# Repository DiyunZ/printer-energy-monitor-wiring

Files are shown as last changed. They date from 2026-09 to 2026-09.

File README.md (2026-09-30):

# Printer energy monitor

Interactive wiring, 3D enclosure layout and materials for one 120 V printer using a DENT ELITEpro XC.

[Website](https://diyunz.github.io/printer-energy-monitor-wiring/) · [Purchase list](https://diyunz.github.io/printer-energy-monitor-wiring/#hardware) · [School purchase request](https://diyunz.github.io/printer-energy-monitor-wiring/purchase-request.html) · [Build documents](https://diyunz.github.io/printer-energy-monitor-wiring/documents.html)

## Local preview

```sh
python3 -m http.server 8770
```

Open [localhost:8770](http://localhost:8770/).

Source files, rebuild commands and checks: [Development guide](docs/DEVELOPMENT.md).

GitHub Pages publishes the repository root on `main`. Hardware checks remain open in the [installation audit](https://diyunz.github.io/printer-energy-monitor-wiring/installation.html).

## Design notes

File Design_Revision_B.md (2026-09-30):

# Selected design, material costs and sellers

**BUD NBF-32226 clear-cover enclosure + Phoenix 2907571 + flat bridge on 65 mm posts. Estimated materials: $273.00 from DigiKey and Home Depot.** Cut and drill only; no bending. Whole purchase packs, minimum order lengths and spare pieces are counted. Shipping, tariffs, sales tax, fabrication and labor are excluded.

## Material total

| Seller | Materials |
|---|---:|
| DigiKey | $175.37 |
| Home Depot | $97.63 |
| **Total** | **$273.00** |

| Change from the previous $233.54 Phoenix plan | Materials change |
|---|---:|
| Clear-cover NBF-32226 $111.88 replaces out-of-stock NBF-32126 $90.81 | +$21.07 |
| Two 65 mm posts $2.78 + four M5 screws $1.95 + eight M5 washers $5.94 | +$10.67 |
| Two Heyco M3231 glands and two 8463 nuts $3.52 replace factory-stock Hammond glands $5.94 | −$2.42 |
| **Net change** | **+$29.32** |

That design revision produced the previous **$262.86** snapshot. The purchase-form verification on September 29 adds **$10.14**, with the same parts and sellers:

| Current price / order correction | Materials change |
|---|---:|
| Black wire: 6 ft × $0.95; green wire: 6 ft × $0.91. Both online minimums are 6 ft; previous estimate used 4 ft × $0.42 per color. | +$7.80 |
| M5 × 10 screws: two 2-piece packs at $2.97, previously $1.25 per pack | +$3.44 |
| M3 × 12 and M4 × 10 screws: two packs each at $1.95, previously $1.75 | +$0.80 |
| SJOOW cord, supply plug and VELCRO roll at current prices | −$1.72 |
| DigiKey 4692 ten-piece tier and current 4705 unit price | −$0.18 |
| **Net change from $262.86** | **+$10.14** |

Q0 remains **$21.57**. The full 250 mm rail is **$4.79** and two stops **$1.24**; breaker plus rail/stops is **$27.60**, included above. The increase purchases a direct-stock transparent-cover box and eliminates sheet bending; it is not an increase in the breaker price. The earlier $246.94 Carling plan used different stock assumptions and three retailers and is not a current like-for-like order.

<h2 id="breaker-options">Selected two-retailer arrangement</h2>

Keep **Phoenix 2907571 / TMC 81C 15A**, 15 A, 1 pole, C curve, UL489 / cUL Listed E320373, 277 V AC, 10 kA. On September 29 DigiKey showed **3,689 direct-stock units at $21.57**; the clear case showed **103 at $111.88**. Factory and Marketplace inventory are excluded. [Q0](https://www.digikey.com/en/products/detail/phoenix-contact/2907571/6109707) · [clear case](https://www.digikey.com/en/products/detail/bud-industries/NBF-32226/2328561).

The flat 88 × 40 mm aluminum bridge uses two purchased M5 posts. The post hardware is additional to the four M5 × 10 panel screws. The actual manufacturer Q0 model sets the front window and terminal approaches; the bridge, posts and rail are placed in the case's 1° wall frame. [Assembly, screw stacks and receiving checks](build.html#q0-mount).

<h2 id="checkout">Price and stock basis</h2>

All 33 unit prices and retailer descriptions were checked September 29 for the selected quantities. Home Depot prices use Champaign / ZIP 61820. **Three cut-to-length wire lines require store pickup; delivery is unavailable.** Arrange collection before submitting the request. Black and green wire orders are 6 ft each to meet the current online minimum; the installation cutting allowance remains 1 m each. $273.00 is a product-page estimate, not a cart quote or reserved stock. Older stock snapshots retain their dates in the [order plan](materials.html#order-plan). No order has been placed. Offered aluminum is counted as no purchased stock; confirm its actual availability and thickness.

The [purchase request page](purchase-request.html) reproduces retailer descriptions and maps selling units to the school menu. Its [Excel download](downloads/purchase-request.xlsx) separates DigiKey and Home Depot. Consumable / under-one-year classification is **Professor to confirm**; the new assembly uses physical goods, so repair/service is No and No Delivery Expected remains unchecked.

## Model and photo evidence

The purchase list uses real product photos; manufacturer family images are labeled. Flat aluminum fabrication parts use labeled CAD drawings. BUD's linked series STEP and Phoenix's exact 2907571 STEP remain at original millimetre scale. Catalog-dimensioned parts and flexible cables are distinguished from manufacturer solids in the dimension schedule. Closed mode renders a genuinely clear cover and opaque walls; X-ray additionally fades the walls. The digital fit checks do not replace full handle travel, receiving measurements or qualified electrical acceptance.

## Certification evidence

| Part | Evidence available | What remains |
|---|---|---|
| BUD NBF-32226 | [Manufacturer listing](https://www.budind.com/product/nema-ip-rated-boxes/nbf-series-fiberglass-enclosure/nbf-32226/): UL508; NEMA 1, 2, 4, 4X for the unmodified enclosure; ABS/PC body UL94-5VA; clear PC lid UL94-V0, indoor use | Confirm received label and exact variant. Machining and custom assembly do not inherit a finished-product listing. |
| Phoenix Contact TMC 81C 15A / 2907571 | [Exact manufacturer product](https://www.phoenixcontact.com/en-us/products/thermomagnetic-device-circuit-breakers-tmc-81c-15a-2907571): UL489 / cUL Listed E320373; 15 A, 1 pole, C curve, 277 V AC, 10 kA | Verify receiving marks, startup suitability, available fault current and original voltage-lead protection. |
| Leviton 515PV / 515CV | [515PV manufacturer page](https://leviton.com/products/515pv) and [515CV](https://leviton.com/products/515cv): UL498 File E13393; CSA C22.2 No.42 File LR-406 | Confirm received markings, approved cord preparation and clamp. |
| Southwire internal wire | [UL/cUL product description](https://www.southwire.com/wire-cable/building-wire/thhn-thwn-copper-silicone-free/p/22955984) | Check markings on actual stock and accepted wiring method. |
| WAGO 221-415 | [Manufacturer datasheet, p.5, distributor-hosted](https://www.netxl.com/wago/docs/221-415-data-sheet.pdf): UL486C cULus Listed E69654; UL467 E201573 | Apply the exact conductor and installation conditions; confirm received marks. Carrier 221-505 is a mechanical accessory. |
| Heyco M3231 + 8463 cordgrips / nuts | [Manufacturer series](https://www.heyco.com/products/liquid-tight-cordgrips/nylon-cordgrips/heyco-tite-liquid-tight-cordgrips-straight-thru-npt-hubs/): UL514B E51579 / CSA 93876; 1/2 NPT, 15.5 mm thread | Accept exact UL cord range, clamp, sealing and locknut engagement. |
| Southwire 558086 cord | [Manufacturer cable specification](https://cabletechsupport.southwire.com/en/tile/1/cable/7386/): UL62 / CSA C22.2 No.49; E46194 / LL90458 | Verify actual jacket marks and installation method. |
| Gardner Bender 15-104 rings | [Exact manufacturer product](https://www.gardnerbender.com/en/p/15-104/-16-14-AWG-2-mm-sq-Bnes-%C3%A0-anneau): UL Listed, CSA Listed, 600 V building wire, 75°C; #8–10 studs and 16–14 AWG | Certification wording is resolved for the replacement. Actual crimp tooling/fit and the aluminum bond still require acceptance; the manufacturer page does not publish a barrel-insulation diameter. |
| Custom aluminum and mechanical restraints | Material/interface review, not standalone equipment certification | Record stock and bonding method; verify retention, stiffness and temperature. Straps are not electrical insulation. |

UL Listed, UL Recognized, a material flammability rating and an IEC standard are different evidence. The website records the specific evidence instead of showing a blanket “certified” badge. No assembled-product certification is claimed.

## Before fabrication and use

The digital checks cover nominal solids, panel insertion, component placement and sampled cable routes. They do not verify actual scrap thickness, connector fit, plug retention, lid access protection or closed-box temperature. Record those checks and electrical acceptance in the [receiving record](build.html#receiving-record). The original voltage leads' protection and aluminum-compatible PE bond remain review items.

[Materials](materials.html) · [Machining and assembly](build.html) · [Protection review](protection.html) · [3D and wiring](index.html)

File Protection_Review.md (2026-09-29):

# Protection and data review

September 28, 2026 · 120 V grounded supply · one printer at a time.

**Q0 and voltage-lead protection still need acceptance.** The checks below resolve published component ratings and fit. Actual outlet fault current, combined startup duty and protection of the existing voltage leads remain unverified. No hardware test or qualified acceptance has been recorded.

| Item | Verified | Decision |
|---|---|---|
| Q0, Phoenix 2907571 | 15 A, 1 pole, C curve; UL489 / cUL Listed E320373; 277 V AC; 10 kA | Selected from DigiKey at a material price of $21.57. Startup and original voltage-lead protection require application acceptance. |
| Voltage tap | A1 connects to JL after Q0; no dedicated fuse | Confirm that upstream Q0 protection is suitable for the original DENT leads before energizing. |
| USB cable | Existing A-to-B cable confirmed owned | Reuse intact through one protected wall opening. Keep its internal portion sleeved and restrained; connect the free USB-A end to the PC only after unplugging mains. |
| Internal adapter power | XA 515CV + original CUI cable, entirely inside | No DC extension or wall feedthrough. Verify plug retention and closed-enclosure temperature. |

The [material-cost comparison](revision.html#breaker-options) includes the breaker, rail, end stops and purchased fastener packs. Shipping, tariffs, sales tax, fabrication and labor are excluded from the selection total. Two sellers remain: DigiKey and Home Depot.

## Q0: what the rating proves

The selected **Phoenix Contact TMC 81C 15A / 2907571** is a 15 A, one-pole, C-curve thermal-magnetic breaker, with UL489 / cUL Listed file E320373, 277 V AC and 10 kA interrupting rating. Its catalog envelope is 17.6 × 116 × 75.9 mm including the DIN rail. The specified screw connection accepts the selected 14 AWG copper conductor; strip 11–12 mm and tighten to 2 N·m. [Phoenix exact product and characteristic curve](https://www.phoenixcontact.com/en-us/products/thermomagnetic-device-circuit-breakers-tmc-81c-15a-2907571).

The former Carling delay-24 pulse specification does **not** apply. Review actual startup amplitude, duration, repetition, ambient temperature and sustained current against Phoenix's published C characteristic. A C-curve label alone is not proof that the printer will start without tripping. Do not raise the 15 A limit to hide nuisance trips.

The application check still needs the **available RMS symmetrical fault current at the actual receptacle** and the combined startup waveform of the selected printer, adapter and logger. An upstream breaker's marked interrupting rating is not a measurement of available fault current. The breaker rating is also not the short-circuit rating of this complete custom enclosure.

### Jackson Innovation Studio

UIUC identifies JIS as **Room 0100, lower level of Sidney Lu Mechanical Engineering Building**. The F&S building list identifies the building as **0112, 1206 W Green St, Urbana**. [MakerWorks location](https://mechse.illinois.edu/undergraduate/makerworks), [F&S building register](https://fs.illinois.edu/building-list-a-z).

The public pages and renovation summaries inspected do not supply the chosen outlet's circuit number, panel schedule or fault-current calculation. That absence is a limit of this public search, not evidence of a safe numerical value. The studio's published contact is **mechse-makerworks@illinois.edu**; it can route a request to the responsible building/facilities staff. [JIS contact page](https://mechse.illinois.edu/undergraduate/makerworks/jackson-innovation-studio).

**Request to pass to JIS / Facilities — draft, not sent:**

> For a proposed 120 V printer-energy measurement box in JIS, Room 0100, could the responsible electrical staff identify the intended receptacle and its panel/circuit, and confirm the maximum available RMS symmetrical fault current there? The proposed breaker is Phoenix TMC 81C 15A / 2907571, 15 A UL489, rated 10 kA at 120 V AC. Please review the complete assembly's protection and supply suitability; the breaker rating alone is not an assembly SCCR. If a current study is unavailable, please advise the appropriate engineering assessment. We do not need to access or open energized panels ourselves.

### Printer startup evidence

| Printer | Published operating information | Limit of the check |
|---|---|---|
| UltiMaker S5 | 100–240 V AC, 50/60 Hz, 500 W maximum | About 4.17 A at 120 V **only at unity power factor**; this is not a nameplate current or startup waveform. [S5 manual](https://um-support-files.ultimaker.com/manuals/user-manual/S3-%26-S5/Ultimaker%20S3-S5%20-%20User%20manual%20ENv2.4.pdf). |
| Bambu Lab P2S | LV version: 100–120 V AC; 1000 W at 110 V during preheating | About 9.09 A at 110 V **only at unity power factor**. Minutes of heating load do not specify millisecond inrush. [P2S quick-start guide](https://csm.bblcdn.com/hub/0a3c3e8ab9554a5c9c91815e41540f42.pdf). |
| Prusa CORE One+ | The listed compatible Gen1 PSU is 24 V DC / 240 W | Its 10 A output is **DC output**, not AC input. Match the actual PSU version; no complete printer inrush waveform was found. [Prusa PSU listing](https://www.prusa3d.com/product/psu-24v-240w/). |

Manufacturer data for startup amplitude, duration, repetitions, input voltage and temperature—or a suitably captured waveform reviewed against the breaker curve—is needed to close the startup comparison. Ordinary logged averages and a single successful power-on do not establish that comparison. Request the actual printer/PSU startup specification; do not increase the breaker rating merely to avoid trips.

## Voltage tap: upstream protection review

The design omits Fv, its holder and JV. The short DIN rail and stops now support Q0 only; they do not add voltage-lead protection. The hot sensing path is **Q0 → JL → original DENT A1 pigtail → full voltage lead → ELITEpro L1**. L2 and N remain connected to neutral. The adapter and voltage tap branch off before CT; only printer hot passes through CT. The sensing leads do not carry printer load current.

The user confirms the three differently colored pigtails as original DENT kit components, matched to the LD-SKTSP family. DENT lists these leads for hard-wiring and also offers standard non-fused and optional fused clips. That does not establish that this custom enclosure and its 15 A breaker adequately protect the original lead set. [DENT pigtails](https://www.dentinstruments.com/shop/elitepro-accessories-replacement-parts/replacement-unterminated-voltage-leads-10-for-elitepro-series/), [DENT clip options](https://www.dentinstruments.com/shop/elitepro-accessories-replacement-parts/replacement-fused-crocodile-clip/).

**Before energizing:** the responsible electrical reviewer must accept the upstream-only protection scheme, original lead terminations and installation conditions. No such acceptance or physical test is recorded. The ELITEpro's internal fuse cannot clear a short in an external lead that bypasses the instrument. Removing Fv does not validate Q0 or establish the assembly's short-circuit rating.

**Manufacturer question — draft, not sent:**

> For our proposed 120 V measurement enclosure, may original DENT LD-SKTSP pigtails and voltage leads connect to a circuit protected by a Phoenix TMC 81C 15A / 2907571 15 A breaker without a dedicated voltage-tap fuse? A1 feeds L1 from switched hot; L2 and N connect to neutral. Please confirm the permitted upstream protection and terminal preparation, or identify any additional protection required. The original 9 V adapter is also powered from the switched circuit.

The [Q0 purchase link](https://www.digikey.com/en/products/detail/phoenix-contact/2907571/6109707) identifies the selected product. Exact-SKU stock, site fault-current suitability and startup behavior remain to be confirmed.

## Experiment data workflow

Use **standalone logging during prints, then offline batch downloads**. Synchronize the logger clock and job/phase timestamps before the series. Keep the same validated interval for comparisons and check memory capacity. Preserve raw exports before clearing memory.

The DENT manual identifies non-volatile memory, included USB and USB-powered readout. It also requires rated insulation for the supplied USB cable inside a powered electrical panel. The user selected closed-lid offline export. One existing cable remains connected to DENT and passes directly through a Heyco 3104 bushing. Disconnect its free exterior USB-A end from the PC before mains operation. The internal portion retains the black FIT-221 600 V sleeve and accepted end protection, restraint and application process. The bushing and sleeve are not a mains isolation barrier. See [USB construction and acceptance](build.html). [DENT manual, printed pp. 7, 18, 29, 119](https://www.dentinstruments.com/wp-content/uploads/EXC_ELOG19_11-15-24.pdf).

Prove the setup with one supervised print cycle and offline export, including startup, phase timestamps, final records and restart behavior, before collecting the experimental series. The website does not claim that physical validation has happened. [Operating sequence](documents.html#operation).

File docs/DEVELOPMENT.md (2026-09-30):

# Development

Run commands from the repository root. The checked-in site can be served with Python alone; Node dependencies are only needed to regenerate documents or run browser checks.

## File map

| Location | Purpose |
|---|---|
| `procurement.json` | Materials, ownership, prices, photos and purchase links |
| `purchasing.rows[].request` in `procurement.json` | Exact retailer Description/title, ordering identifier, matched listing photo and verification date |
| `tools/purchase_request.cjs`, `purchase-request.js`, `purchase-request.css` | Shared purchase-form mapping, generated page and clipboard interaction |
| `tools/export_purchase_request.mjs`, `downloads/purchase-request.xlsx` | Excel generator and its two-vendor download |
| `layout_dimensions.json` | Shared dimensions, placement and provenance |
| `installation_review.json` | Review evidence and outstanding hardware checks |
| `build_routes.py`, `draw_external.py`, `page_template.html` | Generate the main page, circuit drawings, `routes.json` and `validation.json` |
| Root `.js` / `.css` files | Website interactions, 3D geometry and styling |
| Root `.md` files | Engineering documents; BOM, audit and document index are generated |
| `tools/` | Document generators and verification scripts |
| `tools/cad/` | Parametric machining and drawing generators |
| `assets/`, `vendor/` | Model meshes, current material images and licensed Three.js modules |
| `fabrication/` | Published STEP, STL, DXF, SVG and PDF downloads |

Root HTML files and generated artifacts are committed because GitHub Pages serves them directly. Edit their source files and regenerate them. Keep existing page and download URLs working.

## Setup and rebuild

Verified Node dependencies: Node 24, `marked` 17.0.5 and Playwright 1.62.1.

```sh
npm install --no-save --package-lock=false marked@17.0.5 playwright@1.62.1
npx playwright install chromium
python3 build_routes.py
node tools/render_documents.cjs
```

`render_documents.cjs` regenerates `Procurement_BOM.md`, `Installation_Audit.md`, `Build_Documents.md`, `purchase-request.html` and all supporting HTML pages. Other engineering Markdown files are maintained directly.

For the Excel download, use the bundled `@oai/artifact-tool` runtime located by `load_workspace_dependencies`. Create a temporary `node_modules` symlink to that runtime, set `ARTIFACT_WORKDIR` to the temporary directory and run `node tools/export_purchase_request.mjs` using the bundled Node executable. `REQUEST_OUTPUT` optionally sets the artifact output directory. The generator checks calculations and source strings, renders both worksheets for inspection, exports one workbook and copies it to `downloads/purchase-request.xlsx`. Rebuild the workbook and HTML together after changing order fields or prices. `python3 tools/check_purchase_workbook.py` checks the saved export against current procurement data.

Copy DigiKey's **Description**, not Detailed Description, and Home Depot's visible product title without rewording. Record the seller order number separately from the manufacturer/model. Preserve fractional-cent price tiers. Packs and rolls map to the school unit `each`; by-the-foot purchases map to `feet`. Keep the consumable classification unresolved until the professor confirms it. Retailer minimums affect ordered quantities, not installation cutting allowances. Do not use a new description-check date to relabel an old stock snapshot as current.

## Checks

```sh
python3 -m unittest -v test_routes.py test_material_locations.py
node --test tools/test_installation.mjs tools/test_cable_supports.mjs tools/test_purchase_request.mjs
python3 -m http.server 8770
```

With the server running, use a second terminal:

```sh
export CHECK_URL=http://127.0.0.1:8770/
export QA_OUTPUT=../outputs/website-checks
node tools/verify_site.cjs
```

Run focused browser checks when their features change:

| Script | Coverage |
|---|---|
| `tools/verify_material_locator.cjs` | Material links, mesh ownership, locations and navigation |
| `tools/verify_wiring.cjs` | Circuit labels, endpoints, pan, zoom and fullscreen |
| `tools/verify_usb_service.cjs` | Closed-lid USB export workflow and connector links |
| `tools/verify_cable_geometry.cjs` | Supports, cable separation, CT passage and cord breakouts |

After geometry changes, `node tools/audit_installation.mjs` refreshes `installation_checks.json`. On the local server, `EXPORT_AUDIT=1` with `verify_site.cjs` or `verify_cable_geometry.cjs` refreshes the corresponding cable report; `EXPORT_DRAWINGS=1` with `verify_site.cjs` refreshes the two PNG drawings. Rerun `render_documents.cjs` after updating audit data. Review generated diffs before committing.

## CAD regeneration

Use Python 3.12 with `build123d==0.11.1`, `ezdxf` and `matplotlib` in a separate environment. Obtain the factory STEP linked on the [BUD NBF-32226 page](https://www.budind.com/product/nema-ip-rated-boxes/nbf-series-fiberglass-enclosure/nbf-32226/). The original vendor file is also saved at `fabrication/bud-nbf32226-reference.step`; its internal filename is hbnbf32026.step. Preserve its hash and original scale.

```sh
python tools/cad/enclosure_model.py --source-step /path/to/NBF-32226.step
python tools/cad/draw_fabrication.py
```

The generator writes the machined solids, assembly meshes (including the flat Q0 bridge, two catalog-dimensioned posts and Phoenix factory model), exact clearance checks and `fabrication/cad-manifest.json` with source/generator/output hashes.

The two end stops use `fabrication/altech-ca802-reference.step` at original scale. OpenCascade reads its CompSolid through `STEPControl_Reader`; the original topology is not valid, so the mesh is visual only and excluded from exact-solid fit checks. The rail seat remains provisional. Do not silently heal or scale vendor geometry to force a pass.

The separate support source is `tools/cad/q0_mount_model.py`, reading `layout_dimensions.json:q0Mount`. With the installed lab-hardware-cad skill, export and independently check its STEP as follows (the skill path can be changed for another workstation):

```sh
python ~/.codex/skills/lab-hardware-cad/scripts/gen.py tools/cad/q0_mount_model.py --outdir fabrication
python ~/.codex/skills/lab-hardware-cad/scripts/check.py geometry fabrication/q0_mount.step --model tools/cad/q0_mount_model.py
```

The sixth drawing and flat DXF are regenerated by `draw_fabrication.py`. The flat bridge needs only cutting and drilling; no bend radius or K-factor is used. Measure actual sheet and washer thicknesses and dry-fit the post/screw stack before machining.

Inspect regenerated CAD and drawings before publication. Software checks do not replace the receiving, fit and electrical checks in the [installation audit](../Installation_Audit.md).

Phoenix factory STEP is preserved at `fabrication/phoenix-2907571-reference.step`; the original vendor SHA256 is recorded in the manifests. Q0 is transformed without scaling into the wall frame. Terminal channels in `layout_dimensions.json` bound the cable-screen exception; independent 3.4 mm wire gauges check the actual manufacturer cavities. Clearance booleans use non-destructive OpenCascade common operations to avoid cleanup artifacts in vendor topology.

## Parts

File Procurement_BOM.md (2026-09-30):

# Materials checklist

**□ 19 purchase groups · ◇ 2 reuse / fabrication group · ✓ 6 confirmed owned groups**

One grounded 120 V supply, one printer at a time. The design uses a clear-cover BUD NBF-32226 enclosure, proposed reuse of the professor’s aluminum sheet and an internal adapter connection. Six owned equipment groups, including the existing USB cable, are retained. The selected 15 A Q0 and upstream-only voltage-lead protection still require application acceptance. No purchase, physical fit, thermal test or electrical release is claimed. Closed-lid USB export is used only after unplugging mains; the internal portion of the existing USB cable requires rated insulation and accepted assembly.

**Inventory basis:** Six equipment groups are confirmed owned by the user: ELITEpro XC, CTs, three original kit pigtails, matching long voltage leads, original adapter and USB data cable. Reuse the existing USB cable intact. The design uses published USB-B overmold limits and a standard cable-diameter range; final passage, insulation and restraint are checked during assembly.

A check means on hand, not electrically approved. Counts refer to material groups, not individual pieces. Needed quantities and vendor pack sizes differ. The user confirms the existing USB cable is owned. Reuse it intact; no additional data cable or USB coupler is ordered.

Buy links go to specific products; Select / Configure links need a size or rating first; Quote links require a supplier quote. Reused stock and fabrication are listed separately from purchases. Check current stock, minimum orders and lead times with each supplier. No orders have been placed.

**[Prepare the school purchase request](purchase-request.html)** — exact retailer descriptions, per-field copy buttons and a [two-vendor Excel download](downloads/purchase-request.xlsx).

Purchased groups show real manufacturer or distributor product photos. Family photos are identified; the two custom aluminum parts use labeled CAD drawings. Photos are not to scale; the 3D layout uses millimetres. Click an image to view the original. Use **View in 3D** to highlight each material’s installation locations. Image sources are credited below each picture.

<h2 id="order-plan">Priced order plan · $273.00 materials</h2>

Checked 2026-09-29. Materials only, including whole packs, minimum order lengths and spare pieces. All unit prices rechecked September 29 at the selected quantities; Home Depot uses Champaign / ZIP 61820. Shipping, tariffs, sales tax, fabrication and labor are excluded. Stock snapshots retain their separate per-line dates.

Two sellers only: DigiKey and Home Depot. Selected DigiKey parts must be DigiKey direct stock; Marketplace, manufacturer direct shipping and factory-only stock are excluded. No fee per retailer is added.

| Seller / exact item | Quantity to enter | Unit price (USD) | Line total (USD) | Availability / packaging |
|---|---|---|---|---|
| DigiKey · [NBF-32226](https://www.digikey.com/en/products/detail/bud-industries/NBF-32226/2328561) | 1 each | $111.88<br>Price checked 2026-09-29 | $111.88 | 103 in DigiKey direct stock; 377-1789-ND; clear PC cover. Stock / packaging note dated 2026-09-29. |
| DigiKey · [2907571 · TMC 81C 15A](https://www.digikey.com/en/products/detail/phoenix-contact/2907571/6109707) | 1 each | $21.57<br>Price checked 2026-09-29 | $21.57 | 3,689 in DigiKey direct stock, quantity-one price; factory stock excluded. Stock / packaging note dated 2026-09-29. |
| Home Depot · [515CV](https://www.homedepot.com/p/301304939) | 2 each | $6.99<br>Price checked 2026-09-29 | $13.98 | One internal XA and one printer output; buy two total Stock / packaging note dated 2026-09-23. |
| DigiKey · [221-415](https://www.digikey.com/en/products/detail/wago-corporation/221-415/13549457) | 3 each | $1.17<br>Price checked 2026-09-29 | $3.51 | 171,735 listed in stock; 2946-221-415-ND Stock / packaging note dated 2026-09-23. |
| DigiKey · [221-505](https://www.digikey.com/en/products/detail/wago-corporation/221-505/15568477) | 3 each | $2.23<br>Price checked 2026-09-29 | $6.69 | 2,982 listed in stock; 2946-221-505-ND Stock / packaging note dated 2026-09-23. |
| Home Depot · [55808699 · 14/3 SJOOW](https://www.homedepot.com/p/Southwire-By-the-Foot-14-3-300-Volt-CU-Black-Flexible-Portable-Power-SJOOW-Cord-55808699/204633006) | 13 ft | $1.46<br>Price checked 2026-09-29 | $18.98 | Minimum 6 ft; order one continuous 13 ft length. Champaign pickup only; delivery unavailable for ZIP 61820. Stock / packaging note dated 2026-09-29. |
| Home Depot · [515PV-YL](https://www.homedepot.com/p/Leviton-15-Amp-125-Volt-3-Wire-Plug-Yellow-515PV-YL-R10-515PV-0YL/309610976) | 1 each | $3.65<br>Price checked 2026-09-29 | $3.65 | Store / delivery availability varies Stock / packaging note dated 2026-09-23. |
| DigiKey · [M3231 · long-thread 1/2 NPT cordgrip](https://www.digikey.com/en/products/detail/heyco-products-corporation/M3231/15906457) | 2 each | $1.44<br>Price checked 2026-09-29 | $2.88 | 13,830 DigiKey direct stock; separate 8463 locknut required. Stock / packaging note dated 2026-09-29. |
| Home Depot · [22955999 · black 14 AWG stranded](https://www.homedepot.com/p/204632031) | 6 ft | $0.95<br>Price checked 2026-09-29 | $5.70 | Minimum online order 6 ft; one continuous length, with spare wire beyond the 1 m cutting allowance. Champaign pickup only; delivery unavailable for ZIP 61820. Stock / packaging note dated 2026-09-29. |
| Home Depot · [22959199 · green 14 AWG stranded](https://www.homedepot.com/p/204632154) | 6 ft | $0.91<br>Price checked 2026-09-29 | $5.46 | Minimum online order 6 ft; one continuous length, with spare wire beyond the 1 m cutting allowance. Champaign pickup only; delivery unavailable for ZIP 61820. Stock / packaging note dated 2026-09-29. |
| Home Depot · [15-104 · 15 terminals](https://www.homedepot.com/p/202522492) | 1 pack (15 pieces per pack) | $3.63<br>Price checked 2026-09-29 | $3.63 | 15 pieces supplied for a single pack price Stock / packaging note dated 2026-09-23. |
| DigiKey · [TM2S8-C](https://www.digikey.com/en/products/detail/panduit-corp/TM2S8-C/1306625) | 6 each | $0.68<br>Price checked 2026-09-29 | $4.08 | 14,724 listed in stock; 298-10245-ND; individual pieces Stock / packaging note dated 2026-09-23. |
| DigiKey · [PLT2S-C](https://www.digikey.com/en/products/detail/panduit-corp/PLT2S-C/280043) | 10 each | $0.316<br>Price checked 2026-09-29 | $3.16 | 113,092 listed in stock; 298-1030-ND; ten-piece price tier Stock / packaging note dated 2026-09-23. |
| Home Depot · [90340 · 12 ft × 3/4 in](https://www.homedepot.com/p/202261925) | 1 roll | $10.27<br>Price checked 2026-09-29 | $10.27 | One roll supplies four blanks totaling 1.30 m Stock / packaging note dated 2026-09-23. |
| Home Depot · [837761 · M3-0.5 × 12 zinc pan screws](https://www.homedepot.com/p/321071719) | 2 pack (4 pieces per pack) | $1.95<br>Price checked 2026-09-29 | $3.90 | 6 carrier fixings installed; buy 8, retain 2 spare. Q0 now uses M5 posts. Stock / packaging note dated 2026-09-24. |
| DigiKey · [4692 · M3 / #4 zinc-plated steel flat washers](https://www.digikey.com/en/products/detail/keystone-electronics/4692/316261) | 10 each | $0.084<br>Price checked 2026-09-29 | $0.84 | 6 carrier washers installed; retain 4 spare from the ten-piece price tier. Stock / packaging note dated 2026-09-23. |
| Home Depot · [837221 · M3-0.5 stainless locknuts](https://www.homedepot.com/p/321071866) | 2 pack (4 pieces per pack) | $1.95<br>Price checked 2026-09-29 | $3.90 | 6 carrier fixings installed; buy 8, retain 2 spare. Q0 now uses M5 posts. Stock / packaging note dated 2026-09-23. |
| Home Depot · [836351 · M4-0.7 × 10 zinc pan screws](https://www.homedepot.com/p/321071623) | 2 pack (4 pieces per pack) | $1.95<br>Price checked 2026-09-29 | $3.90 | 6 cable anchors + 1 DIN rail fixing; 8 purchased, 7 installed. Stock / packaging note dated 2026-09-24. |
| Home Depot · [4118 · M4 stainless flat washers](https://www.homedepot.com/p/204801237) | 1 pack (50 pieces per pack) | $4.96<br>Price checked 2026-09-29 | $4.96 | 6 anchor washers + 3 rail spacer/head/nut washers; 50-piece pack covers all. Stock / packaging note dated 2026-09-23. |
| Home Depot · [837171 · M4-0.7 stainless locknuts](https://www.homedepot.com/p/321071795) | 2 pack (4 pieces per pack) | $1.95<br>Price checked 2026-09-29 | $3.90 | 6 cable anchors + 1 DIN rail fixing; 8 purchased, 7 installed. Stock / packaging note dated 2026-09-23. |
| DigiKey · [9911 · #10-32 × 3/4 stainless pan screws](https://www.digikey.com/en/products/detail/keystone-electronics/9911/317331) | 2 each | $0.39<br>Price checked 2026-09-29 | $0.78 | Two dedicated #10 bond studs: panel and Q0 rail/bracket. Stock / packaging note dated 2026-09-23. |
| DigiKey · [4705 · #10-32 zinc-plated steel plain nuts](https://www.digikey.com/en/products/detail/keystone-electronics/4705/316276) | 4 each | $0.12<br>Price checked 2026-09-29 | $0.48 | Two PE bond stacks; all 4 purchased pieces installed. Stock / packaging note dated 2026-09-23. |
| Home Depot · [827311 · #10 zinc-plated external-tooth washers](https://www.homedepot.com/p/317479556) | 1 pack (18 pieces per pack) | $1.57<br>Price checked 2026-09-29 | $1.57 | 5 PE-stud contacts + 6 proposed M5 post contact/retention washers; 18-piece pack. Verify M5 fit and approved bonding stack. Stock / packaging note dated 2026-09-23. |
| DigiKey · [4703 · #10 zinc-plated steel flat washers](https://www.digikey.com/en/products/detail/keystone-electronics/4703/316274) | 4 each | $0.13<br>Price checked 2026-09-29 | $0.52 | Two PE bond stacks; all 4 purchased pieces installed. Stock / packaging note dated 2026-09-23. |
| Home Depot · [863468 · M5-0.8 × 10 stainless pan screws](https://www.homedepot.com/p/323370995) | 2 pack (2 pieces per pack) | $2.97<br>Price checked 2026-09-29 | $5.94 | Panel mounting; 4 screws supplied and installed. Not included with the enclosure. Store price / delivery varies by location. Stock / packaging note dated 2026-09-24. |
| DigiKey · [F2213/4 BK105](https://www.digikey.com/en/products/detail/alpha-wire/F2213-4-BK105/3718418) | 1 each | $9.39<br>Price checked 2026-09-29 | $9.39 | F2213/4BK105-ND; 1,182 listed in stock; one 4 ft stick Stock / packaging note dated 2026-09-23. |
| DigiKey · [Heyco 3104](https://www.digikey.com/en/products/detail/heyco-products-corporation/3104/15907204) | 1 each | $0.14<br>Price checked 2026-09-29 | $0.14 | 3720-3104-ND; 6,537 listed in stock; quantity-one price. Verify actual passage and stock at checkout. Stock / packaging note dated 2026-09-23. |
| DigiKey · [1207639 · NS 35/7.5 PERF 250MM](https://www.digikey.com/en/products/detail/phoenix-contact/1207639/10645207) | 1 each | $4.79<br>Price checked 2026-09-29 | $4.79 | 2,061 in DigiKey direct stock; buy full 250 mm rail, cut 60 mm. Stock / packaging note dated 2026-09-29. |
| DigiKey · [CA802](https://www.digikey.com/en/products/detail/altech-corporation/CA802/8547037) | 2 each | $0.62<br>Price checked 2026-09-29 | $1.24 | 6,001 in DigiKey direct stock; two 8 mm end stops. Stock / packaging note dated 2026-09-29. |
| DigiKey · [8463 · 1/2 NPT nylon locknut](https://www.digikey.com/en/products/detail/heyco-products-corporation/8463/15906932) | 2 each | $0.32<br>Price checked 2026-09-29 | $0.64 | 66,153 in DigiKey direct stock; one per M3231. Stock / packaging note dated 2026-09-29. |
| DigiKey · [970650581 · 65 mm M5 steel post](https://www.digikey.com/en/products/detail/w%C3%BCrth-elektronik/970650581/6174896) | 2 each | $1.39<br>Price checked 2026-09-29 | $2.78 | 67 in DigiKey direct stock; 11 mm internal thread per end. Stock / packaging note dated 2026-09-29. |
| Home Depot · [836521 · M5-0.8 × 12 zinc pan screws](https://www.homedepot.com/p/321071519) | 1 pack (4 pieces per pack) | $1.95<br>Price checked 2026-09-29 | $1.95 | Champaign: 8 packs in stock; four screws installed. Stock / packaging note dated 2026-09-29. |
| Home Depot · [864408 · M5 stainless flat washers](https://www.homedepot.com/p/323371831) | 2 pack (4 pieces per pack) | $2.97<br>Price checked 2026-09-29 | $5.94 | Champaign: 4 packs in stock; buy 8 washers, install 6. Stock / packaging note dated 2026-09-29. |

| Seller | Materials subtotal (USD) |
|---|---|
| DigiKey | $175.37 |
| Home Depot | $97.63 |
| **All selected materials** | **$273.00** |

The two 515CV installation rows below share the **single two-piece order line above**. Do not order two for each location. Aluminum stock and electrical acceptance remain open; see the [receiving record](build.html#receiving-record).

**Selection total: $273.00 in materials from 2 sellers.** Compare material costs while minimizing the number of actual sellers. Shipping, tariffs, sales tax, fabrication and labor are excluded. [Material costs and seller comparison](revision.html#breaker-options).

<h2 id="purchase-list">□ Purchase list · 19 groups</h2>

Prices checked 2026-09-29; subtotals include purchase packs and spares. Shared 515CV stock is allocated as one connector per location. [Full order quantities and seller totals](#order-plan).

| Inventory | Item | Quantity needed | Part and purpose | Price & purchase (USD) | Remaining checks |
|---|---|---|---|---|---|
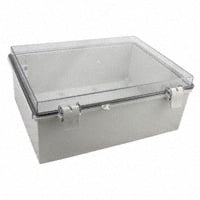
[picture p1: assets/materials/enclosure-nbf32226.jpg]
BUD NBF-32226 clear-cover enclosure — distributor product photo
| □ To buy | <span class="material-name">Enclosure</span><div class="material-gallery"><figure class="material-photo" data-image-kind="product"><figcaption>BUD NBF-32226 clear-cover enclosure — distributor product photo<a href="https://www.digikey.com/en/products/detail/bud-industries/NBF-32226/2328561">Image: DigiKey / manufacturer ↗</a></figcaption></figure></div><a class="locate-material" data-material="enclosure" href="index.html?material=enclosure#layout" aria-label="View Enclosure in 3D">View in 3D ↑</a> | 1 | **BUD NBF-32226 · clear hinged cover** — 400 × 300 × 160 mm ABS/PC box with a clear polycarbonate cover. Same manufacturer base and panel pattern; the exact factory STEP is displayed without scaling. | <div class="material-price" data-material-id="enclosure" data-subtotal-usd="111.88"><strong class="price-total">$111.88</strong> <span class="price-label">subtotal</span><div class="price-breakdown"><p>1 × $111.88 each</p></div></div>[Buy · DigiKey](https://www.digikey.com/en/products/detail/bud-industries/NBF-32226/2328561)<br>[BUD product / standards](https://www.budind.com/product/nema-ip-rated-boxes/nbf-series-fiberglass-enclosure/nbf-32226/)<br>[BUD dimensional drawing](https://www.budind.com/wp-content/uploads/2019/01/hbnbf32226.pdf) | 103 in DigiKey direct stock at $111.88, checked September 29, 2026. Reconfirm at checkout. Received-part fit, latches, access protection and machining acceptance remain required.<br>**Manufacturer listing:** Manufacturer UL508 listing; NEMA 1, 2, 4, 4X for the unmodified enclosure. ABS/PC body UL94-5VA; clear PC door UL94-V0. Machining does not confer a finished-assembly or ingress rating. [Evidence](https://www.budind.com/product/nema-ip-rated-boxes/nbf-series-fiberglass-enclosure/nbf-32226/) |
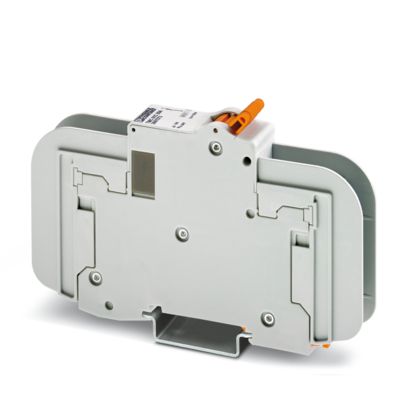
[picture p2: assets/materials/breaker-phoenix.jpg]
Phoenix Contact TMC 81 single-pole breaker family product photo
| □ To buy | <span class="material-name">Q0 operating breaker</span><div class="material-gallery"><figure class="material-photo" data-image-kind="product"><figcaption>Manufacturer family photo; confirm 2907571 / 15 A marking on receipt.<a href="https://www.phoenixcontact.com/en-us/products/thermomagnetic-device-circuit-breakers-tmc-81c-15a-2907571">Image: Phoenix Contact product photo ↗</a></figcaption></figure></div><a class="locate-material" data-material="breaker" href="index.html?material=breaker#layout" aria-label="View Q0 operating breaker in 3D">View in 3D ↑</a> | 1 | **Phoenix Contact TMC 81C 15A · 2907571** — 15 A, one pole, C curve, UL489 / cUL Listed E320373; 10 kA, 277 V AC. Consolidates the breaker into the existing DigiKey order. Manufacturer STEP defines the wall opening, short DIN rail and bonded aluminum bracket. Review the thermal-magnetic curve against startup and original voltage-lead protection. | <div class="material-price" data-material-id="breaker" data-subtotal-usd="21.57"><strong class="price-total">$21.57</strong> <span class="price-label">subtotal</span><div class="price-breakdown"><p>1 × $21.57 each</p></div></div>[Buy 1 · DigiKey · $21.57](https://www.digikey.com/en/products/detail/phoenix-contact/2907571/6109707)<br>[Phoenix specifications, approvals and C curve](https://www.phoenixcontact.com/en-us/products/thermomagnetic-device-circuit-breakers-tmc-81c-15a-2907571)<br>[Manufacturer STEP reference](fabrication/phoenix-2907571-reference.step)<br>[Material costs and seller comparison](revision.html#breaker-options) | DigiKey direct-stock price $21.57, rechecked September 29, 2026. Reconfirm stock at checkout. Full mounting hardware is included in the materials-only total.<br>**UL489 / cUL Listed:** Exact 2907571 product: UL / cUL Listed file E320373, 15 A C curve, 277 V AC, 10 kA. Confirm received markings and application. Component listing is not assembly approval. [Evidence](https://www.phoenixcontact.com/en-us/products/thermomagnetic-device-circuit-breakers-tmc-81c-15a-2907571) |
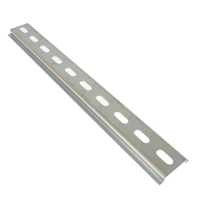
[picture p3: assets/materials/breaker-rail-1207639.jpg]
Phoenix 1207639 — purchased 250 mm rail; cut 60 mm
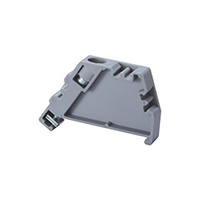
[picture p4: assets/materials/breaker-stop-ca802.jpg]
Altech CA802 — two end stops
| □ To buy | <span class="material-name">Q0 DIN rail and end stops</span><div class="material-gallery"><figure class="material-photo" data-image-kind="product"><figcaption>Phoenix 1207639 — purchased 250 mm rail; cut 60 mm<a href="https://www.digikey.com/en/products/detail/phoenix-contact/1207639/10645207">Image: DigiKey / manufacturer ↗</a></figcaption></figure><figure class="material-photo" data-image-kind="product"><figcaption>Altech CA802 — two end stops<a href="https://www.digikey.com/en/products/detail/altech-corporation/CA802/8547037">Image: DigiKey / manufacturer ↗</a></figcaption></figure></div><a class="locate-material" data-material="breaker-rail" href="index.html?material=breaker-rail#layout" aria-label="View Q0 DIN rail and end stops in 3D">View in 3D ↑</a> | 1 × 250 mm rail; cut 60 mm, plus 2 end stops | **Phoenix Contact 1207639 + Altech CA802 × 2** — 35 × 7.5 × 1 mm galvanized steel rail. Buy the complete 250 mm piece for $4.79; two $0.62 CA802 stops restrain the breaker laterally. The short stock avoids adding a one-metre package to the enclosure shipment. | <div class="material-price" data-material-id="breaker-rail" data-subtotal-usd="6.03"><strong class="price-total">$6.03</strong> <span class="price-label">subtotal</span><div class="price-breakdown"><p><span class="price-sku">1207639 · NS 35/7.5 PERF 250MM</span>1 × $4.79 each = $4.79</p><p><span class="price-sku">CA802</span>2 × $0.62 each = $1.24</p></div></div>[250 mm rail · DigiKey · $4.79](https://www.digikey.com/en/products/detail/phoenix-contact/1207639/10645207)<br>[2 end stops · DigiKey · $0.62 each](https://www.digikey.com/en/products/detail/altech-corporation/CA802/8547037)<br>[Altech stop dimensions](https://legacy.altechcorp.com/Blocks/Block-Accessories.pdf)<br>[CA802 manufacturer STEP (1:1 visual reference)](fabrication/altech-ca802-reference.step) | September 29 direct stock: 2,061 rails and 6,001 stops; $4.79 + 2 × $0.62 = $6.03. Cut and deburr the rail before fitting.<br>**Mechanical accessories:** Manufacturer rail geometry and CA802 compatibility; no separate branch protection function or assembly certification. [Evidence](build.html#q0-mount) |
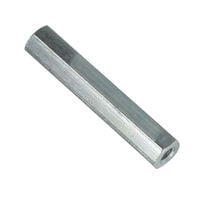
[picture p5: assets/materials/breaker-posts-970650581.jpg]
Würth WA-SSTII family product photo; ordered 970650581 is 65 mm, M5
| □ To buy | <span class="material-name">Q0 threaded support posts</span><div class="material-gallery"><figure class="material-photo" data-image-kind="reference"><figcaption>Würth WA-SSTII family product photo; ordered 970650581 is 65 mm, M5<a href="https://www.digikey.com/en/products/detail/w%C3%BCrth-elektronik/970650581/6174896">Image: DigiKey / manufacturer ↗</a></figcaption></figure></div><a class="locate-material" data-material="breaker-posts" href="index.html?material=breaker-posts#layout" aria-label="View Q0 threaded support posts in 3D">View in 3D ↑</a> | 2 | **Würth 970650581 · M5 female/female · 65 mm** — Two zinc-plated steel SW8 hex posts hold the flat bridge at the required DIN-rail depth. M5 internal thread depth 11 mm per end; no bending or tapping required. | <div class="material-price" data-material-id="breaker-posts" data-subtotal-usd="2.78"><strong class="price-total">$2.78</strong> <span class="price-label">subtotal</span><div class="price-breakdown"><p>2 × $1.39 each</p></div></div>[Buy 2 · DigiKey](https://www.digikey.com/en/products/detail/w%C3%BCrth-elektronik/970650581/6174896)<br>[Würth dimensional drawing](https://www.we-online.com/components/products/datasheet/970xxxxx1_overview.pdf) | 67 in DigiKey direct stock; $1.39 each, checked September 29, 2026. Verify screw engagement, wall loading and accepted PE continuity through the metal support.<br>**Mechanical support:** Published dimensions; PE contact and mechanical retention are assembly acceptance items. [Evidence](build.html#q0-mount) |
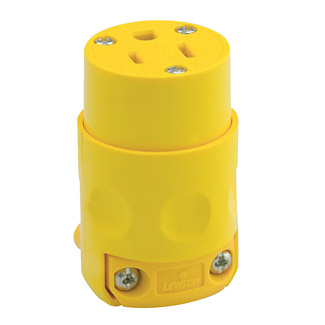
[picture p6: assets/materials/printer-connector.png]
Leviton 515CV · NEMA 5-15R — product image
| □ To buy | <span class="material-name">XA adapter receptacle</span><div class="material-gallery"><figure class="material-photo" data-image-kind="product"><figcaption>Product image<a href="https://leviton.com/products/515cv">Image: Leviton ↗</a></figcaption></figure></div><a class="locate-material" data-material="receptacle" href="index.html?material=receptacle#layout" aria-label="View XA adapter receptacle in 3D">View in 3D ↑</a> | 1 | **Leviton 515CV · internal NEMA 5-15R** — Use a complete cord connector inside the box, matching the printer output connector SKU. A dedicated 14/3 SJOOW branch connects JL/JN/PE to XA upstream of CT. The connector body encloses its terminals and clamps the cord jacket. No wall outlet, custom bracket or wall cutout. | <div class="material-price" data-material-id="receptacle" data-subtotal-usd="6.99"><strong class="price-total">$6.99</strong> <span class="price-label">subtotal</span><div class="price-breakdown"><p>1 × $6.99 each</p></div></div>[Buy · Home Depot · 1 of 2 total](https://www.homedepot.com/p/301304939)<br>[Leviton 515CV](https://leviton.com/products/515cv)<br>[Leviton dimensions](https://leviton.com/content/dam/leviton/residential/product_documents/none/Document-31435-Dimensional%20Data.jpg)<br>[Leviton cord instructions](https://leviton.com/content/dam/leviton/residential/product_documents/instruction_sheet/515_Instruction_Sheet.pdf) | Catalog UL498 File E13393 / CSA LR-406. Verify the cord clamp and secure both XA and the adapter on the panel; plugs remain fully seated.<br>**Manufacturer file identified:** UL498 File E13393; CSA C22.2 No.42 File LR-406. [Evidence](https://leviton.com/products/515cv) |
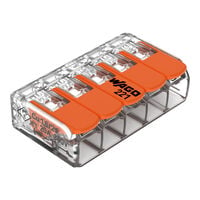
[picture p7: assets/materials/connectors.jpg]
WAGO 221-415 — product image
| □ To buy | <span class="material-name">Distribution connectors</span><div class="material-gallery"><figure class="material-photo" data-image-kind="product"><figcaption>Product image<a href="https://www.digikey.com/en/products/detail/wago-corporation/221-415/13549457">Image: DigiKey ↗</a></figcaption></figure></div><a class="locate-material" data-material="connectors" href="index.html?material=connectors#layout" aria-label="View Distribution connectors in 3D">View in 3D ↑</a> | 3 | **WAGO 221-415** — One five-port connector each for JL, JN and PE. JL accepts Q0 output, printer hot, A1 and adapter hot; JN accepts supply, printer, A2, A3 and adapter neutrals; PE accepts supply, printer, panel, outlet and Q0-mount earth (all five PE ports used). One accepted conductor per port. Confirm original DENT pigtail preparation and protective-bonding suitability. | <div class="material-price" data-material-id="connectors" data-subtotal-usd="3.51"><strong class="price-total">$3.51</strong> <span class="price-label">subtotal</span><div class="price-breakdown"><p>3 × $1.17 each</p></div></div>[Buy · DigiKey](https://www.digikey.com/en/products/detail/wago-corporation/221-415/13549457)<br>[WAGO](https://www.wago.com/us/wire-splicing-connectors/compact-splicing-connector/p/221-415) | Three mounting positions in the panel drawing. Conductor acceptance is checked at assembly.<br>**Manufacturer certificate table:** WAGO 221-415 datasheet (2024), p.5: cULus Listed UL 486C, E69654; UL 467 grounding, E201573. Confirm supplied part and installation conditions. [Evidence](https://www.netxl.com/wago/docs/221-415-data-sheet.pdf) |
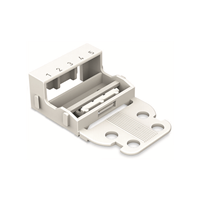
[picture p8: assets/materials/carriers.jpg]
WAGO 221-505 — reference image
| □ To buy | <span class="material-name">Connector carriers</span><div class="material-gallery"><figure class="material-photo" data-image-kind="reference"><figcaption>221-505 product image.<a href="https://www.digikey.com/en/products/detail/wago-corporation/221-505/15568477">Image: DigiKey ↗</a></figcaption></figure></div><a class="locate-material" data-material="carriers" href="index.html?material=carriers#layout" aria-label="View Connector carriers in 3D">View in 3D ↑</a> | 3 | **WAGO 221-505** — Secure each connector to the backpanel with its carrier. Carrier details are schematic; transfer-drill from received parts. Connectors must not rely on wires for support. | <div class="material-price" data-material-id="carriers" data-subtotal-usd="6.69"><strong class="price-total">$6.69</strong> <span class="price-label">subtotal</span><div class="price-breakdown"><p>3 × $2.23 each</p></div></div>[Buy · DigiKey](https://www.digikey.com/en/products/detail/wago-corporation/221-505/15568477)<br>[WAGO](https://www.wago.com/us/wire-splicing-connectors/mounting-carrier-221-series-24-12-awg/p/221-505)<br>[WAGO carrier drawing](https://www1.futureelectronics.com/doc/WAGO/221-505.pdf) | Three carriers, two M3 fixings each; transfer-drill actual front-foot holes.<br>**Mechanical accessory:** Verify mechanical/material suitability; this accessory does not provide mains insulation or confer assembly certification. [Evidence](https://www.wago.com/us/wire-splicing-connectors/mounting-carrier-221-series-24-12-awg/p/221-505) |
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

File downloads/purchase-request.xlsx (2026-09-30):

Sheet: DigiKey
Purchase request · DigiKey
Vendor materials subtotal (USD) |  |  |  | $175.37 | Shipping, tariffs, tax, fabrication and labor excluded.
One vendor per request. Quantity counts selling units; each can mean one complete pack or roll.
Professor to confirm consumable classification. Review collection notes before submitting.
Quantity | Units | Price (USD / unit) | Catalog/Part # | Description | Item URL | Is this item consumable or be in use for less than 1 year before disposal? | Is this a repair part or service? | No Delivery Expected | Line total (USD) | Selling unit / package contents | Collection / fulfillment | Manufacturer / Model # | Price checked | Description checked
1 | each | 111.88 | 377-1789-ND | BOX ABS/PC 15.74"L X 11.81"W | https://www.digikey.com/en/products/detail/bud-industries/NBF-32226/2328561 | Professor to confirm | No | Unchecked | $111.88 | One individual item per each. |  | NBF-32226 | 2026-09-29 | 2026-09-29
1 | each | 21.57 | 277-11849-ND | CIR BRKR 15A 277VAC 60VDC | https://www.digikey.com/en/products/detail/phoenix-contact/2907571/6109707 | Professor to confirm | No | Unchecked | $21.57 | One individual item per each. |  | 2907571 | 2026-09-29 | 2026-09-29
3 | each | 1.17 | 2946-221-415-ND | SPLICE LEVER 24-12AWG 5POS | https://www.digikey.com/en/products/detail/wago-corporation/221-415/13549457 | Professor to confirm | No | Unchecked | $3.51 | One individual item per each. |  | 221-415 | 2026-09-29 | 2026-09-29
3 | each | 2.23 | 2946-221-505-ND | CARRIER SCREW MNT 5POS WHITE | https://www.digikey.com/en/products/detail/wago-corporation/221-505/15568477 | Professor to confirm | No | Unchecked | $6.69 | One individual item per each. |  | 221-505 | 2026-09-29 | 2026-09-29
2 | each | 1.44 | 3720-M3231-ND | CABLE GRIP 4.32-11.43MM 1/2" NPT | https://www.digikey.com/en/products/detail/heyco-products-corporation/M3231/15906457 | Professor to confirm | No | Unchecked | $2.88 | One individual item per each. |  | M3231 | 2026-09-29 | 2026-09-29
6 | each | 0.68 | 298-10245-ND | CABLE TIE HLDR DUAL SCREW #8 NAT | https://www.digikey.com/en/products/detail/panduit-corp/TM2S8-C/1306625 | Professor to confirm | No | Unchecked | $4.08 | One individual item per each. |  | TM2S8-C | 2026-09-29 | 2026-09-29
10 | each | 0.316 | 298-1030-ND | CBL TIE LOCKING NAT 50LB 7.40" | https://www.digikey.com/en/products/detail/panduit-corp/PLT2S-C/280043 | Professor to confirm | No | Unchecked | $3.16 | One individual item per each. |  | PLT2S-C | 2026-09-29 | 2026-09-29
10 | each | 0.084 | 36-4692-ND | WASHER FLAT #4 STEEL | https://www.digikey.com/en/products/detail/keystone-electronics/4692/316261 | Professor to confirm | No | Unchecked | $0.84 | One individual item per each. |  | 4692 | 2026-09-29 | 2026-09-29
2 | each | 0.39 | 36-9911-ND | MACH SCREW PAN PHILLIPS #10-32 | https://www.digikey.com/en/products/detail/keystone-electronics/9911/317331 | Professor to confirm | No | Unchecked | $0.78 | One individual item per each. |  | 9911 | 2026-09-29 | 2026-09-29
4 | each | 0.12 | 36-4705-ND | NUT HEX STEEL #10-32 | https://www.digikey.com/en/products/detail/keystone-electronics/4705/316276 | Professor to confirm | No | Unchecked | $0.48 | One individual item per each. |  | 4705 | 2026-09-29 | 2026-09-29
4 | each | 0.13 | 36-4703-ND | WASHER FLAT #10 STEEL | https://www.digikey.com/en/products/detail/keystone-electronics/4703/316274 | Professor to confirm | No | Unchecked | $0.52 | One individual item per each. |  | 4703 | 2026-09-29 | 2026-09-29
1 | each | 9.39 | F2213/4BK105-ND | HEATSHRINK 3/4" X 4' BLACK | https://www.digikey.com/en/products/detail/alpha-wire/F2213-4-BK105/3718418 | Professor to confirm | No | Unchecked | $9.39 | One 4 ft stick; each = one whole stick. |  | F2213/4 BK105 | 2026-09-29 | 2026-09-29
1 | each | 0.14 | 3720-3104-ND | BUSHING 0.690" PA66 BLACK | https://www.digikey.com/en/products/detail/heyco-products-corporation/3104/15907204 | Professor to confirm | No | Unchecked | $0.14 | One individual item per each. |  | 3104 | 2026-09-29 | 2026-09-29
1 | each | 4.79 | 277-1207639-ND | DIN RAIL 35MMX7MM SLOT 9.8" STL | https://www.digikey.com/en/products/detail/phoenix-contact/1207639/10645207 | Professor to confirm | No | Unchecked | $4.79 | One 250 mm rail; cut the required 60 mm during fabrication. |  | 1207639 | 2026-09-29 | 2026-09-29
2 | each | 0.62 | 1920-1246-ND | CONN TERM BLK END STOP | https://www.digikey.com/en/products/detail/altech-corporation/CA802/8547037 | Professor to confirm | No | Unchecked | $1.24 | One individual item per each. |  | CA802 | 2026-09-29 | 2026-09-29
2 | each | 0.32 | 3720-8463-ND | NLN 1/2 NPT BLACK | https://www.digikey.com/en/products/detail/heyco-products-corporation/8463/15906932 | Professor to confirm | No | Unchecked | $0.64 | One individual item per each. |  | 8463 | 2026-09-29 | 2026-09-29
2 | each | 1.39 | 732-10676-ND | HEX STANDOFF M5 STEEL 65MM | https://www.digikey.com/en/products/detail/w%C3%BCrth-elektronik/970650581/6174896 | Professor to confirm | No | Unchecked | $2.78 | One individual item per each. |  | 970650581 | 2026-09-29 | 2026-09-29

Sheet: Home Depot
Purchase request · Home Depot
Vendor materials subtotal (USD) |  |  |  | $97.63 | Shipping, tariffs, tax, fabrication and labor excluded.
One vendor per request. Quantity counts selling units; each can mean one complete pack or roll.
Professor to confirm consumable classification. Review collection notes before submitting.
Quantity | Units | Price (USD / unit) | Catalog/Part # | Description | Item URL | Is this item consumable or be in use for less than 1 year before disposal? | Is this a repair part or service? | No Delivery Expected | Line total (USD) | Selling unit / package contents | Collection / fulfillment | Manufacturer / Model # | Price checked | Description checked
2 | each | 6.99 | 301304939 | 15 Amp 125-Volt Grounding Connector, Yellow 515CV | https://www.homedepot.com/p/301304939 | Professor to confirm | No | Unchecked | $13.98 | One individual item per each. Two total: one internal XA connector and one printer output connector. |  | 515CV | 2026-09-29 | 2026-09-29
13 | feet | 1.46 | 204633006 | (By-the-Foot) 14/3 300-Volt CU Black Flexible Portable Power SJOOW Cord | https://www.homedepot.com/p/Southwire-By-the-Foot-14-3-300-Volt-CU-Black-Flexible-Portable-Power-SJOOW-Cord-55808699/204633006 | Professor to confirm | No | Unchecked | $18.98 | One continuous 13 ft length. Price is per foot. | Champaign store pickup required; delivery unavailable for ZIP 61820. Arrange collection before submitting. | 55808699 | 2026-09-29 | 2026-09-29
1 | each | 3.65 | 309610976 | 15 Amp 125-Volt 3-Wire Plug, Yellow 515PV-YL | https://www.homedepot.com/p/Leviton-15-Amp-125-Volt-3-Wire-Plug-Yellow-515PV-YL-R10-515PV-0YL/309610976 | Professor to confirm | No | Unchecked | $3.65 | One individual item per each. |  | R10-515PV-0YL | 2026-09-29 | 2026-09-29
6 | feet | 0.95 | 204632031 | (By-the-Foot) 14 Black Stranded CU THHN Wire | https://www.homedepot.com/p/204632031 | Professor to confirm | No | Unchecked | $5.70 | One continuous 6 ft length. Price is per foot. | Champaign store pickup required; delivery unavailable for ZIP 61820. Arrange collection before submitting. | 22955999 | 2026-09-29 | 2026-09-29
6 | feet | 0.91 | 204632154 | (By-the-Foot) 14 Green Stranded CU THHN Wire | https://www.homedepot.com/p/204632154 | Professor to confirm | No | Unchecked | $5.46 | One continuous 6 ft length. Price is per foot. | Champaign store pickup required; delivery unavailable for ZIP 61820. Arrange collection before submitting. | 22959199 | 2026-09-29 | 2026-09-29
1 | each | 3.63 | 202522492 | 16 - 14 AWG #8 - 10 Stud Size Ring Terminals in Blue (15-Pack) | https://www.homedepot.com/p/202522492 | Professor to confirm | No | Unchecked | $3.63 | 15 pieces per pack; each = one whole pack. |  | 15-104 | 2026-09-29 | 2026-09-29
1 | each | 10.27 | 202261925 | 12 ft. x 3/4 in. One-Wrap Strap | https://www.homedepot.com/p/202261925 | Professor to confirm | No | Unchecked | $10.27 | 12 ft × 3/4 in per roll; each = one whole roll. |  | 90340 | 2026-09-29 | 2026-09-29
2 | each | 1.95 | 321071719 | M3-0.5 x 12mm Zinc Pan Head Phillips Drive Machine Screw 4-Pieces | https://www.homedepot.com/p/321071719 | Professor to confirm | No | Unchecked | $3.90 | 4 pieces per pack; each = one whole pack. |  | 837761 | 2026-09-29 | 2026-09-29
2 | each | 1.95 | 321071866 | M3-0.5 Stainless Steel Lock Nut 4-Pieces | https://www.homedepot.com/p/321071866 | Professor to confirm | No | Unchecked | $3.90 | 4 pieces per pack; each = one whole pack. |  | 837221 | 2026-09-29 | 2026-09-29
2 | each | 1.95 | 321071623 | M4-0.7 x 10mm Zinc Pan Head Phillips Drive Machine Screw 4-Pieces | https://www.homedepot.com/p/321071623 | Professor to confirm | No | Unchecked | $3.90 | 4 pieces per pack; each = one whole pack. |  | 836351 | 2026-09-29 | 2026-09-29
1 | each | 4.96 | 204801237 | Stainless Steel Metric Flat Washer (M4 Screw Size) | https://www.homedepot.com/p/204801237 | Professor to confirm | No | Unchecked | $4.96 | 50 pieces per pack; each = one whole pack. |  | 4118 | 2026-09-29 | 2026-09-29
2 | each | 1.95 | 321071795 | M4-0.7 Stainless Steel Lock Nut 4-Pieces | https://www.homedepot.com/p/321071795 | Professor to confirm | No | Unchecked | $3.90 | 4 pieces per pack; each = one whole pack. |  | 837171 | 2026-09-29 | 2026-09-29
1 | each | 1.57 | 317479556 | #10 Zinc-Plated External Tooth Lock Washer (18-Piece) | https://www.homedepot.com/p/317479556 | Professor to confirm | No | Unchecked | $1.57 | 18 pieces per pack; each = one whole pack. |  | 827311 | 2026-09-29 | 2026-09-29
2 | each | 2.97 | 323370995 | M5-0.8x10mm Stainless Steel Pan Head Phillips Drive Machine Screw 2-Pieces | https://www.homedepot.com/p/323370995 | Professor to confirm | No | Unchecked | $5.94 | 2 pieces per pack; each = one whole pack. |  | 863468 | 2026-09-29 | 2026-09-29
1 | each | 1.95 | 321071519 | M5-0.8 x 12mm Zinc Pan Head Phillips Drive Machine Screw 4-Pieces | https://www.homedepot.com/p/321071519 | Professor to confirm | No | Unchecked | $1.95 | 4 pieces per pack; each = one whole pack. |  | 836521 | 2026-09-29 | 2026-09-29
2 | each | 2.97 | 323371831 | M5 Stainless Steel Flat Washer 4-Pieces | https://www.homedepot.com/p/323371831 | Professor to confirm | No | Unchecked | $5.94 | 4 pieces per pack; each = one whole pack. |  | 864408 | 2026-09-29 | 2026-09-29

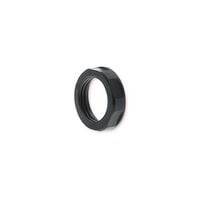
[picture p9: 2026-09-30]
assets/materials/gland-nut-8463.jpg

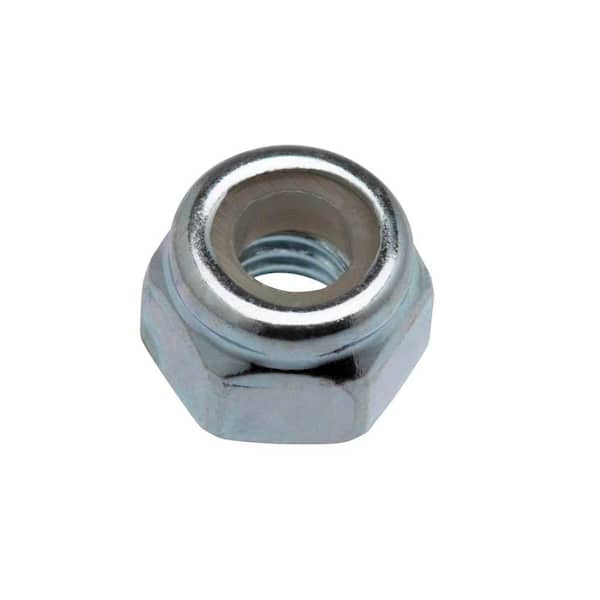
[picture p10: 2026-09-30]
assets/materials/request-321071795.jpg

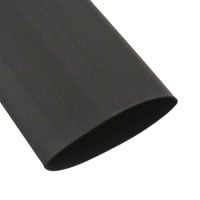
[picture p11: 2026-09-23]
assets/materials/usb-sleeve-fit221.jpg

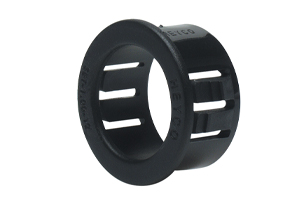
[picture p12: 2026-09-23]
assets/materials/usb-bushing-heyco.jpg

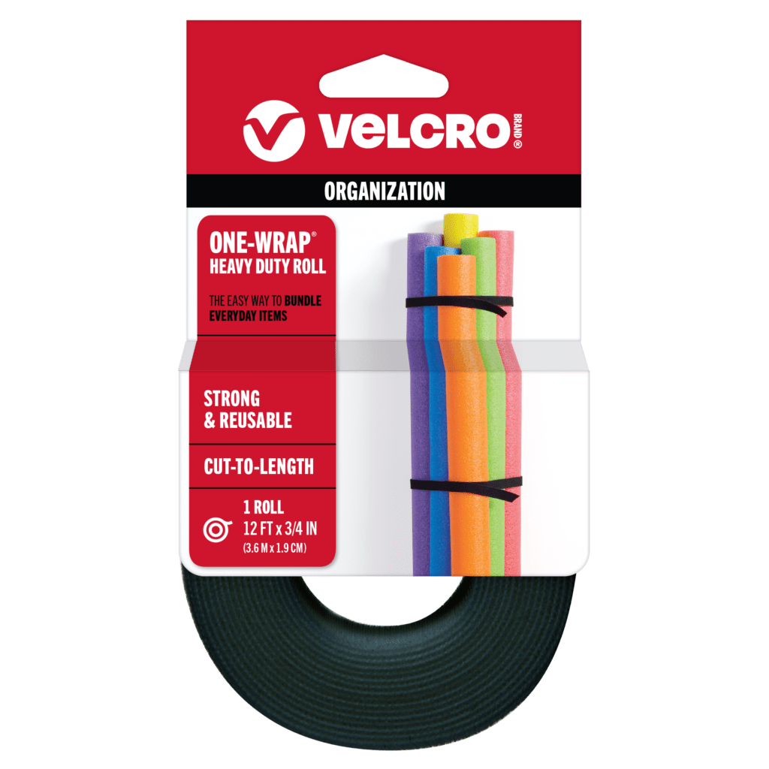
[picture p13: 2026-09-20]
assets/materials/logger-straps.png

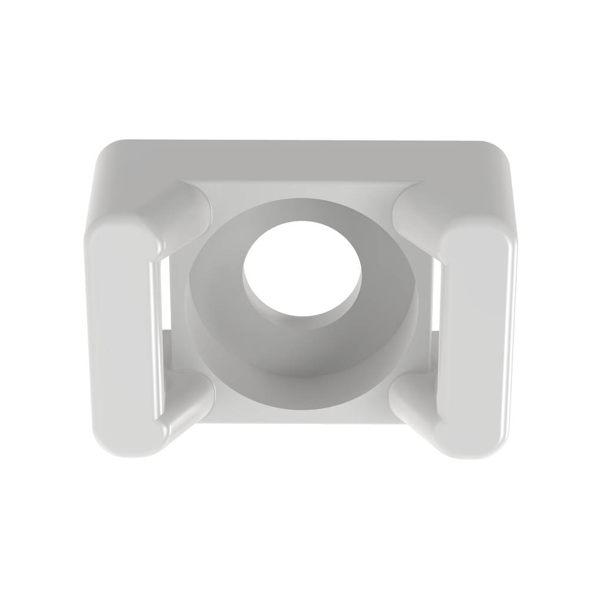
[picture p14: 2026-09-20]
assets/materials/tie-mounts.png

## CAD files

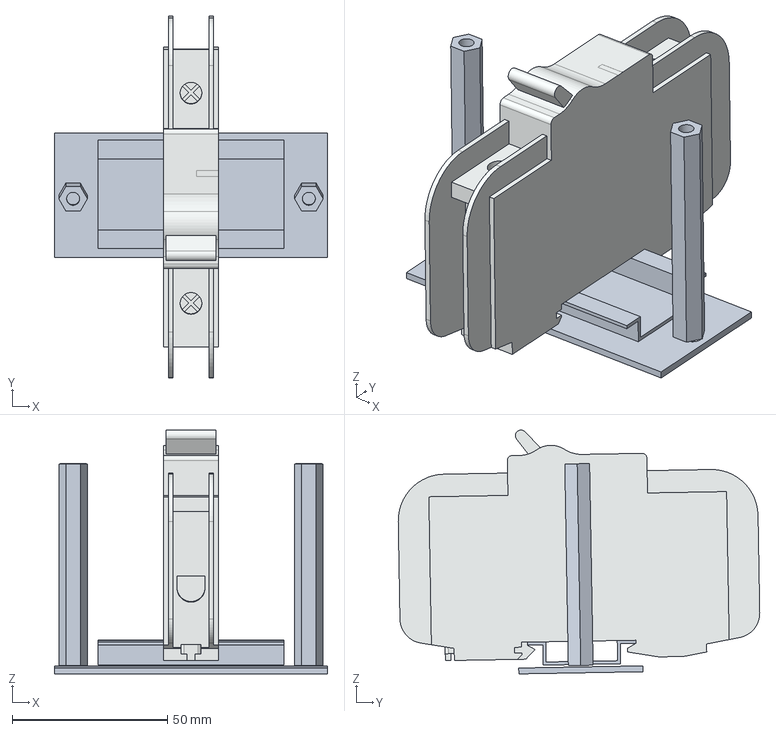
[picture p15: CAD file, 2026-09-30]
fabrication/q0-installed-assembly.step
88.0 x 116.5 x 78.6 mm
TMC_81___-SELECT

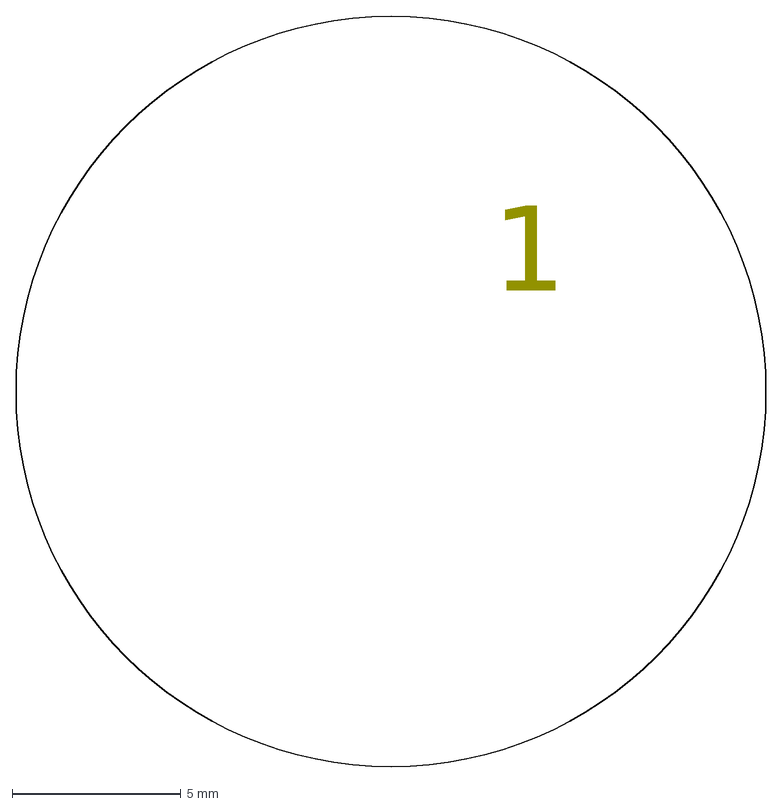
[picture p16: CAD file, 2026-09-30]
fabrication/left.dxf
1

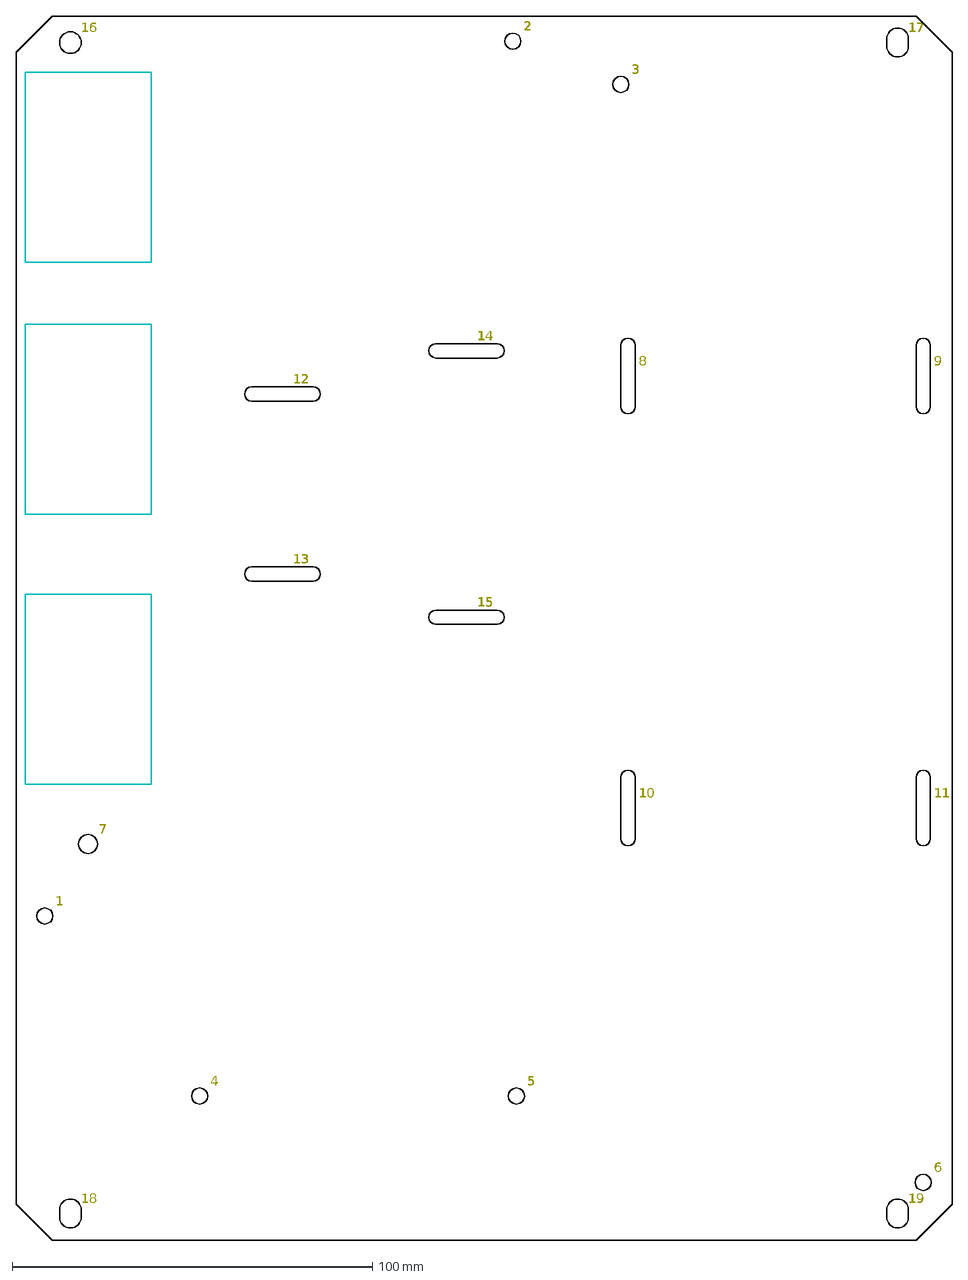
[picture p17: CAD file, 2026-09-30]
fabrication/panel.dxf
1
2
3
4
5
6
7
8
9
10
11
12
13
14
15
16
17
18
19

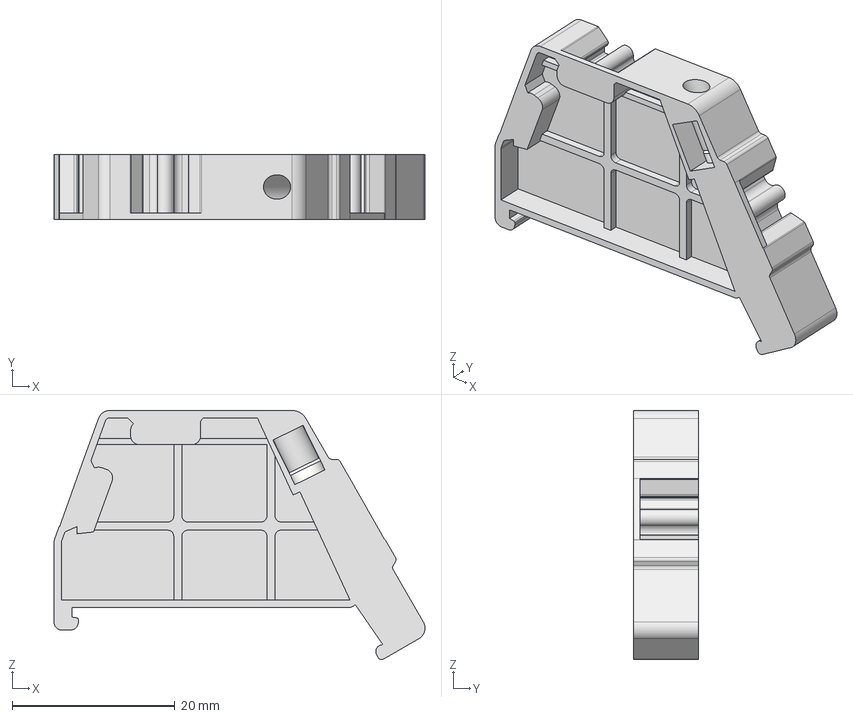
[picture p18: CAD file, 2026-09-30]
fabrication/altech-ca802-reference.step
45.6 x 8.00 x 30.6 mm

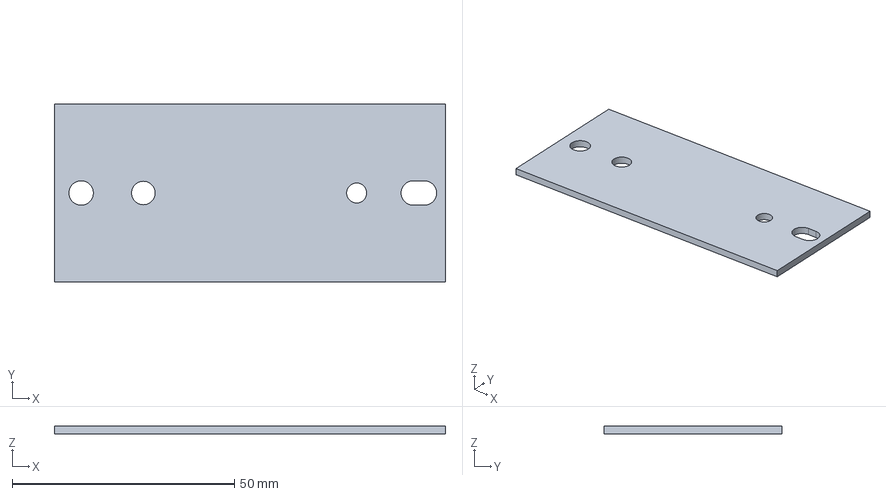
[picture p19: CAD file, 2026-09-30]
fabrication/q0_mount.step
88.0 x 40.0 x 1.90 mm

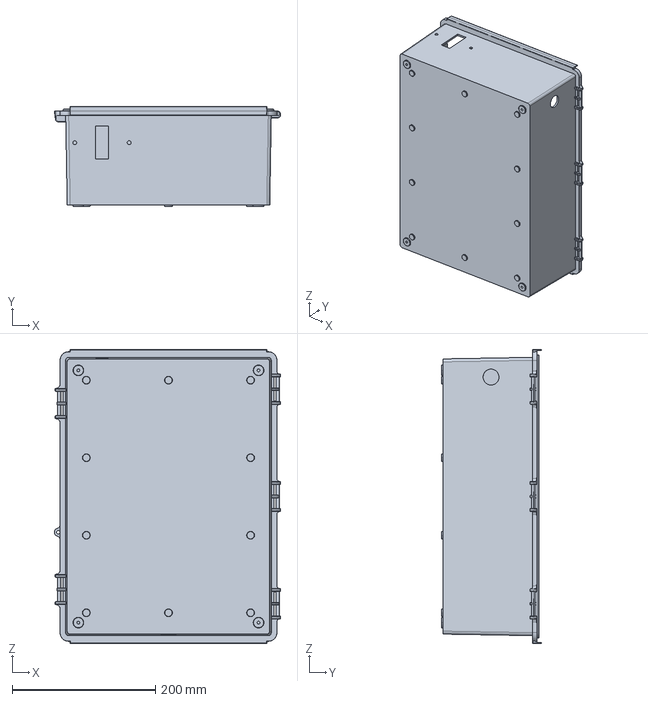
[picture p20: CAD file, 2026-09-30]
fabrication/case-machined.step
316.6 x 140.3 x 411.1 mm

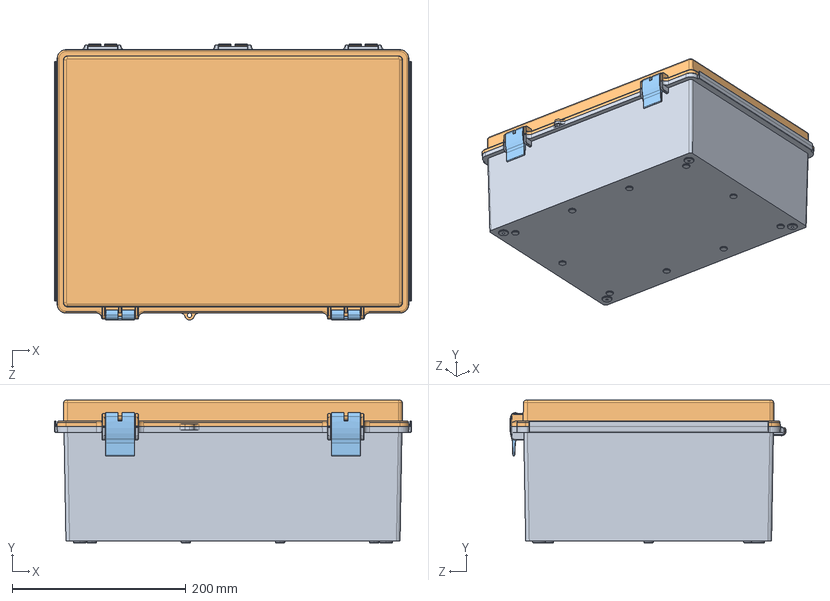
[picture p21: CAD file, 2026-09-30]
fabrication/bud-nbf32226-reference.step
411.1 x 164.3 x 318.4 mm
NBF-32026-B
NBF-32026-C
Latch-med-5mm x 2

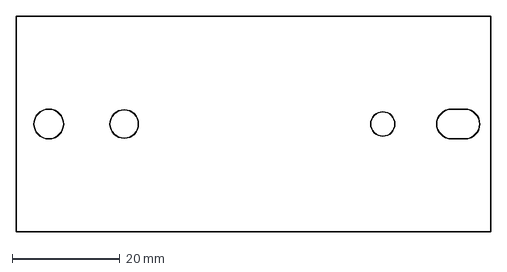
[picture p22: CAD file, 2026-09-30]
fabrication/q0-mount-flat.dxf
88.0 x 40.0 mm

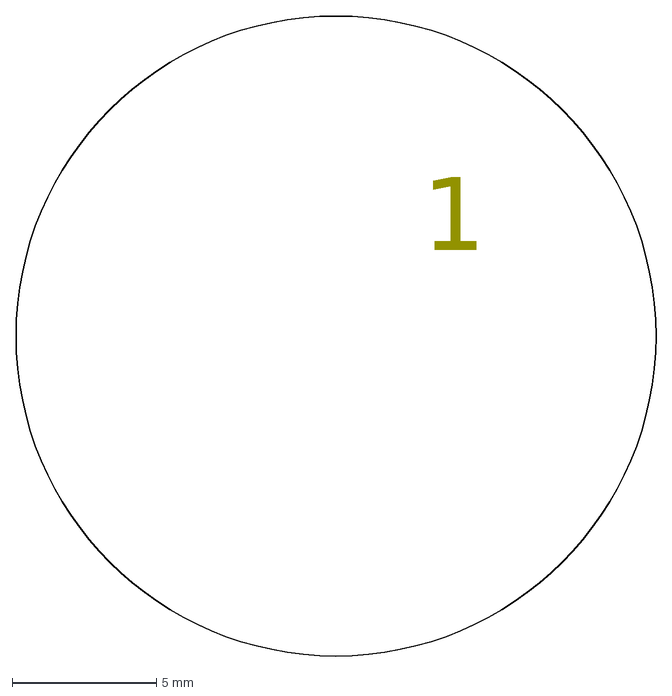
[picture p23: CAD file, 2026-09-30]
fabrication/rear.dxf
1

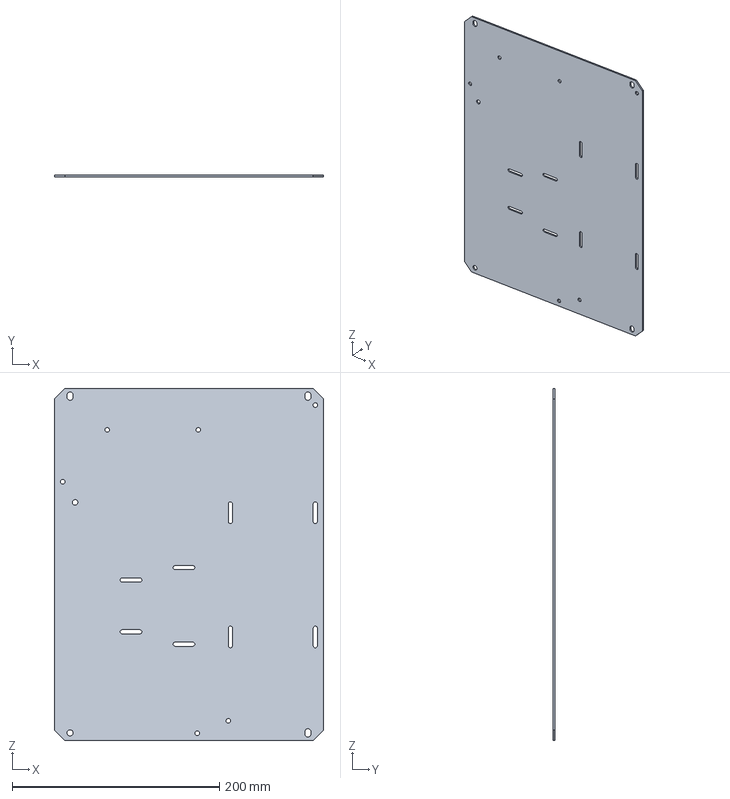
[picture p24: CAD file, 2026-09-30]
fabrication/panel-machined.step
260.0 x 1.90 x 340.0 mm

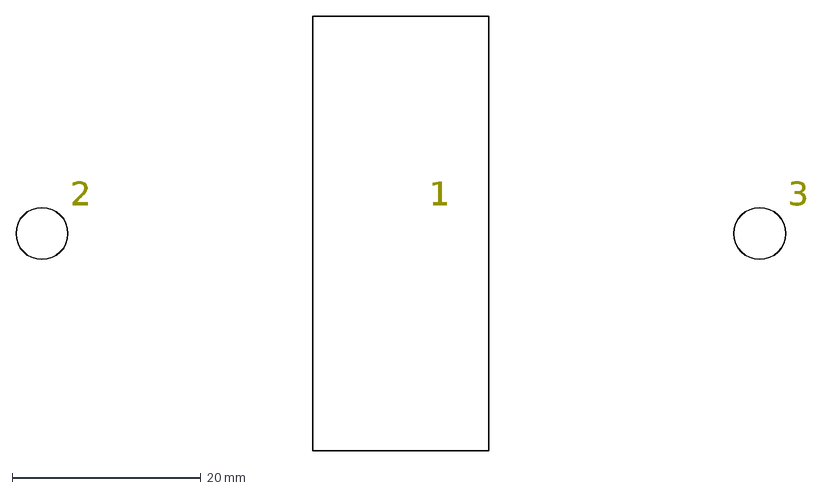
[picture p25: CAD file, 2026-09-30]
fabrication/front.dxf
1
2
3

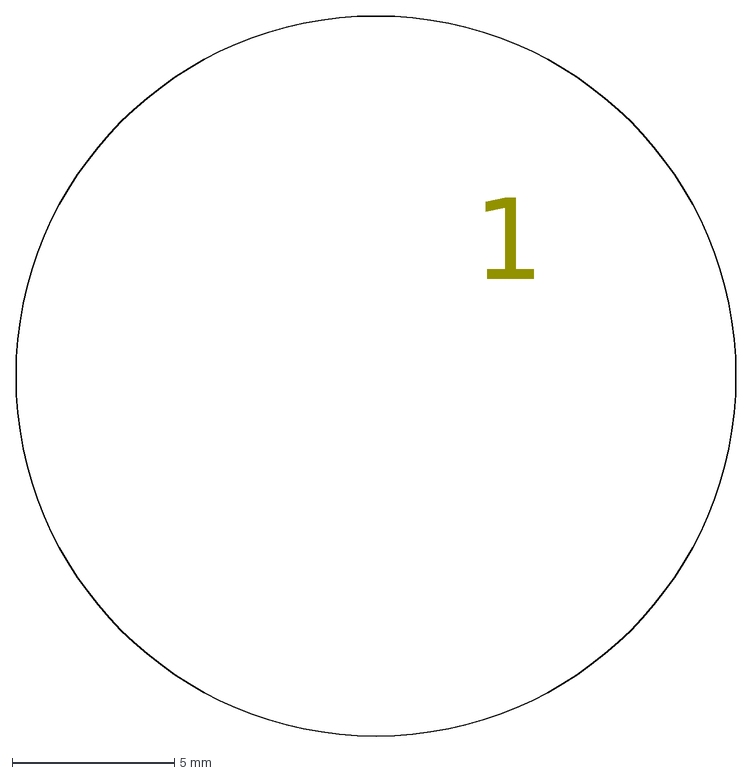
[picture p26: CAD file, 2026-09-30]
fabrication/right.dxf
1

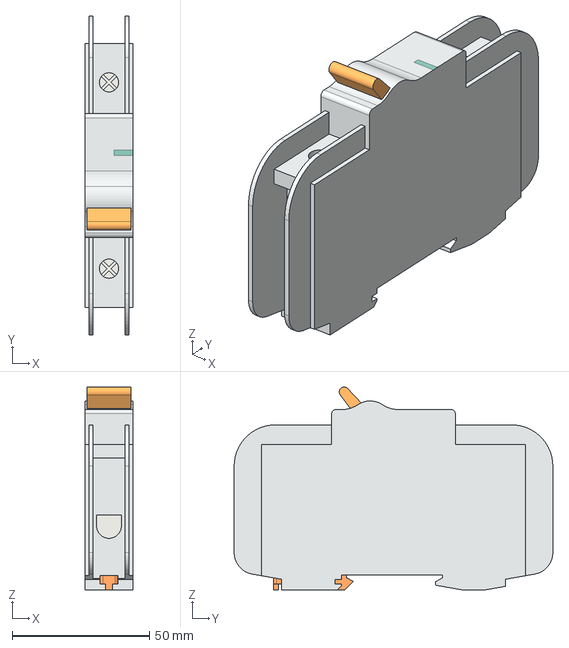
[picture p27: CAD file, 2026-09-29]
fabrication/phoenix-2907571-reference.step
17.6 x 116.0 x 73.9 mm

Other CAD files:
fabrication/case-machined.stl
fabrication/panel-machined.stl
fabrication/q0_mount.stl

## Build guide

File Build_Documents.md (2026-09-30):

# Build documents

- [Design, sourcing and component evidence](revision.html)
- [Machining files and assembly guide](build.html) — drawings, fasteners and assembly order.
- [Interactive installation sequence](index.html#assembly-preview) — inspect the six stages in 3D.
- [Protection review](protection.html) — Q0, upstream voltage-lead protection and the remaining evidence.
- [Installation audit](installation.html) — checks completed and remaining acceptance items.
- [Full materials list](materials.html) · [Download BOM](Procurement_BOM.md)
- [School purchase request](purchase-request.html) · [Download Excel](downloads/purchase-request.xlsx)
- [Manufacturer sources and design limits](references.html)

## Drawings

[Wiring SVG](wiring_routes.svg) · [Wiring PNG](wiring_routes.png) · [Connector SVG](connector_detail.svg) · [Connector PNG](connector_detail.png)

<h2 id="operation">Operation</h2>

Daily use begins only after qualified electrical inspection and setup.

1. **Configure offline.** With mains unplugged and the lid closed, connect the free exterior USB-A end of the existing cable to the ELOG computer; use ELOG to set the clock, actual CT range and interval. Confirm logging is enabled and sufficient memory remains. Disconnect from the PC before reconnecting mains; the whole cable stays attached to the box.
2. **Run independently.** XA and the adapter stay secured inside. With Q0 OFF and the lid closed, connect one printer and the supply. Switch Q0 ON. The clear polycarbonate lid permits visual inspection; verify recording by an offline export after the supervised pilot. Record each job's start, phase changes and finish times against the synchronized clock.
3. **Download in batches.** After the printer finishes its shutdown/cooldown, switch Q0 OFF, unplug mains and verify absence of mains voltage. Keep the lid closed, connect the same free USB-A end to the PC and export the records in ELOG. Preserve raw data before clearing memory. Disconnect from the PC and stow the free end before the next powered run.

**Q0 OFF is not isolation; its input remains live. Unplug SUPPLY IN from the wall before connecting a PC or opening the box. The complete USB cable stays attached to the box during printing; its exterior end is disconnected from the PC.**

The logger stores time-series data in non-volatile memory and can be powered by USB for readout ([DENT manual](https://www.dentinstruments.com/wp-content/uploads/EXC_ELOG19_11-15-24.pdf), printed pp. 7, 18, 119). The internal portion of the existing USB cable requires rated insulation even though the PC is connected only offline. The selected black FIT-221 sleeve has a manufacturer 600 V rating; its application, end coverage and restraint remain physical acceptance items. USB does not provide mains isolation. Validate one complete offline run and export before collecting the experiment series.

### Initial setup and electrical checks

Qualified electrical personnel verify terminations, polarity, PE continuity, insulation, protection and enclosure fit before releasing the assembly. Q0 opens hot only; PE stays continuous. Upstream Q0 protection for the original voltage leads and supply suitability must be accepted before energizing.

Configure ELOG for single phase / two wire, CH1 voltage high L1 and low N, the actual CT type/range and logging interval. Disable unused channels. Verify sensible readings and positive real power against an independent reference meter; prove recording and restart behavior with a supervised power cycle.

## Software and lab equipment

Arrange access separately; these resources are not marked as owned.

- **ELOG software — Download / install; no separate software purchase.** Use DENT ELOG for configuration, recording and data retrieval. Installation on the lab computer has not been verified. [DENT download](https://www.dentinstruments.com/software-downloads/elog-software-elitepro-xc-sp-power-meters/)
- **ELOG computer and printer under test — Arrange lab equipment.** Need a supported Windows computer with a matching USB port and the printer with its original grounded cord. These are setup resources, not checked as owned or counted as enclosure purchases; no replacement printer or computer has been selected.
- **Assembly and acceptance equipment — Arrange qualified assembly / lab tools.** Calipers, wire stripper, terminal-matched crimper, torque tools, machining/deburring tools, PE/polarity/insulation test equipment and an independent power reference. Arrange access before assembly; tool ratings and procedures belong to the approved build process.

## Purchasing notes

Quantities are for one enclosure; supplier pack sizes may be larger. Check stock and lead times. “Select / Configure” needs a size or rating choice; “Quote / Fabrication” needs supplier follow-up. Owned means on hand, not approved for use. Purchase holds remain marked beside the relevant materials.

Click photos to enlarge them. Reference images and design concepts are labeled; photos are not to scale. Image credits are in each material's Details and the full BOM.

<h2 id="dimensions">Dimensions and model notes</h2>

**Concept layout; use the build package for machining.** Manufacturer CAD, published sizes and estimates share one scale. Small hardware and cable dressing are simplified; spare stock is excluded. Received parts still need a physical fit check.

Amber marks the selected material; hidden housings become transparent. Top view matches the wiring plan. The selected NBF-32226 has gray walls and a clear polycarbonate lid. Closed mode keeps the walls opaque and the lid transparent; X-ray mode additionally reveals through the walls. BUD case/lid and Phoenix Q0 use manufacturer STEP geometry without scaling. The 65 mm posts use manufacturer dimensions; threads, flexible cables and some small parts remain simplified. Drag to rotate, scroll or pinch to zoom; keyboard controls are arrow keys, + / − and Home.

| Component | Model envelope (mm) | Evidence / limit |
|---|---|---|
| BUD NBF-32226 · clear hinged cover | 318.5 × 164.3 × 411.1 | Manufacturer STEP, unscaled; clear polycarbonate lid · [Source](https://www.budind.com/product/nema-ip-rated-boxes/nbf-series-fiberglass-enclosure/nbf-32226/) |
| Reused aluminum panel · provisional 1.90 mm | 260.0 × 1.9 × 340.0 | Proposed fabrication template; stock not measured · [Source](https://www.budind.com/wp-content/uploads/2019/01/hbnbf32226.pdf) |
| DENT ELITEpro XC | 63.0 × 47.0 × 216.0 | Catalog dimensions; verify actual unit · [Source](https://www.dentinstruments.com/wp-content/uploads/ELITEproXC_Datasheet_01272026.pdf) |
| CT1 · printer hot only | 29.4 × 41.7 × 26.4 | Mini HSC family matched; 50 A variant probable · [Source](https://www.dentinstruments.com/shop/current-sensors/hinged-current-transformers-sensors-for-energy-metering/) |
| Q0 · Phoenix TMC 81C 15A | 17.6 × 116.5 × 74.3 | Manufacturer STEP; operating position shown, travel unverified · [Source](https://www.phoenixcontact.com/en-us/products/thermomagnetic-device-circuit-breakers-tmc-81c-15a-2907571) |
| JL / JN / JPE distribution | 29.8 × 8.2 × 18.3 | Manufacturer connector and carrier dimensions · [Source](https://www.wago.com/us/wire-splicing-connectors/compact-splicing-connector/p/221-415) |
| XA · internal Leviton 515CV | 66.3 × 39.1 × 39.1 | Manufacturer dimensional envelope; strap installation proposed · [Source](https://leviton.com/content/dam/leviton/residential/product_documents/none/Document-31435-Dimensional%20Data.jpg) |
| CUI SMI6-9-V-P5 · existing adapter | 30.0 × 40.5 × 64.0 | Photo-identified; manufacturer body dimensions · [Source](https://www.belfuse.com/media/datasheets/products/power-supplies/SMI6.pdf) |
| Power glands and direct USB cable exit | 28.8 × 43.2 × 28.8 | Manufacturer-dimensioned Heyco cordgrips; small details simplified · [Source](https://www.heyco.com/products/liquid-tight-cordgrips/nylon-cordgrips/heyco-tite-liquid-tight-cordgrips-straight-thru-npt-hubs/) |
| DENT adapters & retained lead slack | Routing only | Illustrative routing; length not validated · [Source](https://www.dentinstruments.com/shop/elitepro-accessories-replacement-parts/replacement-unterminated-voltage-leads-10-for-elitepro-series/) |

[Dimensions JSON](layout_dimensions.json) · [Enclosure CAD provenance](assets/enclosure.json) · [Materials JSON](procurement.json) · [Cable-support checks](installation_supports.json)

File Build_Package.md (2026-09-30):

# Machining and assembly guide

September 28, 2026 · one grounded 120 V supply · one printer at a time.

**Engineering review package. Complete-order, machining and energizing release remain open.** The design uses internal adapter power and proposed aluminum reuse. [Cost, sourcing and certification review](revision.html). The drawings do not represent a physically assembled or certified product.

[Materials with pictures and purchase links](materials.html) · [3D installation sequence](index.html#assembly-preview) · [Installation audit](installation.html) · [Protection review](protection.html)

## Downloads

| File | Use |
|---|---|
| [Six-page machining drawing](fabrication/Machining_Drawings.pdf) | Hole coordinates, viewing directions, dimensions and tolerances. Print for reference, not as a scale template. |
| [Machined case STEP](fabrication/case-machined.step) · [Machined panel STEP](fabrication/panel-machined.step) | Exact solid geometry for shop review and fixturing. Use the BUD common-base template and proposed aluminum plate; actual stock and received clear lid remain to be checked. Do not print a substitute mains enclosure. |
| [Front DXF](fabrication/front.dxf) · [Right DXF](fabrication/right.dxf) · [Left DXF](fabrication/left.dxf) · [Rear DXF](fabrication/rear.dxf) · [Panel DXF](fabrication/panel.dxf) | Millimetres, 1:1. The chamfered outline and internal features are on `CUT`; verify stock and the support pattern before using them. `REFERENCE` and `TEXT` are non-cutting. The right-wall file contains one Ø22.2 mm USB cable-exit bore; no USB fixing holes. |
| [Q0 bracket STEP](fabrication/q0_mount.step) · [Provisional flat DXF](fabrication/q0-mount-flat.dxf) | Flat cut-and-drill aluminum bridge; two purchased 65 mm M5 posts. No bending. Measure stock and dry-fit before machining. |
| [Cut and clearance results](fabrication/cad-checks.json) · [Wall opening coordinates](fabrication/wall-openings.json) | Reproducible digital checks and shared datums. |
| [Wiring drawing](wiring_routes.svg) · [Connector detail](connector_detail.svg) · [Connection schedule](routes.json) | Electrical topology. These drawings are not machining templates. |

## Photo identification and remaining checks

The existing photos were compared with manufacturer product pictures, original datasheets and a legacy CT product photo. No concealed label characters were reconstructed.

| Item | Identification and design decision | Evidence / remaining check |
|---|---|---|
| Black adapter | **CUI SMI6-9-V-P5**, 9 V DC, 0.667 A, center positive. Retain it. Body 64 × 40.5 × 30 mm ±1 mm; 5.5/2.1 mm P5 plug. | Label readable in the original photo; [official CUI SMI6 datasheet](https://www.belfuse.com/media/datasheets/products/power-supplies/SMI6.pdf). Check condition, output and seating at assembly. |
| White CT | **DENT Mini HSC** family; **CTHSC-050-U/B, 50 A / 333.3 mV is probable** from the partial “DENT 50…” label and legacy appearance. | [DENT family specifications](https://www.dentinstruments.com/shop/current-sensors/hinged-current-transformers-sensors-for-energy-metering/), [legacy label comparison](http://siscoinc.net/cthsc-050-ubdentcurrenttransformer.aspx). 20 A and 50 A versions share the body. Wires conceal the full variant: read the label during assembly before setting ELOG. No duplicate CT is in the purchase list. |
| Three OEM voltage pigtails | User confirms three original DENT kit pigtails in different colors. Matched family: **DENT LD-SKTSP**, **10 in / 254 mm nominal**, female safety connector to factory-tinned end. A1 = hot/L1; A2 = neutral/L2; A3 = neutral/N. | [DENT original accessory](https://www.dentinstruments.com/shop/elitepro-accessories-replacement-parts/replacement-unterminated-voltage-leads-10-for-elitepro-series/). Photo connector, tinned end and ESIS card agree. Online data does not publish AWG/ampacity. Qualified acceptance of termination and upstream Q0 protection remains necessary. |
| Internal DC | Original CUI adapter and intact flat cord connect directly to the logger inside. | No extension, external coupling, KVT frame or insert. Check original plug seating, restraint, slack and closed-enclosure temperature. |
| Existing USB cable | One intact owned A-to-B cable: B stays in DENT, cable passes through Heyco 3104, free A end connects to the PC. Sleeve the internal portion. | [DENT manual](https://www.dentinstruments.com/wp-content/uploads/EXC_ELOG19_11-15-24.pdf), printed pp. 16, 18, 29: USB power and insulation requirements. Export with mains unplugged and the lid closed. |
| Q0 / supply | Phoenix TMC 81C 15A / 2907571, 15 A, single pole, C curve; UL489 / cUL Listed E320373, 277 V AC, 10 kA. | Actual JIS receptacle fault current and combined startup waveform remain unknown. [Detailed protection review](protection.html). |

**Voltage-lead protection:** A1 now connects directly to JL after Q0; no dedicated voltage-tap fuse is installed. Suitability of the upstream 15 A Q0 for the original DENT lead set remains unverified. Accept that protection scheme before energizing. The meter's internal fuse cannot clear an external lead short that bypasses the meter. See the [protection review](protection.html).

These checks use the photos already supplied. The hidden CT characters and unpublished conductor ratings remain explicit limits, rather than requests for more images.

## Internal power and offline USB

XA is now **Leviton 515CV**, the same SKU as the printer output. Buy **two total**. Its complete molded body encloses its terminals; its integral cord clamp retains a continuous **14/3 SJOOW** branch from JL/JN/PE, upstream of CT. One adjustable strap supports XA, another independently retains the original adapter. Fully seat the adapter and verify the restraints prevent loosening without loading the blades. Do not modify either factory DC connector.

The original adapter cable stays entirely inside and plugs directly into the logger. Dress its slack using the reserved DC tie location; do not crush the flat jacket. Cable curves are illustrative: actual length, bend allowance, mains separation and lid clearance need dry fitting. No XA or DC wall opening remains. One protected USB cable exit remains on the right wall.

USB configuration/download uses the free USB-A end with mains unplugged and verified absent. The lid stays closed. Disconnect from the PC before reconnecting mains; the complete cable stays attached to the box, with its internal portion sleeved. Validate saved records with an offline download after a supervised pilot; the clear cover allows visual inspection; exported data still verifies recording. Check adapter/enclosure temperature in that pilot.

### Closed-lid USB construction

Reuse the **one existing USB-A to USB-B cable intact**. USB-B stays in DENT; the same cable exits through a **Heyco 3104 (SBT 875-11)** snap bushing and ends in USB-A for the PC. No coupler, short internal data cable or USB mounting screws are required. The existing front/right cable support restrains the sleeved cable beside the DC lead. The bushing only protects the edge: accept the restraint only if external pull cannot move the sleeve or load the DENT socket. The 3D exterior length is abbreviated; retain the full cable and check usable reach.

**Published sizing:** [USB 2.0](https://www.usb.org/document-library/usb-20-specification), Figure 6-10, limits a standard-B overmold to **11.5 × 10.5 mm** (diagonal **15.57 mm**); Table 6-5 gives nominal cable ODs **4.06–5.21 mm**. The [Heyco drawing](https://www.heyco.com/products/bushings-grommets-heycaps-plugs/tubing-caps-and-plugs/heyco-thick-panel-snap-bushings/) gives a **17.5 mm passage**, leaving **1.93 mm nominal diametral margin** for the unsleeved standard plug. The mounting hole is **22.2 mm**, and the 6.4 mm maximum wall thickness covers the modeled 3 mm wall. These are published design dimensions, not measurements of the owned cable. DENT's kit datasheet lists 1.8 m; its [current replacement](https://www.dentinstruments.com/shop/powerscout-accessories/replacement-usb-a-to-b-communications-cable/) lists 2 m, so retain the actual cable rather than cutting to either nominal length.

Dry-fit the intact USB-B end through the **loose bushing before adding the sleeve**. Apply accepted insulation while the cable is disconnected from the logger and PC. Pass the protected end through the empty wall hole, then snap the bushing into the wall; confirm full seating and pull restraint. Do not force a plug or cut/splice the USB cable to make it fit.

Retain **black Alpha Wire F2213/4 BK105**, specified to **UL224 / CSA198, 600 V** ([manufacturer](https://www.alphawire.com/products/accessories/fit-heat-shrink-tubing/shrink-tubing/fit2213_4)). One 4 ft stick covers the internal run, the DENT termination and the wall crossing. Supplied minimum ID is 19.05 mm; recovered maximum ID is 9.53 mm. Accept complete coverage and retention against sliding. Alpha lists 90°C minimum shrink and 121°C full recovery; the original cable's permitted application process is unpublished. Have the assembler approve that process for the actual cable and protect the connectors. The illustrated end coverage is not a separately qualified boot.

The bushing and sleeve provide no USB galvanic isolation or claimed IP/NEMA seal. Review shell/shield treatment with the electrical assembler; do not add an undocumented PE-to-USB connection. Use the accepted assembly indoors in its dry environment. Connect to the PC only after unplugging mains.

<h2 id="panel-stock">Selected construction and aluminum stock</h2>

Select **BUD NBF-32226**, 400 × 300 × 160 mm, with a **clear polycarbonate hinged cover** and two latches. The [manufacturer page](https://www.budind.com/product/nema-ip-rated-boxes/nbf-series-fiberglass-enclosure/nbf-32226/) links the [series STEP](fabrication/bud-nbf32226-reference.step), used without scaling for shell, lid and latches. Its internal filename is hbnbf32026.step; this is the file supplied by BUD for the selected NBF-32226. Verify the received cover, gasket and access protection; the latch cover is not tool-fastened or locked. Machined openings do not retain the original enclosure ingress rating.

Fabricate the professor's offered aluminum as a **260 × 340 mm panel with four 10 mm corner chamfers**. The provisional **1.89738 mm (approximately 1.90 mm) thickness** is not a stock measurement. Record alloy, thickness, flatness and stiffness; update the CAD and every screw stack before fabrication. The [BUD drawing](https://www.budind.com/wp-content/uploads/2019/01/hbnbf32226.pdf) gives four M5 inserts at **229.8 × 325.3 mm**; the linked STEP centers span 229.75 × 325.25 mm, within its ±1 mm tolerance. One Ø6 mm locating hole and three 8 × 6 mm slots are in the template. Verify/transfer the actual pattern before cutting. **Four M5 × 10 mm machine screws are not included with the box and are budgeted separately.** Do not substitute its supplied wall-bracket self-tapping screws.

Provide a dedicated PE bond with a reviewed method and hardware suitable for the actual aluminum. Do not assume the former steel-panel bonding stack is qualified for aluminum, or rely on ordinary mounting screws for electrical continuity. The existing #10 hardware is a dimensional proposal pending that review.

Q0 uses the new metal DIN support behind the front wall, with its operator accessible outside. Three WAGO **221-415 / 221-505** connector/carrier pairs provide JL, JN and PE. A1 feeds from JL; A2/A3 from JN. PE joins supply earth, printer earth, internal XA earth, panel bond and Q0 rail/bracket bond. One accepted conductor per port.

The logger retains two **19.05 mm ONE-WRAP** straps, with a **216 × 69 × 58 mm** receiving envelope. Add two straps for XA and adapter. Eight **21 × 4 mm** smooth panel slots support all four straps. Fit and trim the flexible straps; do not drill equipment housings or cover required adapter markings/heat-dissipation surfaces.

<h2 id="q0-mount">Q0 flat bridge, posts and protective bond</h2>

**No bending is required.** Cut and drill an **88 × 40 mm flat aluminum bridge**, then attach it to two **Würth 970650581 steel posts: 65 mm long, M5 female/female, 8 mm across flats, 11 mm internal thread per end**. Nominal plate thickness is 1.89738 mm; measure the professor's stock before cutting. The four bridge features are at X = −38, −24, +24, +38 mm from center: Ø5.5 post datum, Ø5.3 dedicated PE stud, Ø4.5 M4 rail fixing, and an 8 × 5.5 mm post-adjustment slot. Drill the slot's two end bores 2.5 mm apart and join them. [Flat bridge STEP](fabrication/q0_mount.step) · [1:1 cut DXF](fabrication/q0-mount-flat.dxf) · [Installed assembly STEP](fabrication/q0-installed-assembly.step).

The **Phoenix 2907571** [manufacturer STEP](fabrication/phoenix-2907571-reference.step) is used without scaling. Body/handle depth is 73.8788 mm; catalog 17.6 × 116 × 75.9 mm includes a 7.5 mm rail. The front wall has an **18.6 × 46 mm window** and two **Ø5.5 mm holes at 76 mm pitch**. The nominal handle projects **7.38 mm** beyond the outer wall; its stationary nose face is approximately **0.8 mm recessed**. Terminal guards remain 3.4 mm behind the inner wall. The supplied STEP depicts one operating position: confirm full ON/OFF/TRIP movement, finger access and access protection in an offcut before machining the case.

Cut **60 mm** from the purchased **Phoenix 1207639 250 mm rail**; deburr and transfer-drill its ±24 mm fixing positions. The rail center is 0.4 mm above the window center in the local 1° wall frame. Fit two CA802 stops beside Q0; keep the release latch accessible. At the provisional washer stack, bridge front depth is **66.3 mm** from the inner wall and rail rear depth is **65.5 mm**. Nominal 0.8 mm rail spacing must match the accepted bond-contact stack on the opposite side.

The two stops use the [original CA802 STEP](fabrication/altech-ca802-reference.step) at 1:1 scale in the website. Its vendor topology does not pass solid validity checks, so it is a visual reference at a nominal rail seat, excluded from exact-solid clearance claims. Confirm the received clips engage the rail. The installed assembly STEP above contains the bridge, posts, rail and breaker; the stops remain separate references.

Each post takes an **M5 × 12 mm screw at each end**. Outside: screw head → tooth washer → M5 flat washer → 3 mm case wall → M5 flat washer → post. Inside: screw head → tooth washer → M5 flat washer → aluminum bridge → contact tooth washer → post. The six tooth washers share the purchased 18-piece pack with the five existing PE-stud washers; verify actual M5 clearance and contact suitability. Use six M5 flat washers from two four-piece packs. Tightening must retain the assembly without cracking or creeping the plastic wall; support torque is not inferred from Q0's terminal torque.

Nominal screw engagement is **6.9 mm at the wall** and **8.3 mm at the bridge**, within the manufacturer's 11 mm thread depth, using 0.8 mm flat and 0.5 mm compressed tooth washers. These washer values are assumptions, not received-part measurements. Confirm actual engagement, no bottoming, loosening resistance and deflection while operating Q0.

One spare **M4 × 10** screw/nut and three washers retain the other rail fixing. The dedicated **#10-32 × 3/4 in** bond stud uses two nuts, two flat washers and three tooth washers; the panel has its own separate bond stud. **Connection 24, PE.5 → rail/bridge**, starts from a 350 mm green 14 AWG blank. Have the electrical reviewer accept aluminum-compatible contact preparation and PE continuity to **rail, bridge and both steel posts**. Ordinary unqualified mounting contact is not evidence of a protective bond.

Q0 receives one **14 AWG copper conductor per clamp, 11–12 mm strip length, 2 N·m terminal torque**. No power ring terminals are fitted to Q0. Factory entry geometry and straight 24 mm wire approaches are retained; validate tool access and bends with the actual part. [Phoenix terminal and rating data](https://www.phoenixcontact.com/en-us/products/thermomagnetic-device-circuit-breakers-tmc-81c-15a-2907571).

The nominal CAD checks find no solid overlap between Q0, shell, closed manufacturer lid, panel, bridge or rail. Q0-to-lid minimum distance is **4.19 mm**, window-side gap **0.50 mm** and bridge-to-shell gap **2.80 mm**. These are nominal geometric results; full handle travel, manufacturing tolerances, post retention and PE continuity remain physical acceptance items.

**Power cordgrips:** fit two [Heyco M3231](https://www.heyco.com/products/liquid-tight-cordgrips/nylon-cordgrips/heyco-tite-liquid-tight-cordgrips-straight-thru-npt-hubs/) long-thread 1/2 NPT glands and two separately purchased 8463 nylon locknuts. Use Ø22.2 mm clearance holes, not the old PG13.5 Ø21 mm holes. Thread length 15.5 mm minus 3 mm wall and 6.7 mm nut leaves nominally 5.8 mm; confirm the received stack and integral seal. The published 4.32–11.43 mm seal range includes the nominal 9.2 mm cord, but its UL-approved cable range and strain-relief performance still need acceptance.

## Machining datums

The 3D and wiring plan share X/Z locations. X is across the panel; Y is upward from the **panel underside**; Z is forward toward Q0. Negative Z is the printer exit. The real case walls have approximately **1° draft**. The wall DXFs are local flat-face setups, not projections to a vertical plane.

For outside views: front U = X; rear U = −X; right U = −Z; left U = Z. V runs up along the wall. Its origin is the intersection of that face with Y = 0 and the case centerline. Use the STEP model and the physical panel support datum to fixture the case; the bottom outside edge is **not** Y = 0. Panel drawing: view from the lid, U = X, V = −Z, origin at the blank center.

| Feature | Cut geometry | Datum in assembly coordinates |
|---|---|---|
| Q0 operator / bracket | 18.60 × 46.00 mm rectangle; two Ø5.50 mm holes at 76 mm horizontal pitch | Front wall; X = −93, Y = 75 mm; local drafted-wall frame |
| Supply gland | Ø22.20 mm | Left wall; Y = 43, Z = 128 mm |
| Printer gland | Ø22.20 mm | Rear wall; X = 0, Y = 36 mm |
| USB cable exit | One Ø22.20 mm mounting hole; no fixing holes | Right wall; Y/Z = 55/167 mm. [Heyco 3104 dimensions](https://www.heyco.com/products/bushings-grommets-heycaps-plugs/tubing-caps-and-plugs/heyco-thick-panel-snap-bushings/): 17.5 mm passage, 24.2 mm head, 14.3 mm overall height; wall up to 6.4 mm. Dry-fit before machining. |
| Panel bond | Ø5.30 mm, dedicated to PE | X/Z = −110/60 mm |
| Meter straps | Four 21 × 4 mm slots, long axis Z | X = 40 and 122; Z = −70 and 50 mm |
| Internal-power straps | Four 21 × 4 mm slots, long axis X | X/Z = −56/−65, −56/−15, −4.85/−77, −4.85/−3 mm |
| Cable mounts | Six Ø4.50 mm holes | Individual coordinates in the panel drawing |
| Three WAGO carriers | Two Ø3.30 mm fixing holes per carrier | Place within the dashed locator envelope, orient the carrier as shown, then transfer-drill from the actual part. The unlocated longitudinal fixing datum is not invented. |

The six anchor positions support the mains bundle, outlet supply, CT pair, two sides of the voltage-lead coils and the original internal DC cable together with the sleeved USB lead. Each tie passes through its mounting-base slot and encloses that bundle. The same coordinates drive the panel CAD and 3D view.

Retain the verified enclosure support pattern and original lid features. The panel template has 19 internal cut features: six cable-anchor holes, one panel PE hole, eight strap slots and four panel mounting features. Transfer-drill six additional holes for the three carriers. Deburr every cut, remove chips and protect the gasket. Smooth strap slots on both faces without enlarging their functional opening. Machining does not confer an IP/NEMA certification on the completed assembly.

<h2 id="fasteners">Fasteners and purchase quantities</h2>

Buy all required hardware from **DigiKey and Home Depot**. Counts below distinguish **installed pieces** from the actual **purchase packs**, including unused pieces. No lab fastener stock is assumed. The complete hardware purchase is **$26.63**, before freight and tax. Metric and US threads are deliberately distinguished.

| Assembly | Installed hardware | Exact purchase links |
|---|---|---|
| Q0 flat bridge on posts | 2 × 970650581 posts; 4 × M5 × 12 screws; 6 × M5 flat washers; 6 tooth washers | DigiKey: [two 65 mm M5 posts](https://www.digikey.com/en/products/detail/w%C3%BCrth-elektronik/970650581/6174896). Home Depot: one 4-pack [836521 screws](https://www.homedepot.com/p/321071519), two 4-packs [864408 flat washers](https://www.homedepot.com/p/323371831). Tooth washers share the 18-pack below. |
| Three WAGO carriers | 6 × M3-0.5 × 12 mm pan screws; 6 × M3 washers; 6 × M3-0.5 locknuts | Home Depot: 2 four-piece packs of [837761 zinc pan screws](https://www.homedepot.com/p/321071719), 2 four-piece packs of [837221 stainless locknuts](https://www.homedepot.com/p/321071866). DigiKey: 10 total (6 installed + 4 spare) [Keystone 4692 M3 / #4 zinc-plated steel washers](https://www.digikey.com/en/products/detail/keystone-electronics/4692/316261). |
| Six tie anchors | 6 × M4-0.7 × 10 mm pan screws; 6 × M4 washers; 6 × M4-0.7 locknuts | Home Depot: 2 four-piece packs of [836351 zinc pan screws](https://www.homedepot.com/p/321071623), 2 four-piece packs of [837171 stainless locknuts](https://www.homedepot.com/p/321071795), 1 fifty-piece pack of [Hillman 4118 M4 stainless flat washers](https://www.homedepot.com/p/204801237). Six screws/nuts here; one spare screw/nut plus three spare washers serve the rail fixing. Eight screw/nut pieces and fifty washers cover the total. |
| Panel to case | 4 × M5-0.8 × 10 mm pan screws | Home Depot: 2 two-piece packs of [863468 stainless pan screws](https://www.homedepot.com/p/323370995). Fit directly through the panel into the factory M5 inserts; check head coverage and engagement. |
| Two PE studs: panel and rail/bracket | 2 × #10-32 × 3/4 in screws; 4 plain nuts; 5 external-tooth washers; 4 flat washers; 2 ring lugs total | DigiKey: 2 [Keystone 9911 stainless pan screws](https://www.digikey.com/en/products/detail/keystone-electronics/9911/317331), 4 [4705 zinc-plated steel nuts](https://www.digikey.com/en/products/detail/keystone-electronics/4705/316276), 4 [4703 zinc-plated steel flat washers](https://www.digikey.com/en/products/detail/keystone-electronics/4703/316274). Home Depot: 1 eighteen-piece pack of [827311 zinc-plated external-tooth washers](https://www.homedepot.com/p/317479556). Rings come from the 15-104 pack in the main BOM. |

Check separately purchased panel screws against actual stock. Keep both latches and gasket intact. Q0 has box lugs: use bare prepared copper, one wire per selected terminal; rings are used only at the two dedicated #10 bond studs.

Each anchor uses an M4 × 10 mm pan screw with its head directly on the base, then an underside washer and locknut. The illustrated stack leaves about 3.4 mm to the case floor. Confirm actual base thickness, nut engagement and floor clearance on receipt; small molded details are illustrative.

**Stack checks:** the M5 post screw stacks and nominal engagement are listed above. The 10 mm rail screw crosses 1 mm rail + 0.8 mm spacer + 1.897 mm bridge + 0.8 mm washer + approximately 4 mm locknut, leaving about 1.50 mm. Measure actual washers and nuts and verify full locking engagement without deforming the wall. These calculations do not establish support strength. XA has no wall screws; the USB bushing snaps in.

Fit carrier/anchor fasteners while the panel is out. There is about **9.50 mm** between the panel underside and the inner case floor in the source CAD. Check actual screw projections and washers against this space and the molded supports. For the six revised M4 × 10 mm anchor screws, verify full locking-nut engagement and at least 3 mm clearance to the actual case floor before installing the panel.

For the proposed panel PE stud, first approve the hardware/contact method for the actual aluminum. The geometric arrangement puts the screw head and flat washer underneath. On the conductive side, use an external-tooth washer and first nut to secure the dedicated stud, then the ring lug, flat washer, external-tooth washer and second nut. Establish a clean metal contact under the bonding hardware; do not rely on paint, straps or ordinary mounting screws for bonding. Final bonding method, tightening and continuity acceptance belong to the qualified assembler. The website does not assign an unsupported universal bonding torque.

## Wire and length schedule

Buy **13 ft of 14/3 SJOOW** and start with 2.0 m supply, 1.0 m printer-output and 0.8 m internal-XA blanks. Their internal conductors extend directly to the specified terminals. Keep sufficient PE slack so that jacket displacement does not pull PE free first. Measure the desired exterior reach before cutting.

Use the selected 14 AWG black and green internal wire for Q0 output and both metal bonds. XA uses conductors from its continuous 14/3 cord. The following are conservative **cutting blanks**, not proved finished lengths; final routing, bends and stripping are done with the assembly de-energized. Allow 1 m black and 1 m green including spare wire. Buy 6 ft (1.8288 m) of each color to meet Home Depot's current online minimum; both lengths are budgeted. All three by-the-foot wire lines require Champaign store pickup. No separate white-wire roll is required.

| Connection | Starting blank | Termination |
|---|---|---|
| 02 Q0 OUT → JL | Black, 500 mm | Bare prepared copper in Q0 box lug and WAGO port |
| 17/18/19 distribution → XA | One 800 mm 14/3 cord blank | JL hot, JN neutral, PE earth → corresponding 515CV terminals; jacket in clamp |
| 12 PE → panel bond | Green, 200 mm | WAGO to #10 ring |
| 24 PE.5 → rail/bracket bond | Green, 350 mm | WAGO to dedicated #10 ring; accepted conductive contact to both metals |

Connections 01/03/06/07/10/11 use the supply/output cord conductors. Connections 05/08/09 use the three existing pigtail + full-lead chains; retain their full factory length. Connections 14/15 use the CT pair; 16 is one existing USB cable, sleeved inside and passed directly through the wall, used with mains unplugged and the lid closed. Connections 20–23 illustrate factory adapter contacts and DC wiring, **not** instructions to open or modify the adapter. The site provides the full 22-path schedule; retained connection IDs stay unchanged.

Label both ends of every conductor. A1 is hot; A2 and A3 are neutral. The three original pigtails have different colors; drawing colors are schematic, so follow connection IDs. Grounding uses the separate green conductors. The full voltage-lead storage model assumes 2 m of flexible cable per lead and 3 mm OD; real cable lengths, connector bodies and minimum bends must fit without loading meter sockets.

## Assembly and acceptance sequence

1. Close the identification/entry/protection items above, obtain the exact parts and compare them with the machining setups. Keep the case and all cords disconnected while machining or wiring.
2. Machine the **empty** case and removable panel. Transfer-drill carrier fixings, deburr, clean, and inspect for cracks. Complete underside nuts, PE studs, carrier/anchor fixings and thread the straps before lowering the panel.
3. Install and secure the panel, then fit the three carriers, logger, CT and internal XA/adapter assembly. Leave access to the CT latch and WAGO levers; verify the four adjustable straps.
4. Fit Q0 to the supported DIN rail, install both end stops, verify full latch engagement and free operator travel through the new opening. Install two power glands. Route intact supply/output jackets through the glands. Clamp the internal XA cord jacket in the 515CV body, fully seat and independently restrain the original adapter, and route its original DC cable inside. Fit the direct USB cable exit as described above, with accepted 600 V sleeve/end protection and restraint at the existing front/right support. Disconnect only the PC end before mains operation; leave the intact cable attached to the box. XA/DC stay inside.
5. Bond panel, Q0 rail/bracket, output and XA; then complete neutral, protected hot, voltage sensing, CT and low-voltage wiring. Only the printer hot conductor goes through CT once, arrow toward the printer. Keep voltage taps and adapter consumption upstream of CT.
6. Check every termination, strain relief, bend, clearance and fastener. Verify CT latch travel and plug removal access. Confirm that both latches close the lid without pressing on cables or components; accept the access protection for this enclosure. This dry fit is still outstanding.
7. Qualified personnel document PE continuity, polarity, insulation/isolation, protection and supply suitability using the applicable test procedure. Disconnect sensitive electronics where the manufacturer requires it for insulation testing. Q0 OFF leaves incoming terminals live while the supply is plugged in.
8. Check closed-enclosure adapter temperature and restrained plug seating in a supervised pilot. The clear lid permits visual inspection; confirm logging by an offline export after unplugging mains. Configure ELOG for single-phase/two-wire measurement and the **identified** CT. Verify positive real power and reasonable readings with an independent reference. Test start/stop and power-return recording behavior, then check each printer's cold start and sustained load. Do not release daily use from a browser simulation alone.

| Manufacturer termination | Published preparation / torque |
|---|---|
| WAGO 221-415 | Strip 11 mm; one accepted conductor per port, lever fully closed. Identify the factory-tinned pigtail ends before selecting preparation; do not add solder. |
| Phoenix 2907571 Q0 | One 14 AWG Cu conductor per screw clamp, within the published 18–2 AWG range; strip 11–12 mm, tighten to 2 N·m. Follow received instructions. Custom bracket and aluminum-bond torques require their own acceptance. |
| 515PV / 515CV, glands and enclosure | Follow the exact supplied instructions. The Q0 or outlet torque must not be reused for unrelated parts. |

Manufacturer sources and per-material limits are linked in the [installation audit](installation.html) and [reference schedule](references.html). The public project records digital geometry and circuit checks; it does not yet record a built, tested or approved assembly.

<h2 id="receiving-record">Receiving and release record</h2>

No measurements, acceptance signatures or live tests are recorded yet. Use this record to close the physical items; document actual values rather than changing a status to “pass” without evidence.

| Stage / owner | Record | Acceptance or next action |
|---|---|---|
| Aluminum / fabricator | Usable length ___ mm × width ___ mm; thickness ___ mm; alloy/finish ___; flatness/support assessment ___ | Finished outline is 260 × 340 mm with 10 mm corner chamfers. Stock must cover it plus the shop's trimming allowance. The current 1.89738 mm thickness is a template only. Measure and update the solid, support heights and every screw stack for the actual thickness; do not approve strength from thickness alone. |
| Stock unavailable / designer | Reuse result ___; fallback decision ___ | Source a suitable blank for the verified BUD mounting pattern and revise the budget if the offered stock fails. No purchased replacement panel is included in the material subtotal. |
| Purchased case / fabricator | NBF-32226 label ___; four M5 inserts ___; actual clear-lid clearance ___ | Match the support pattern and lid before machining. Verify both latches, gasket, screw engagement and accepted access protection. |
| Aluminum PE bond / electrical reviewer | Accepted lug/contact stack ___; aluminum surface treatment ___; anti-rotation method ___; torque basis ___; measured bond result ___ | The generic #10 stud/ring arrangement is a proposal, not a listed aluminum-bond system. Accept an aluminum-compatible contact method and any required replacement hardware before fabrication or energizing. No unsupported bonding torque is assigned. |
| Terminations / assembler | Received 15-104 markings ___; tool/die and manufacturer instruction ___; sample crimp/pull result ___; all terminal torques ___ | #8–10 is compatible with #10 studs; #8-only is not. Validate the actual 14 AWG insulation fit. Preserve the 75°C terminal rating and the lower applicable temperature limit of every component. |
| Closed-box fit / assembler | Four restraints ___; full AC/DC plug seating ___; gland grip ___; wire/lid clearance ___; measured screw-floor clearance ___ | No connector blade load, pinched insulation or restrained heat-dissipation surface. Anchor screws need full locknut engagement and at least 3 mm actual floor clearance. |
| Supply and protection / responsible electrical staff | Outlet/circuit ___; supply/fault-current assessment ___; combined startup assessment ___; original DENT lead protection decision ___ | Accept the complete assembly for the intended 120 V supply and 15 A design. Q0's 10 kA rating is not an assembly SCCR. Upstream-only voltage-lead protection requires acceptance; see [protection review](protection.html) and its prepared information requests. |
| USB assembly / assembler | Intact USB-B passage ___; bushing fit ___; approved sleeve process ___; internal/end coverage ___; external-pull restraint ___; separation/shield treatment ___ | DENT requires rated insulation for cable inside the electrical panel. Black FIT-221 is specified to UL224/CSA198, 600 V; the assembled cable has not been qualified. No PC connection during mains operation. |
| Offline configuration / operator | Actual CT model/range/output ___; ELOG configuration file ___; existing USB export verified ___ | Read the uncovered CT label. Do not assume 50 A from the photograph. Configure and download only with mains disconnected. |
| Release / responsible reviewer | PE/polarity/insulation results ___; closed-box pilot temperature ___; sample log/export ___; reference-meter comparison ___; reviewer/date ___ | Apply the accepted test procedure and actual manufacturer limits. Close and inspect the assembly before any supervised pilot. Routine use begins only after release; software/CAD tests do not substitute for these measurements. |

The current [priced order plan](materials.html#order-plan) includes every selected material order increment and spare quantity. Verify delivered price and lead time at checkout; no order or message has been sent.

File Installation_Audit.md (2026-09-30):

# Installation audit

**STOCK, USB ASSEMBLY AND ELECTRICAL ACCEPTANCE OPEN.**

All **27 material groups** were reviewed: 1 catalog match · 22 conditional · 4 measure · 0 hold. A catalog match confirms the stated interface only; it is not approval of the complete item or assembly.

One grounded 120 V supply, one printer at a time. The design uses a clear-cover BUD NBF-32226 enclosure, proposed reuse of the professor’s aluminum sheet and an internal adapter connection. Six owned equipment groups, including the existing USB cable, are retained. The selected 15 A Q0 and upstream-only voltage-lead protection still require application acceptance. No purchase, physical fit, thermal test or electrical release is claimed. Closed-lid USB export is used only after unplugging mains; the internal portion of the existing USB cable requires rated insulation and accepted assembly.

The box and major panel parts have nominal space, but the current design cannot be called a perfect or fully installable assembly. Machining geometry is supplied; Exact CT scaling, voltage-lead protection and physical/electrical acceptance remain open. XA and DC remain inside. One existing USB cable runs directly from DENT through a protected right-wall hole to the PC; its internal portion is sleeved. Export with mains unplugged and lid closed. Do not treat a purchase link or an inventory tick as a release.

[Inspect the 3D installation stages](index.html#assembly-preview) · [Materials and buying links](materials.html) · [Machine-readable checks](installation_checks.json)

## Corrections from the audit

- Selected direct-stock BUD NBF-32226 with a clear polycarbonate lid. Factory shell, lid and latches are modeled at 1:1 scale.
- Proposed reuse of the professor’s aluminum sheet, with stock measurement and aluminum bonding held open.
- Moved XA and the original adapter inside. XA uses the same 515CV SKU as the printer output, with a continuous 14/3 cord branch.
- Removed the round DC extension, KVT frame and insert from the active BOM and model. Restored XA and DC wall stock; one protected direct-cable opening supports closed-lid export.
- Retained six cable anchor points and added separate straps for XA and adapter.
- Consolidated purchase sources and added exact-part approval evidence and a conditional DIN-breaker comparison.
- Simplified to one confirmed-owned USB cable through a snap bushing. Deleted the panel coupler, short cable and two M3 flange sets. Existing six supports and required internal insulation remain; direct-cable pull retention and plug passage need physical acceptance.
- Phoenix 2907571 remains selected. Replaced the folded bracket with a flat bridge and two 65 mm M5 posts; added all purchased post hardware. Updated cordgrips to self-stock Heyco M3231 / 8463, with Ø22.2 mm wall bores. The refreshed purchase request totals $273.00 from DigiKey and Home Depot; current prices and minimum order lengths are included.
- Re-routed the printer PE curve around the left/rear corner; regression screening of the displayed 1.7 mm-radius wire against the machined shell rejects the former spline overshoot. Physical routing remains an assembly check.

## Printer compatibility

| Printer | Manufacturer information | Design assessment |
|---|---|---|
| UltiMaker S5 | 100–240 VAC, 50/60 Hz, maximum 500 W (S5 user manual, PDF p.10). [s5](https://um-support-files.ultimaker.com/manuals/user-manual/S3-%26-S5/Ultimaker%20S3-S5%20-%20User%20manual%20ENv2.4.pdf) | 500 W / 120 V = 4.17 A only at unity power factor. This is a power-based screen, not nameplate current or inrush. Check installed peripherals and actual US plug. |
| Bambu Lab P2S | Official regional quick-start guide, printed pp.36 and 38: low-voltage version 100–120 VAC, 50/60 Hz, 1000 W at 110 V. Initial bed heating can sustain maximum power for about 3–5 minutes. [p2s](https://csm.bblcdn.com/hub/0a3c3e8ab9554a5c9c91815e41540f42.pdf) | 1000 W / 110 V = 9.09 A only at unity power factor. Verify the actual label next to the inlet, inrush and any AMS/dryer power paths. This design does not support a 200–240 V regional unit. |
| Prusa CORE One+ | Published CORE One+ specifications report a 240 W PSU and typical PLA/ABS printing consumption of 90/110 W. The current product page has moved to Gen 2; confirm the actual unit. [prusa](https://www.prusa3d.com/product/prusa-core-one/), [prusa-psu](https://help.prusa3d.com/wp-content/uploads/generated/prusa-core-one-kit-assembly_2321_en_2026-05-18.pdf) | A PSU rating and typical print consumption do not establish maximum AC input current. Confirm the user’s generation, AC nameplate, US cord and accessories; no exact maximum-current claim is made. |

These watts-to-amps values assume unity power factor and are not current ratings. Q0 supplies the selected printer plus the logger adapter and voltage tap. A 15 A breaker / connector proposal is not approval for a 15 A continuous load. No simultaneous three-printer load or separately powered accessory is included.

<h2 id="simulation">Installation simulation</h2>

Axis-aligned equipment envelopes, exact chamfered-panel clearance and continuous vertical swept volumes against the machined BUD common-base shell, nine lid rays per body and sourced interface arithmetic. Shell triangulation deflection is 0.3 mm; numerical seating-contact exclusion is 0.0001 mm. Neither is a manufacturing tolerance.

The analysis uses the checked-in component coordinates and actual shell triangles. It is not an FEA, tolerance study, collision-free cable-routing proof, thermal test, electrical clearance assessment or physical dry fit. The closed-lid check samples nine rays against the lid skin; it does not establish the smallest clearance to every lid fastener or operating part.

### 1. Verify stock and machine empty parts

Measure the offered aluminum and received enclosure. Close thickness, mounting and bonding decisions; use the linked machining files. The right wall has one Ø22.2 mm USB cable exit; no USB flange fixing, XA or DC openings. Dry-fit the bushing and cable, deburr all holes and eight strap slots, and clear chips.

**Result:** Digital cut and restored-wall checks only; no material has been received or machined.

### 2. Fit underside hardware and panel

Fit the six cable mounts and carrier fasteners, thread four equipment straps and check underside projections. Seat the panel on its factory supports. Install four separately purchased M5 × 10 mm panel screws after checking engagement.

**Result:** Nominal vertical insertion screen; actual stock thickness and fastener stacks need measurement.

### 3. Restrain logger, CT and terminals

Fit the logger with two adjustable straps; retain three WAGO groups, one CT and a dedicated aluminum-panel PE connection. Confirm CT label and cable slack.

**Result:** Catalog envelopes and routed cable geometry only; no physical retention test.

### 4. Install Q0, glands and internal power

Fit two 65 mm M5 posts, the flat aluminum bridge, 60 mm DIN rail, two stops and Phoenix Q0. No bending is required. Check the external handle, full travel and accepted bonding of rail, bridge and posts. Fit two Heyco M3231 glands with separate 8463 nuts, then the restrained internal XA/adapter and USB bushing.

**Result:** Internal layout proposal; actual plug engagement, anti-unplug retention and thermal suitability remain open.

### 5. Connect and dress the cables

Connect the XA 14/3 branch before CT. Route the intact original DC cable to the logger. Use the existing USB cable directly through the protected wall opening, with accepted 600 V insulation on its entire internal portion and protected termination. Use the existing front/right support to prevent external pull reaching DENT. Keep mains and low-voltage routes separated and perform offline ELOG setup.

**Result:** Electrical topology and digital routing checks; not a qualified electrical acceptance.

### 6. Close and verify the pilot

Disconnect the exterior USB-A end from the PC, stow it and close the clear lid before mains operation. The complete cable remains attached to the box. Qualified personnel complete electrical and closed-enclosure thermal checks. After the pilot, unplug mains and connect that same USB-A end to export with the lid closed.

**Result:** No energized test, temperature test or finished-assembly certification recorded.

## Numerical checks

| Check | Result | Evidence and limit |
|---|---|---|
| Q0 catalog body | **PASS** | Mounted box 17.600 × 116.534 × 74.315 mm; Phoenix manufacturer STEP: 17.6 × 116 × 73.8788 mm before wall-frame rotation. Catalog depth 75.9 mm includes 7.5 mm DIN rail; STEP depth includes the depicted handle. Receiving and full operator travel remain unverified. |
| Q0 terminal and mounting interfaces | **PASS** | Phoenix 2907571 screw clamps: 14 AWG Cu accepted; strip 11–12 mm, 2 N·m. Short 35 × 7.5 mm DIN rail; no ring tongues on Q0. Confirm supplied instructions, strip length, snap fit and 76 mm M5 post pattern. |
| Q0 no-bend post and screw stacks | **PASS** | 65 mm M5 posts; nominal engagement 6.90 mm at wall / 8.30 mm at bridge, in 11 mm threads. Flat bridge and rail depths agree with the washer stack. Design screen uses at least 5 mm engagement and 1 mm bottoming reserve. Actual washers, thread depth, tightening, wall strength and retention require physical checks. |
| Q0 bonded mounting provision | **PASS** | Flat aluminum bridge, steel rail, two steel posts and dedicated PE.5 branch are specified. Two #10 bond stacks are included in procurement. Accept contact preparation, torque and continuity to rail, bridge and both steel posts. |
| Bond ring size | **PASS** | Selected 15-104 rings accept #8–10 studs for the panel and rail/bracket bonds. Crimp and aluminum contact qualification remain physical checks.  |
| Internal original DC connection | **PASS** | Original adapter cable stays inside; extension, external coupling and feedthrough purchasing are removed.  |
| Internal XA and adapter | **PASS** | Both complete component envelopes remain inside the case plan with a 10 mm screening margin. Not a creepage/clearance standard or a restraint/thermal check. |
| Proposed aluminum reuse | **PASS** | Offered aluminum is a fabrication proposal, not confirmed owned stock or a bought steel panel. Actual thickness, stiffness and aluminum bonding remain to be accepted. |
| Panel component body separation | **PASS** | 7 nominal body envelopes do not overlap. CT uses the matched Mini HSC family envelope; exact scale remains unconfirmed. No connectors, open levers, flexible wires, mounting tolerances or screw-tool envelopes are certified by this check. |
| Vertical insertion through open case | **PASS** | 8/8 insertion sweeps clear the manufacturer shell; exact chamfered panel solid and seven equipment envelopes. 300 mm vertical translation, fixed orientation, wall fittings absent. Panel/support contact at Y=0 is excluded with a 0.0001 mm numerical offset. This tests shell access, not brackets, wires or tool motions. |
| Internal power retention | **HOLD** | Separate XA and adapter straps replace the wall mount; physical plug retention and closed-enclosure temperature are untested.  |
| Machined wall geometry | **PASS** | BUD NBF-32226 shell and custom aluminum panel machined; lid and latches retained from factory STEP. Flat cut-and-drill Q0 bridge; no bends. Carrier holes transfer-drilled. Exact cut-through gauges are in fabrication/cad-checks.json. Phoenix STEP and bracket are transformed to the 1 degree wall frame; the summary AABB contacts here are not mounting proofs. Received-part fit and fastening remain physical checks. |
| Closed lid screen | **SCREEN ONLY** | meter: 93.9 mm (9/9 rays); ct: 103.203 mm (9/9 rays); outlet: 105 mm (9/9 rays); q0: 12.886 mm (6/9 rays) Nine upward rays per body against the factory lid mesh. Not a minimum-distance proof; excludes lid hardware, guards, wire bundles and tolerances. |
| No XA wall opening | **PASS** | XA remains inside; the machining schedule contains Q0, SUPPLY, OUTPUT and one USB bore only. Cut-through gauges in fabrication/cad-checks.json check the new shell. |
| No DC wall opening | **PASS** | DC remains inside; the machining schedule contains Q0, SUPPLY, OUTPUT and one USB bore only. Cut-through gauges in fabrication/cad-checks.json check the new shell. |
| Closed-lid USB cable exit | **PASS** | USB center Y/Z = 55/167 mm has 0 obstructing wall intersections. USB-B overmold diagonal 15.57 mm fits the 17.5 mm passage. Published envelope and mesh centerline only; accept actual snap fit, cable passage and pull restraint. No ingress or isolation rating claimed. |
| One existing USB cable | **PASS** | The owned cable connects DENT USB-B directly to the exterior USB-A end; no coupler or additional USB cable is purchased. Full cable remains attached to the box; the model abbreviates the exterior length. Check available reach and prove export on the hardware. |
| Offline USB insulation provision | **PASS** | The existing cable has a 600 V sleeve provision on its entire internal portion, retained at the existing support. Unplug mains before connecting the PC. Provision only; sleeve fit, recovery process, end protection, restraint and shield treatment still need physical acceptance. A sleeve is not USB galvanic isolation. |
| Cord diameter interfaces | **REVIEW** | Southwire nominal OD 9.17–9.27 mm lies within Heyco M3231 published 4.32–11.43 mm seal range and Leviton 0.245–0.655 in range. Ø22.2 mm bores; separate 8463 locknuts. Seal range does not establish UL-approved cord range. Verify exact cable application, wall/nut stack, grip and pull resistance. |
| Ring barrel and internal wire | **REVIEW** | The selected 15-104 accepts 14–16 AWG. Its manufacturer does not publish an insulation-barrel limit on the cited page; do not reuse the former 3M value. Fit the actual 2.87 mm nominal-OD wire, use the specified crimp tooling and inspect/pull-test before accepting the termination. |
| Physical and electrical release | **HOLD** | No built assembly, nameplate verification, qualified acceptance or energized test has been recorded.  |

The former XA/DC wall positions remain solid. Exact CAD booleans provide Q0, two power-gland bores and one Ø22.2 mm USB cable-exit bore. Axis-aligned wall-device illustrations still do not model wall draft and cannot prove the mounted interface.

## Voltage-lead storage scenario

The old illustration had 4.5 turns rising only 6 mm, giving 1.33 mm pitch against its assumed 3 mm cable diameter. The new illustration separates turns and lead layers and adjusts turns for 2 m of flexible cable per lead. Connector body lengths are outside that flexible-length target. Actual leads have not been measured.

| Lead | Modeled flexible length | Turns | Pitch / assumed OD |
|---|---|---|
| A1 | 2000.0 mm | 5.88 | 4 / 3 mm |
| A2 | 2000.0 mm | 5.13 | 4 / 3 mm |
| A3 | 2000.0 mm | 4.96 | 4 / 3 mm |

Cable-to-meter screen: 301 points per curve; 0 sampled intrusions against the logger body expanded by wire radius. This does not check all other objects or wire-to-wire clearances.

The elliptical coil centerline uses 44 and 37 mm radii (minimum planar radius of curvature about 31.1 mm). No manufacturer bend limit is available for the actual leads. Transitions between coils, plugs, supports and other wires still need routing and physical inspection. [Rendered cable measurements](installation_cables.json).

## All materials and interfaces

**Hold** means essential identification, source resolution or custom engineering is missing. **Measure** needs the actual part. **Conditional** has a plausible catalog interface with unresolved installation conditions. **Catalog match** covers only the interface described. Ownership remains unchanged.

| Material | Result | Checked | Remaining work |
|---|---|---|---|
| [Power logger](index.html#material-meter)<br>DENT ELITEpro XC<br>✓ Owned | **Measure** | Current published case is 216 × 63 × 47 mm; older guide gives 203 × 69 × 58 mm. Existing unit has the right voltage / CT / USB connector families. [dent-size](https://www.dentinstruments.com/wp-content/uploads/ELITEproXC_Datasheet_01272026.pdf), [dent](https://www.dentinstruments.com/wp-content/uploads/EXC_ELOG19_11-15-24.pdf) | Measure this unit including plugs and magnetic feet. Verify the restraint, clearances, firmware and ELOG configuration. |
| [Current sensor](index.html#material-ct)<br>DENT Mini HSC · probable CTHSC-050-U/B<br>✓ Owned | **Conditional** | The white hinged case, label layout and partially visible “DENT 50…” match the legacy Mini HSC 50 A / 333.3 mV product. This is a probable variant identification: wires obscure the complete model. DENT 20 A and 50 A Mini HSC versions share the body and 10 mm aperture; both accommodate one printer-hot conductor. Set ELOG from the uncovered label at commissioning, not from appearance. [ct](https://www.dentinstruments.com/wp-content/uploads/2022/08/20A_Mini_Hinged_CT_Specs.pdf), [ct-family](https://www.dentinstruments.com/shop/current-sensors/hinged-current-transformers-sensors-for-energy-metering/), [ct-current](https://www.dentinstruments.com/wp-content/uploads/CT-HSC-XXX-U_Datasheet_06132024.pdf), [dent](https://www.dentinstruments.com/wp-content/uploads/EXC_ELOG19_11-15-24.pdf) | Uncover the existing label during assembly and enter its actual current/output in ELOG; validate positive watts against a reference load/meter. |
| [DENT voltage pigtails](index.html#material-blue-leads)<br>DENT LD-SKTSP series · 10 in / 254 mm nominal<br>✓ Owned | **Conditional** | User confirms three original DENT kit pigtails in different colors, all with the same voltage-sensing function. The connector, tinned end and ESIS card match the LD-SKTSP family. A1 feeds L1 hot; A2/A3 feed L2/N neutral. Colors identify connections; these leads do not carry printer load current or serve as PE. [blue](https://www.dentinstruments.com/shop/elitepro-accessories-replacement-parts/replacement-unterminated-voltage-leads-10-for-elitepro-series/) | OEM kit identity is confirmed. Accept original pigtail termination and protection by the upstream 15 A Q0 before use; original-kit status alone does not establish suitability. |
| [Full voltage leads](index.html#material-voltage-leads)<br>Existing matching voltage lead set<br>✓ Owned | **Measure** | Three leads connect A1/L1, A2/L2 and A3/N. Plug family looks consistent with the photos. [dent](https://www.dentinstruments.com/wp-content/uploads/EXC_ELOG19_11-15-24.pdf) | Measure actual complete and flexible lengths, mating engagement, cable OD and minimum bend radius. The revised 2 m / 3 mm coil scenario is an assumption, not evidence that the supplied leads fit. |
| [AC/DC adapter](index.html#material-adapter)<br>CUI SMI6-9-V-P5 · existing original adapter<br>✓ Owned | **Conditional** | Reuse the original CUI 9 V / 0.667 A center-positive adapter, with its P5 plug and flat cord intact. It plugs into the internal XA cord connector; its original cable runs directly to the logger. No DC extension, coupling or wall feedthrough. [dent](https://www.dentinstruments.com/wp-content/uploads/EXC_ELOG19_11-15-24.pdf), [cui](https://www.belfuse.com/media/datasheets/products/power-supplies/SMI6.pdf) | Owned. Verify full plug seating, restraint, cable slack and temperature during the closed-enclosure pilot. |
| [Enclosure](index.html#material-enclosure)<br>BUD NBF-32226 · clear hinged cover<br>□ To buy | **Conditional** | 400 × 300 × 160 mm ABS/PC box with a clear polycarbonate cover. Same manufacturer base and panel pattern; the exact factory STEP is displayed without scaling. [case](https://www.budind.com/wp-content/uploads/2019/01/hbnbf32226.pdf), [case-product](https://www.budind.com/product/nema-ip-rated-boxes/nbf-series-fiberglass-enclosure/nbf-32226/) | 103 in DigiKey direct stock at $111.88, checked September 29, 2026. Reconfirm at checkout. Received-part fit, latches, access protection and machining acceptance remain required. |
| [Mounting panel](index.html#material-panel)<br>Professor-supplied aluminum · fabricate after measuring<br>◇ Reuse / fabricate | **Measure** | Fabricate the professor’s offered aluminum into a 260 × 340 mm panel with 10 mm corner chamfers. The 1.89738 mm thickness is a provisional template, not measured stock. Verify thickness, stiffness, the 229.8 × 325.3 mm M5 support pattern and the aluminum-compatible PE bond before cutting. [panel](https://www.budind.com/wp-content/uploads/2019/01/hbnbf32226.pdf), [carrier](https://www1.futureelectronics.com/doc/WAGO/221-505.pdf) | Reuse proposed, not received or measured. Verify mounting pattern, bonding, screw stacks and stiffness before fabrication. |
| [Q0 operating breaker](index.html#material-breaker)<br>Phoenix Contact TMC 81C 15A · 2907571<br>□ To buy | **Conditional** | 15 A, one pole, C curve, UL489 / cUL Listed E320373; 10 kA, 277 V AC. Consolidates the breaker into the existing DigiKey order. Manufacturer STEP defines the wall opening, short DIN rail and bonded aluminum bracket. Review the thermal-magnetic curve against startup and original voltage-lead protection. [phoenix-q0](https://www.phoenixcontact.com/en-us/products/thermomagnetic-device-circuit-breakers-tmc-81c-15a-2907571), [q0-buy](https://www.digikey.com/en/products/detail/phoenix-contact/2907571/6109707) | DigiKey direct stock: material price $21.57; 3,689 in stock when checked 2026-09-29. Reconfirm price and stock before ordering. Shipping, tariffs, sales tax and fabrication are excluded from the selection total. |
| [XA adapter receptacle](index.html#material-receptacle)<br>Leviton 515CV · internal NEMA 5-15R<br>□ To buy | **Conditional** | Use a complete cord connector inside the box, matching the printer output connector SKU. A dedicated 14/3 SJOOW branch connects JL/JN/PE to XA upstream of CT. The connector body encloses its terminals and clamps the cord jacket. No wall outlet, custom bracket or wall cutout. [outlet](https://leviton.com/products/515cv), [outlet-drawing](https://leviton.com/content/dam/leviton/residential/product_documents/none/Document-31435-Dimensional%20Data.jpg), [outlet-install](https://leviton.com/content/dam/leviton/residential/product_documents/instruction_sheet/515_Instruction_Sheet.pdf), [cord](https://cabletechsupport.southwire.com/cablespec/download_spec/?country=US&spec=70126) | Catalog UL498 File E13393 / CSA LR-406. Verify the cord clamp and secure both XA and the adapter on the panel; plugs remain fully seated. |
| [Distribution connectors](index.html#material-connectors)<br>WAGO 221-415<br>□ To buy | **Conditional** | One five-port connector each for JL, JN and PE. JL accepts Q0 output, printer hot, A1 and adapter hot; JN accepts supply, printer, A2, A3 and adapter neutrals; PE accepts supply, printer, panel, outlet and Q0-mount earth (all five PE ports used). One accepted conductor per port. Confirm original DENT pigtail preparation and protective-bonding suitability. [wago](https://www.wago.com/us/wire-splicing-connectors/compact-splicing-connector/p/221-415) | Three mounting positions in the panel drawing. Conductor acceptance is checked at assembly. |
| [Connector carriers](index.html#material-carriers)<br>WAGO 221-505<br>□ To buy | **Conditional** | Three 221-505 carriers, each with two M3 fasteners. [carrier](https://www1.futureelectronics.com/doc/WAGO/221-505.pdf) | Transfer-drill actual fixing holes and verify underside fastener clearance. |
| [Supply / printer / internal XA cord](index.html#material-cord)<br>Southwire 55808699 · 14/3 SJOOW<br>□ To buy | **Conditional** | Use the same 14/3 SJOOW cord for all three runs. XA’s jacket enters its integral cord clamp; branch conductors terminate at JL/JN/PE before CT. Nominal OD approximately 9.17 mm is inside the 515CV 6.22–16.64 mm clamp range. Final route lengths are dry-fit allowances. [outlet](https://leviton.com/products/515cv), [outlet-drawing](https://leviton.com/content/dam/leviton/residential/product_documents/none/Document-31435-Dimensional%20Data.jpg), [outlet-install](https://leviton.com/content/dam/leviton/residential/product_documents/instruction_sheet/515_Instruction_Sheet.pdf), [cord](https://cabletechsupport.southwire.com/cablespec/download_spec/?country=US&spec=70126) | Selected length allowance; final ends trimmed only after dry routing. |
| [Supply plug](index.html#material-supply-plug)<br>Leviton 515PV · NEMA 5-15P<br>□ To buy | **Catalog match** | 515PV is grounded NEMA 5-15P, 15 A / 125 V; 14 AWG and the 9.17–9.27 mm jacket fall within its listed acceptance ranges. [plug](https://leviton.com/content/dam/leviton/residential/product_documents/instruction_sheet/515_Instruction_Sheet.pdf) | Confirm the lab receptacle and complete the specified termination, torque, cord grip and polarity checks. This design remains 120 V only. |
| [Printer output connector](index.html#material-printer-connector)<br>Leviton 515CV · NEMA 5-15R<br>□ To buy | **Conditional** | 515CV is grounded NEMA 5-15R and matches 515PV cable acceptance. It receives the printer’s original mains plug. [plug](https://leviton.com/content/dam/leviton/residential/product_documents/instruction_sheet/515_Instruction_Sheet.pdf) | Verify all three actual printer cords have the matching grounded US plug. No voltage-conversion adapters or simultaneous multi-printer outlet strip are assumed. |
| [Mains / printer strain relief](index.html#material-cord-glands)<br>Heyco M3231 × 2 + 8463 locknuts × 2<br>□ To buy | **Conditional** | DigiKey direct-stock replacement for the factory-stock Hammond part. 1/2 NPT, 15.5 mm thread, Ø22.2 mm mounting bore. Published 4.32–11.43 mm seal range contains the nominal 9.2 mm SJOOW cord. [gland](https://www.heyco.com/products/liquid-tight-cordgrips/nylon-cordgrips/heyco-tite-liquid-tight-cordgrips-straight-thru-npt-hubs/), [gland-nut](https://www.heyco.com/products/liquid-tight-flexible-conduit-tubing-fittings/accessories/heyco-nylon-locknuts-npt-thread/), [cord](https://cabletechsupport.southwire.com/cablespec/download_spec/?country=US&spec=70126) | September 29: M3231 $1.44, 13,830 in direct stock; 8463 $0.32, 66,153 in direct stock. Locknuts are separate purchases. Confirm the UL-approved cable range, grip and sealing with the actual cord. |
| [Existing USB data cable](index.html#material-usb)<br>Existing USB-A to USB-B data cable · retain full length<br>✓ Owned | **Conditional** | Reuse the one existing DENT USB-A to USB-B cable without cutting or splicing it. USB-B stays connected to DENT inside; the same cable passes through the wall and ends in USB-A outside. After printer shutdown, Q0 OFF and unplug SUPPLY IN, connect the free USB-A end to the PC. Disconnect from the PC before restoring mains; the cable stays on the box. [usb](https://www.dentinstruments.com/wp-content/uploads/EXC_ELOG19_11-15-24.pdf), [usb-original](https://www.dentinstruments.com/shop/powerscout-accessories/replacement-usb-a-to-b-communications-cable/), [usb-standard](https://www.usb.org/document-library/usb-20-specification) | User confirms the cable is owned. USB 2.0 Figure 6-10 gives an 11.5 × 10.5 mm maximum standard-B overmold (15.57 mm diagonal); Table 6-5 gives nominal cable ODs 4.06–5.21 mm. These are design references, not measurements of this cable. Check passage, condition, usable reach and accepted internal insulation before assembly. |
| [Internal L / N / PE wire](index.html#material-internal-wire)<br>Southwire 14 AWG, 19-strand Class C, THHN/THWN/MTW, 600 V<br>□ To buy | **Conditional** | Separate 14 AWG conductors remain for Q0 OUT → JL and PE → panel and PE → rail/bracket. XA hot, neutral and PE are the conductors of its 14/3 cord; no separate white roll is required. Both lengths are included in the purchase budget. [wire](https://www.southwire.com/wire-cable/building-wire/thhn-thwn-copper-silicone-free/p/22955984), [wago](https://www.wago.com/us/wire-splicing-connectors/compact-splicing-connector/p/221-415), [ring](https://www.gardnerbender.com/en/p/15-104/-16-14-AWG-2-mm-sq-Bnes-%C3%A0-anneau) | Each 6 ft purchase covers the 1 m cutting allowance plus spare wire. Champaign store pickup is required. Confirm received wire markings and crimp fit. |
| [Ring terminals](index.html#material-ring-lugs)<br>Gardner Bender 15-104 · #8–10 stud, 16–14 AWG<br>□ To buy | **Conditional** | Two #8–10 rings fit the dedicated #10 panel and rail/bracket bond studs. The Phoenix screw-clamp terminals accept bare prepared copper and do not use ring lugs. Aluminum and steel contact methods still need electrical acceptance. [ring](https://www.gardnerbender.com/en/p/15-104/-16-14-AWG-2-mm-sq-Bnes-%C3%A0-anneau), [wire](https://www.southwire.com/wire-cable/building-wire/thhn-thwn-copper-silicone-free/p/22955984) | Manufacturer: UL listed, CSA listed, 600 V building wire, 75°C. Use the specified insulated-terminal crimp tooling; inspect wire insertion, insulation fit and pull retention. No unpublished barrel diameter or crimp setting is assumed. |
| [Screw-fixed cable mounts](index.html#material-tie-mounts)<br>Panduit TM2S8-C<br>□ To buy | **Conditional** | Six screw-fixed bases retain the mains bundle, XA branch conductors, CT pair, both sides of the voltage-lead coils, and the original internal DC cable and sleeved USB lead. DigiKey lists individual pieces, avoiding the previous 100-piece purchase. [mount](https://www.panduit.com/content/dam/panduit/en/website/support/catalogs/pdf/iei-catalog-2023-web-cpcb294-sa-eng.pdf) | Six panel locations; M4 × 10 mm screws, underside washers and locknuts in the fastener schedule. |
| [Cable ties](index.html#material-cable-ties)<br>Panduit PLT2S-C · 188 × 4.8 mm<br>□ To buy | **Conditional** | For small wire bundles and the screw-fixed bases. Keep allowed bend radii and avoid crushing insulation. This length is for cables, not a strap around the meter. [ties](https://www.panduit.com/content/dam/panduit/en/products/media/2/92/492/0492/30492.pdf), [mount](https://www.panduit.com/content/dam/panduit/en/website/support/catalogs/pdf/iei-catalog-2023-web-cpcb294-sa-eng.pdf) | DigiKey lists individual ties: ten cost $3.16 at the 10-piece tier. No 100-piece pack required. Check actual bundle retention and bend radii. |
| [Mounting and bonding hardware](index.html#material-fasteners)<br>Screws, nuts and washers<br>□ To buy | **Conditional** | Six M3 carrier sets, seven M4 anchor/rail sets, four M5 × 10 panel screws, four M5 × 12 post screws, six M5 flat washers and two #10 PE studs. No lab hardware stock assumed. [carrier](https://www1.futureelectronics.com/doc/WAGO/221-505.pdf), [mount](https://www.panduit.com/content/dam/panduit/en/website/support/catalogs/pdf/iei-catalog-2023-web-cpcb294-sa-eng.pdf) | Verify actual stock, full locknut engagement and enclosure-floor clearance. Accept aluminum-compatible bonding on both custom metal parts before use. |
| [Adjustable equipment straps](index.html#material-logger-restraint)<br>VELCRO ONE-WRAP 90340 · 19.05 mm (3/4 in) wide roll<br>□ To buy | **Conditional** | Two straps retain the logger; one retains XA and one retains the adapter. Use eight smooth 21 × 4 mm slots, with each pair oriented to the illustrated strap. Fit, trim and verify retention without covering labels or overheating the adapter. No drilling into the equipment. [restraint](https://www.velcro.com/products/organization/heavy-duty-one-wrap-roll/), [dent-size](https://www.dentinstruments.com/wp-content/uploads/ELITEproXC_Datasheet_01272026.pdf) | Four straps proposed; actual fit, plug retention and temperature remain physical checks. |
| [Internal USB insulation sleeve](index.html#material-usb-sleeve)<br>Alpha Wire F2213/4 BK105 · black FIT-221, 600 V<br>□ To buy | **Conditional** | DENT requires suitably rated insulation on USB cable used inside an electrical panel. Retain the selected black 600 V tubing only on the internal portion of the existing cable, across the wall edge and at the DENT termination. The exterior free cable does not require an extra purchased lead. Approve sleeve application and complete coverage on the actual cable. [usb-sleeve](https://www.alphawire.com/products/accessories/fit-heat-shrink-tubing/shrink-tubing/fit2213_4) | Assembly acceptance required: measure connector passage, full coverage and end retention. Approve the recovery process for the cable/connector materials; do not infer heat-application safety from continuous operating ratings. |
| [USB cable edge-protection bushing](index.html#material-usb-bushing)<br>Heyco 3104 · SBT 875-11 · thick-panel snap bushing<br>□ To buy | **Conditional** | One intact existing USB cable passes directly through this insulating bushing. Nominal mounting hole 22.2 mm; passage 17.5 mm, head 24.2 mm, height 14.3 mm; accepts walls up to 6.4 mm. The standard USB-B overmold diagonal is 15.57 mm, leaving 1.93 mm nominal diametral passage margin. This is edge protection, not a cable clamp or ingress seal. [usb-bushing](https://www.heyco.com/products/bushings-grommets-heycaps-plugs/tubing-caps-and-plugs/heyco-thick-panel-snap-bushings/), [usb-standard](https://www.usb.org/document-library/usb-20-specification) | DigiKey lists 6,537 in stock at $0.14 for one on 2026-09-23; recheck at checkout. Dry-fit the intact USB-B plug through the loose bushing before sleeving. Confirm received-bushing fit, insulation coverage and cable retention before drilling. |
| [Q0 DIN rail and end stops](index.html#material-breaker-rail)<br>Phoenix Contact 1207639 + Altech CA802 × 2<br>□ To buy | **Conditional** | 35 × 7.5 × 1 mm galvanized steel rail. Buy the complete 250 mm piece for $4.79; two $0.62 CA802 stops restrain the breaker laterally. The short stock avoids adding a one-metre package to the enclosure shipment. [rail-buy](https://www.digikey.com/en/products/detail/phoenix-contact/1207639/10645207), [stop](https://legacy.altechcorp.com/Blocks/Block-Accessories.pdf) | September 29 direct stock: 2,061 rails and 6,001 stops; $4.79 + 2 × $0.62 = $6.03. Cut and deburr the rail before fitting. |
| [Q0 flat aluminum bridge](index.html#material-breaker-mount)<br>Professor-supplied aluminum · 88 × 40 × nominal 1.89738 mm<br>◇ Reuse / fabricate | **Measure** | Cut-and-drill flat bridge, supported by two purchased 65 mm M5 steel posts. No bending, tapped holes or fabricated angle brackets. Measure the offered sheet before machining. [post](https://www.we-online.com/components/products/datasheet/970xxxxx1_overview.pdf), [phoenix-q0](https://www.phoenixcontact.com/en-us/products/thermomagnetic-device-circuit-breakers-tmc-81c-15a-2907571) | Digital geometry only. Check actual thickness, stiffness, washer stack, operator travel and accepted bonding. Shop labor excluded. |
| [Q0 threaded support posts](index.html#material-breaker-posts)<br>Würth 970650581 · M5 female/female · 65 mm<br>□ To buy | **Conditional** | Two zinc-plated steel SW8 hex posts hold the flat bridge at the required DIN-rail depth. M5 internal thread depth 11 mm per end; no bending or tapping required. [post](https://www.we-online.com/components/products/datasheet/970xxxxx1_overview.pdf) | 67 in DigiKey direct stock; $1.39 each, checked September 29, 2026. Verify screw engagement, wall loading and accepted PE continuity through the metal support. |

## Receiving and commissioning items

- CT commissioning: Mini HSC family is matched; 50 A is probable. Read the unobscured label during assembly and set that exact range/output in ELOG.
- Voltage-lead acceptance: the user confirms the original DENT kit pigtails; do not re-request OEM identity. Accept terminal preparation and upstream-only protection with responsible electrical personnel; original-kit status alone does not establish protection by the 15 A main breaker.
- Measure aluminum sheet size, thickness and stiffness; approve aluminum-compatible panel bonding and adjust machining/fasteners before fabrication.
- Verify internal XA/adapter seating, independent restraint, intact DC cable slack, separation and closed-enclosure temperature. Clear cover allows visual inspection; verify recording by offline export after the pilot.
- Commissioning: verify fastener stacks, CT latch and cable slack, supply conditions, PE/insulation/polarity, total load and restart/recording behavior before routine operation.
- USB assembly: verify B-out/A-in orientation, received cable/sleeve dimensions, accepted sleeve application and end coverage, retention, separation and shield treatment. Prove setup/export with mains unplugged and the lid closed; then disconnect its exterior USB-A end from the PC before restoring mains. No isolation or ingress rating is claimed.
- Measure Q0/rail engagement, bracket wall fit, operator travel and support stiffness; accept the rail, bridge and both steel-post bonding paths. Recheck the Phoenix C curve against printer startup; Carling pulse-tolerance evidence no longer applies.

Record receiving checks, update any affected drawings if substitutions are needed, then conduct a documented dry fit and qualified electrical acceptance. There is no hardware test result or energizing approval in this audit.

## Reproduce the checks

Run `node tools/audit_installation.mjs` and `node --test tools/test_installation.mjs`. Run the browser checks after regenerating drawings; `EXPORT_AUDIT=1` refreshes the rendered cable measurements from the local model. Then run `node tools/render_documents.cjs`. Software passes describe only the tested geometry / website behavior.

[Review data and primary links](installation_review.json) · [Geometry check results](installation_checks.json) · [3D layout](index.html#layout)

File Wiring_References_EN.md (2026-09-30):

# Sources and design decisions

September 23, 2026. One 120 V grounded supply and one printer at a time, confirmed by the user. This is an engineering review package; physical and electrical release remain open in the [build package](build.html).

## Primary references

| ID | Source | Used for | Evidence limit |
|---|---|---|---|
| R1 | [DENT XC / ELOG 19 manual](https://www.dentinstruments.com/wp-content/uploads/EXC_ELOG19_11-15-24.pdf), single-phase figure at PDF page 54 | L1 = hot, L2 and N = neutral; CT white/+ and black/−; load-facing arrow; S is shield. | The actual CT range is hidden in the photograph. The project moves the voltage tap upstream of CT; that is a project adaptation. |
| R2 | [DENT XC current datasheet](https://www.dentinstruments.com/wp-content/uploads/ELITEproXC_Datasheet_01272026.pdf) | Current body 216 × 63 × 47 mm, USB-B, DC input 6–10 V / 500 mA and L1–L2 line power. | Older instrument dimensions differ. The meter's internal fuse does not establish protection of the external small leads. |
| R3 | [DENT voltage lead accessory](https://www.dentinstruments.com/shop/elitepro-accessories-replacement-parts/replacement-unterminated-voltage-leads-10-for-elitepro-series/) | LD-SKTSP family, 10 in / 254 mm nominal: terminal end to full voltage lead. | User confirms the original DENT kit pigtails in different colors; photo and ESIS card match the family. AWG/ampacity and permitted tinned-end preparation are not published on this page. |
| R4 | [Leviton 515CV](https://leviton.com/products/515cv), [dimensional drawing](https://leviton.com/content/dam/leviton/residential/product_documents/none/Document-31435-Dimensional%20Data.jpg) | Internal XA; 66.3 mm length, 39.1 mm maximum diameter; UL498 File E13393 / CSA LR-406. | Existing adapter fit, mated depth, strap restraint and cord clamp need a physical check. |
| R5 | [Leviton 515PV / 515CV instructions](https://leviton.com/content/dam/leviton/residential/product_documents/instruction_sheet/515_Instruction_Sheet.pdf) | Supply plug and printer cord connector; wire identification and jacket clamp. | Confirm the purchased cord jacket clamps correctly. |
| R6 | [Phoenix TMC 81C 15A / 2907571](https://www.phoenixcontact.com/en-us/products/thermomagnetic-device-circuit-breakers-tmc-81c-15a-2907571), [manufacturer STEP](fabrication/phoenix-2907571-reference.step) | UL489 / cUL Listed E320373, 15 A, 1P C curve, 277 V AC, 10 kA; 17.6 × 116 × 75.9 mm including rail. Screw centers 67.8 mm from STEP; 11–12 mm strip, 2 N·m. | Confirm received dimensions, startup curve and installed protection; no former Carling pulse claim retained. |
| R7 | [BUD NBF-32226 product / linked STEP](https://www.budind.com/product/nema-ip-rated-boxes/nbf-series-fiberglass-enclosure/nbf-32226/), [common-base drawing](https://www.budind.com/wp-content/uploads/2019/01/hbnbf32226.pdf) | 400 × 300 × 160 mm case; 3 mm wall; M5 support pattern. Custom 260 × 340 mm panel with 10 mm corner chamfers. | Manufacturer-linked series shell and clear lid at full scale; original filename hbnbf32026.step. Stock thickness and received-part fit remain unverified. No finished-assembly certification. |
| R10 | [WAGO 221-415](https://www.wago.com/us/wire-splicing-connectors/compact-splicing-connector/p/221-415), [221-505 drawing](https://www1.futureelectronics.com/doc/WAGO/221-505.pdf) | Three connector/carrier pairs: JL, JN and PE. Carrier 35 × 16.9 × 52.8 mm. | Transfer-drill carrier fixings; one accepted conductor per port. Existing tinned pigtail ends are not presumed accepted. |
| R11 | [DENT Mini HSC family](https://www.dentinstruments.com/shop/current-sensors/hinged-current-transformers-sensors-for-energy-metering/), [legacy body drawing](https://www.dentinstruments.com/wp-content/uploads/2022/08/20A_Mini_Hinged_CT_Specs.pdf) | Matched Mini HSC body 26.4 × 29.4 × 41.7 mm, nominal Ø10 mm aperture (legacy 10.2 mm). | 20 A and 50 A share the body; photo suggests legacy 50 A, but the obscured variant must be confirmed before ELOG scaling. |
| R12 | [Heyco M3231 + 8463](https://www.heyco.com/products/liquid-tight-cordgrips/nylon-cordgrips/heyco-tite-liquid-tight-cordgrips-straight-thru-npt-hubs/) | Two 15.5 mm thread cordgrips with separate 1/2 NPT locknuts; Ø22.2 mm bores. | Measure actual cord and wall stacks; no DC feedthrough; USB uses a protected direct-cable opening. |
| R13 | [CUI original SMI6 drawing](https://www.belfuse.com/media/datasheets/products/power-supplies/SMI6.pdf) | SMI6-9-V-P5 dimensions, 9 V model, P5 center-positive 5.5/2.1 mm plug and UL2468 cord. Official Bel/CUI archive for the original SMI6. | Use the original SMI6, not the different SMI6B. Body envelope 64 × 40.5 × 30 mm excludes blades; drawing tolerance ±1 mm. |
| R14 | [VELCRO ONE-WRAP](https://www.velcro.com/products/organization/heavy-duty-one-wrap-roll/) | 90340 black 12 ft × 3/4 in roll; cut two 400 mm strap blanks. | The 19.05 mm strap requires the revised 21 × 4 mm slots. Verify overlap and retention on the actual meter. |
| R15 | [Material costs and seller comparison](revision.html) | Selected Phoenix breaker, installation materials and seller count. | Dated material prices; shipping, tariffs, sales tax, fabrication and labor excluded. |
| R16 | [DENT XC manual](https://www.dentinstruments.com/wp-content/uploads/EXC_ELOG19_11-15-24.pdf) | Included 1.8 m USB-A to B cable; USB powers the meter for configuration/download. Internal non-volatile memory supports independent logging. | Supplied USB requires rated insulation inside a powered panel. One existing cable remains attached to the box, sleeved on its internal portion. Disconnect its exterior USB-A end from the PC during mains operation; export with the lid closed and mains unplugged. |
| R17 | [Heyco thick-panel snap bushings](https://www.heyco.com/products/bushings-grommets-heycaps-plugs/tubing-caps-and-plugs/heyco-thick-panel-snap-bushings/) | 3104 / SBT 875-11: 22.2 mm mounting hole, 17.5 mm passage, 24.2 mm head, 14.3 mm height; maximum wall 6.4 mm. UL Recognized E15331, CSA 8919. | Edge protection only; no cable clamping, ingress seal or assembly certification. Reuse the existing cable restraint. |
| R18 | [USB 2.0 specification](https://www.usb.org/document-library/usb-20-specification), Figure 6-10 / Table 6-5 ([specification PDF mirror](https://eater.net/downloads/usb_20.pdf#page=128)); [DENT original cable](https://www.dentinstruments.com/shop/powerscout-accessories/replacement-usb-a-to-b-communications-cable/) | Standard-B overmold maximum 11.5 × 10.5 mm; nominal cable OD 4.06–5.21 mm by conductor size. DENT confirms standard A-to-B. | These published envelopes support the passage design; they are not measurements of the owned cable. Kit documentation says 1.8 m and current replacement says 2 m; retain the full actual cable. |
| R19 | [Alpha Wire black FIT-221-3/4](https://www.alphawire.com/products/accessories/fit-heat-shrink-tubing/shrink-tubing/fit2213_4) | UL224 / CSA198, 600 V sleeve; order F2213/4 BK105. | Full internal coverage, protected ends, retention and thermal application must be accepted. No installed-assembly qualification is claimed. |

The [per-material audit](installation.html) also links primary cord, wire, ring, cable-tie and printer sources. Retail links are in the [materials list](materials.html). Source documents describe components, not approval of this custom assembly.

## Supplied-photo evidence

The instrument markings identify ELITEpro XC, voltage sockets N / L3 / L2 / L1, the CT input block, a separate analog block, USB-B and the DC input. The full-resolution adapter photograph identifies **CUI SMI6-9-V-P5, 9 V DC, 0.667 A, center positive**. The user confirms six owned equipment groups, including the existing USB cable and identifies the three differently colored pigtails as original DENT kit components.

The partially visible CT label suggests the legacy 50 A model, but the full variant is physically obscured by black/white wires. The voltage-pigtail photograph has no legible conductor or current rating. Ruler photographs are not calibrated dimension drawings. Packaging text is evidence about an accessory, not an instruction to the assistant or proof that an arbitrary breaker protects it.

## Project choices

- Q0 is the single operating breaker. JL branches to printer hot through CT, the dedicated adapter outlet, and A1. Neutral and PE remain separate; PE stays continuous. Unplug the supply and verify absence of voltage before opening the latched cover. Q0 OFF alone does not isolate incoming terminals.
- A1 connects directly to JL after Q0, then to L1 through the original full voltage lead. Acceptance of upstream-only protection is required before use. A2 and A3 connect JN to L2 and N. The three OEM pigtails are sensing accessories, not load wires or PE conductors. Keep the mating pairs inside the enclosure.
- Only printer hot crosses CT once. Adapter and voltage-tap branch currents are outside the measured current. Voltage is sensed upstream, so downstream cord loss and voltage drop still affect the measurement boundary.
- XA is an internal Leviton 515CV cord connector. Its ground contact, printer earth and aluminum panel receive deliberate PE connections. Two 515CV connectors are required total.
- The original adapter and flat DC cable remain intact inside. The original DC plug connects directly to the logger. The outlet and supply share Q0's capacity. XA is for the logger adapter only. Keep DC separated from mains. External USB is connected only with mains unplugged; the lid stays closed. Disconnect the PC before restoring power. The internal portion of the same USB cable remains sleeved and secured.
- ELOG must be configured and validated before routine use. Powering the instrument is not proof that recording started. Verify CT scaling, polarity, reference readings and restart behavior.

## Digital checks and limits

`layout_dimensions.json` supplies the body locations for the 3D scene and wiring plan. Rear is at the top of both plan views. Browser checks compare actual rendered body bounds with SVG footprints for the 18 modeled envelopes; schematic terminal symbols and wire bends are simplified.

The BUD manufacturer-linked common-base STEP is used at full scale. Project machining is generated with build123d 0.11.1; the case and panel are tessellated at 0.3 mm. Cover and latch meshes use the same 0.3 mm tessellation. Numerical surface-contact exclusion at the seated panel is 0.0001 mm; these values are not manufacturing tolerances. Exact STEP cut-through gauges and the dated source hash are in `fabrication/cad-checks.json`.

Nominal insertion sweeps are recorded in the current installation audit after excluding intentional panel-support contact. Install and restrain XA on the panel; there is no side outlet. Lid checks use nine sampled rays per body. These are geometric screens, not tolerance, thermal, electrical-clearance or flexible-cable proofs. The 2 m / 3 mm voltage-lead coil is an illustrative storage scenario, not a measurement of the supplied cables.

The circuit checker validates 22 named paths, including independent PE to the added metalwork, separated nets, printer-hot-only CT routing and Q0-open behavior. Regression tests reject selected wiring mistakes. Website tests verify gestures, views, alignment, images, links and responsive layout. No check constitutes a physical dry fit or energized acceptance result. See the [build package](build.html) for the exact remaining work.

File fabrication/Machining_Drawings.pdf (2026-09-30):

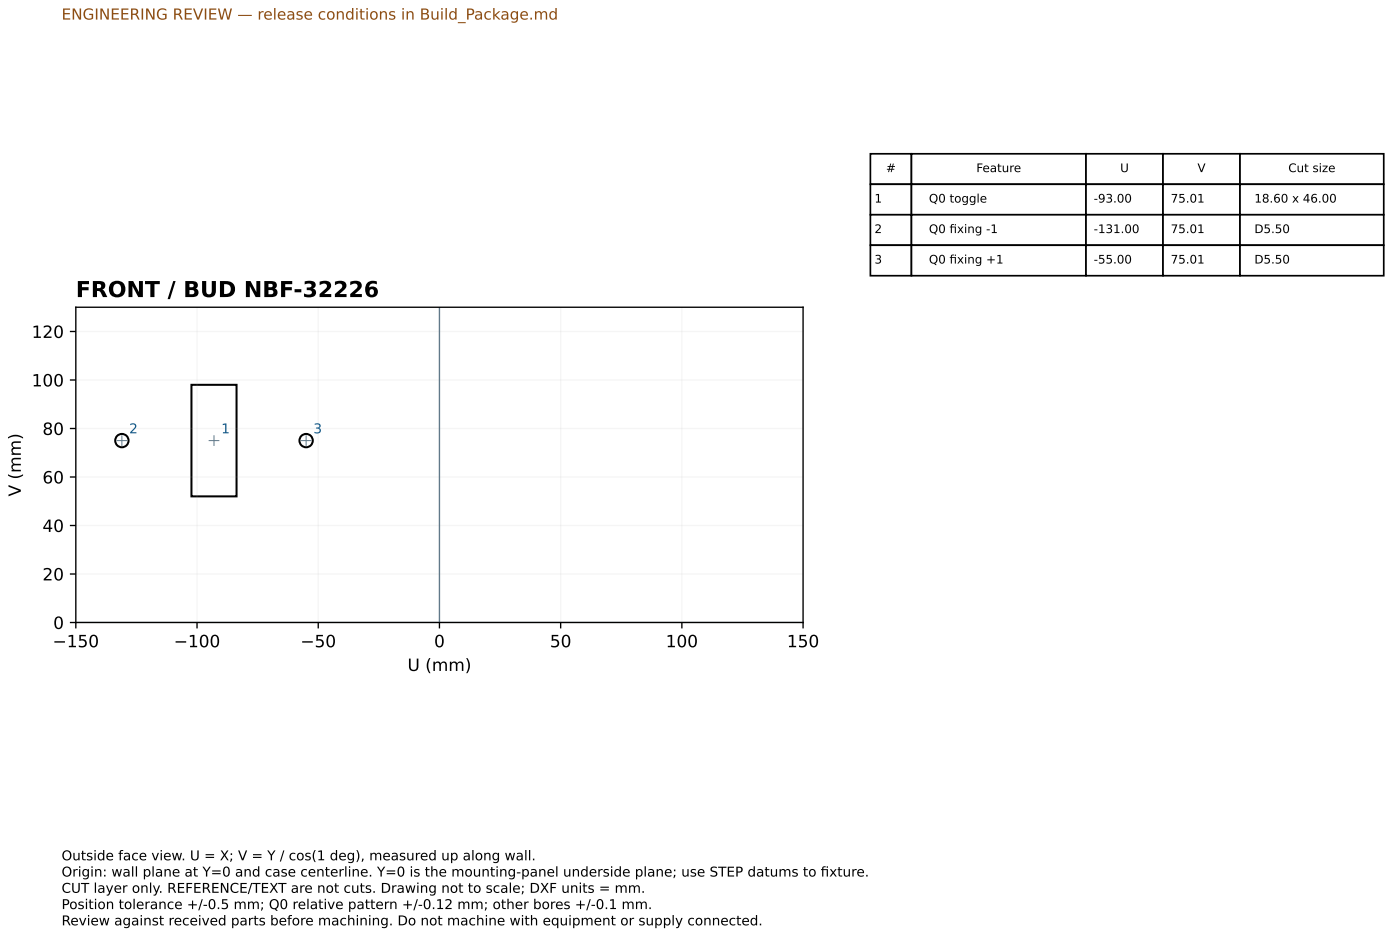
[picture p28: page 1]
Feature; Cut size; Q0 toggle; Q0 fixing -1; Q0 fixing +1

ENGINEERING REVIEW — release conditions in Build_Package.md

FRONT / BUD NBF-32226

Outside face view. U = X; V = Y / cos(1 deg), measured up along wall.
Origin: wall plane at Y=0 and case centerline. Y=0 is the mounting-panel underside plane; use STEP datums to fixture.
CUT layer only. REFERENCE/TEXT are not cuts. Drawing not to scale; DXF units = mm.
Position tolerance +/-0.5 mm; Q0 relative pattern +/-0.12 mm; other bores +/-0.1 mm.
Review against received parts before machining. Do not machine with equipment or supply connected.

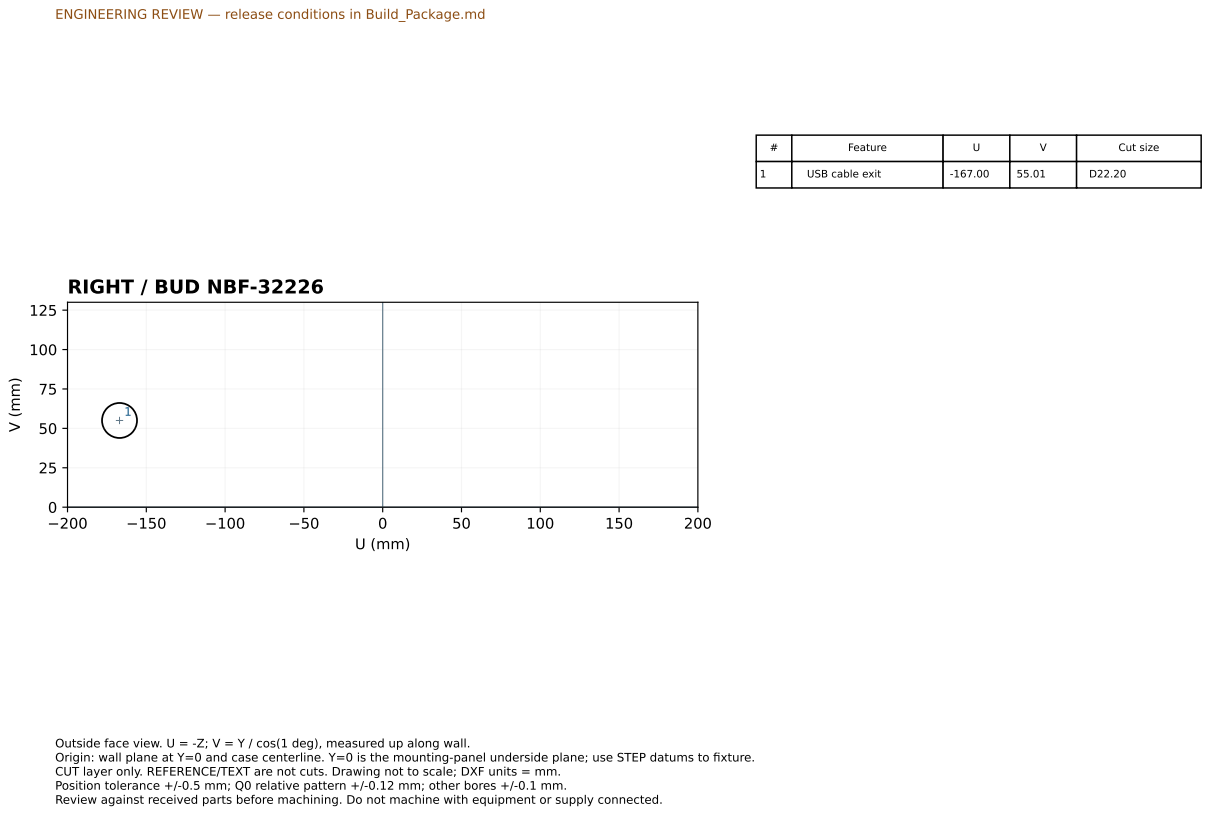
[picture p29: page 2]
Feature; Cut size; USB cable exit

RIGHT / BUD NBF-32226

Outside face view. U = -Z; V = Y / cos(1 deg), measured up along wall.
Origin: wall plane at Y=0 and case centerline. Y=0 is the mounting-panel underside plane; use STEP datums to fixture.
CUT layer only. REFERENCE/TEXT are not cuts. Drawing not to scale; DXF units = mm.

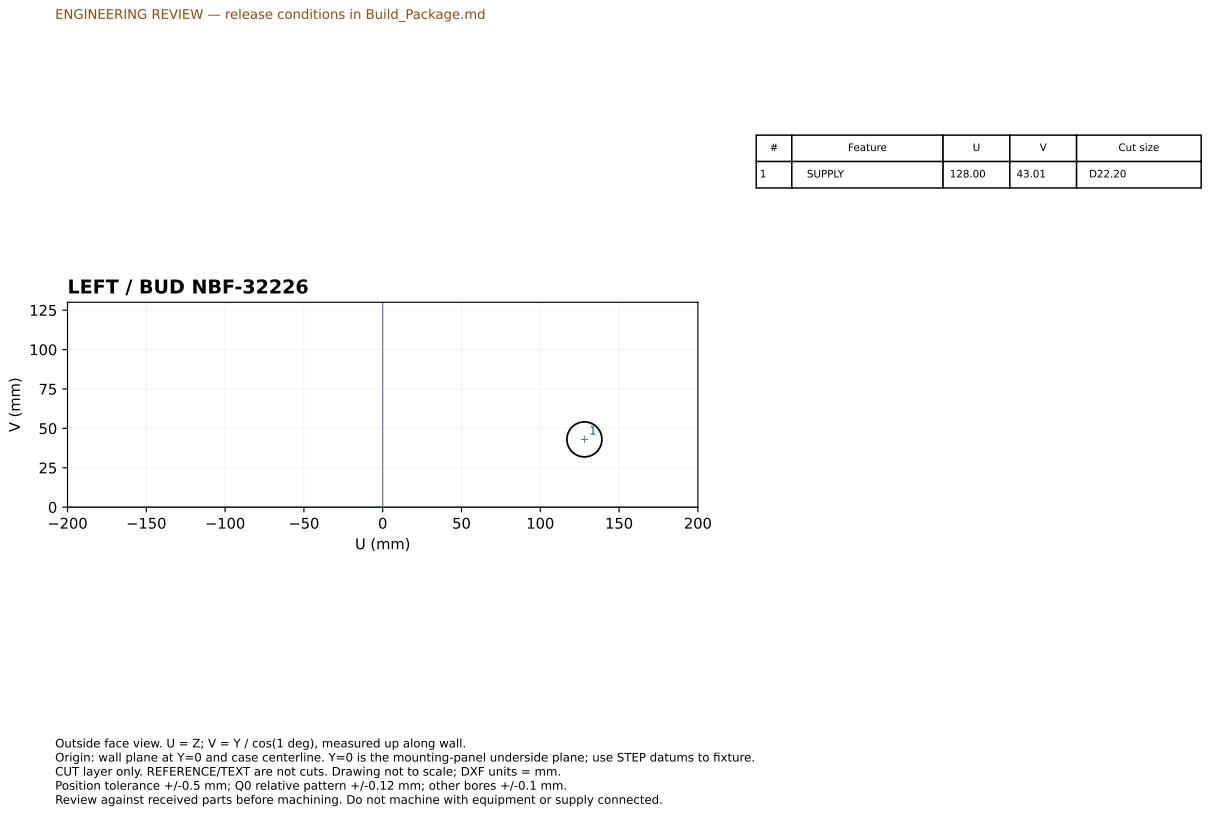
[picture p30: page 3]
Feature; Cut size; SUPPLY

LEFT / BUD NBF-32226

Outside face view. U = Z; V = Y / cos(1 deg), measured up along wall.
Origin: wall plane at Y=0 and case centerline. Y=0 is the mounting-panel underside plane; use STEP datums to fixture.
CUT layer only. REFERENCE/TEXT are not cuts. Drawing not to scale; DXF units = mm.

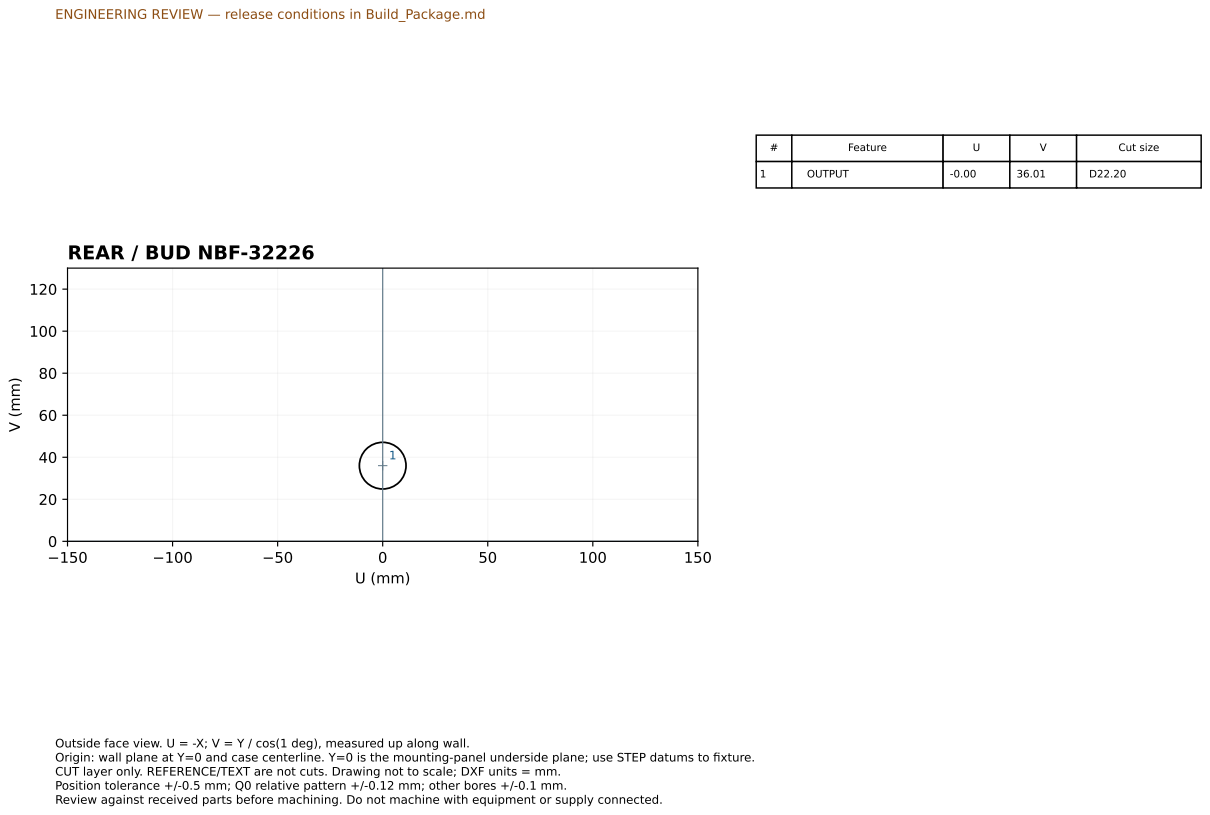
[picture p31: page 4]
Feature; Cut size; OUTPUT

REAR / BUD NBF-32226

Outside face view. U = -X; V = Y / cos(1 deg), measured up along wall.
Origin: wall plane at Y=0 and case centerline. Y=0 is the mounting-panel underside plane; use STEP datums to fixture.
CUT layer only. REFERENCE/TEXT are not cuts. Drawing not to scale; DXF units = mm.

150

# PANEL / BUD NBF-32226

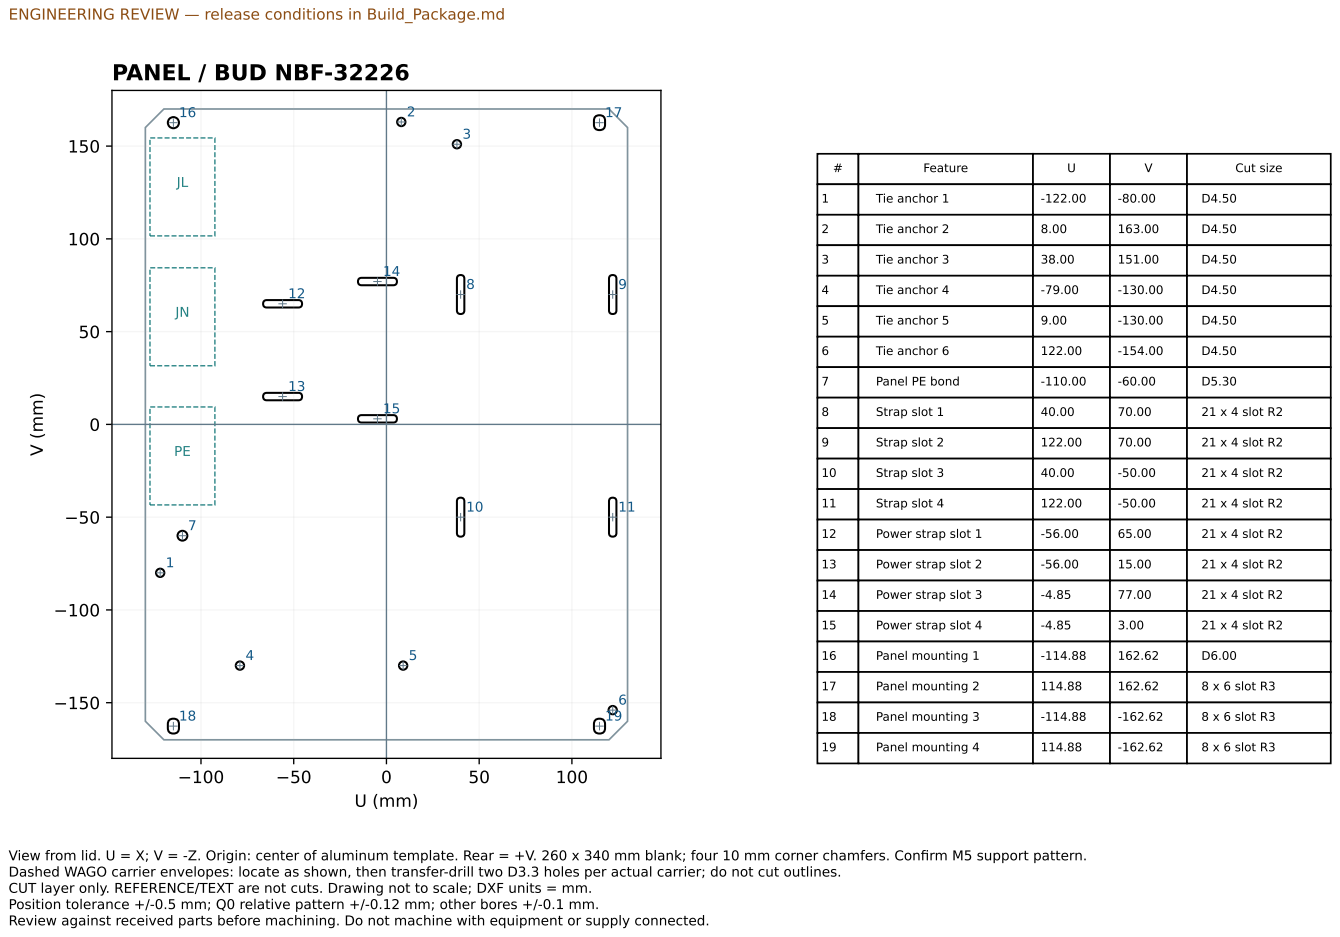
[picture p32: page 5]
Feature; Cut size; Tie anchor 1; Tie anchor 2; Tie anchor 3; Tie anchor 4; Tie anchor 5; Tie anchor 6; Panel PE bond; Strap slot 1; 21 x 4 slot R2; Strap slot 2; Strap slot 3; Strap slot 4; Power strap slot 1; Power strap slot 2; Power strap slot 3; Power strap slot 4; Panel mounting 1; Panel mounting 2; 8 x 6 slot R3; Panel mounting 3; Panel mounting 4

View from lid. U = X; V = -Z. Origin: center of aluminum template. Rear = +V. 260 x 340 mm blank; four 10 mm corner chamfers. Confirm M5 support pattern.
Dashed WAGO carrier envelopes: locate as shown, then transfer-drill two D3.3 holes per actual carrier; do not cut outlines.
CUT layer only. REFERENCE/TEXT are not cuts. Drawing not to scale; DXF units = mm.

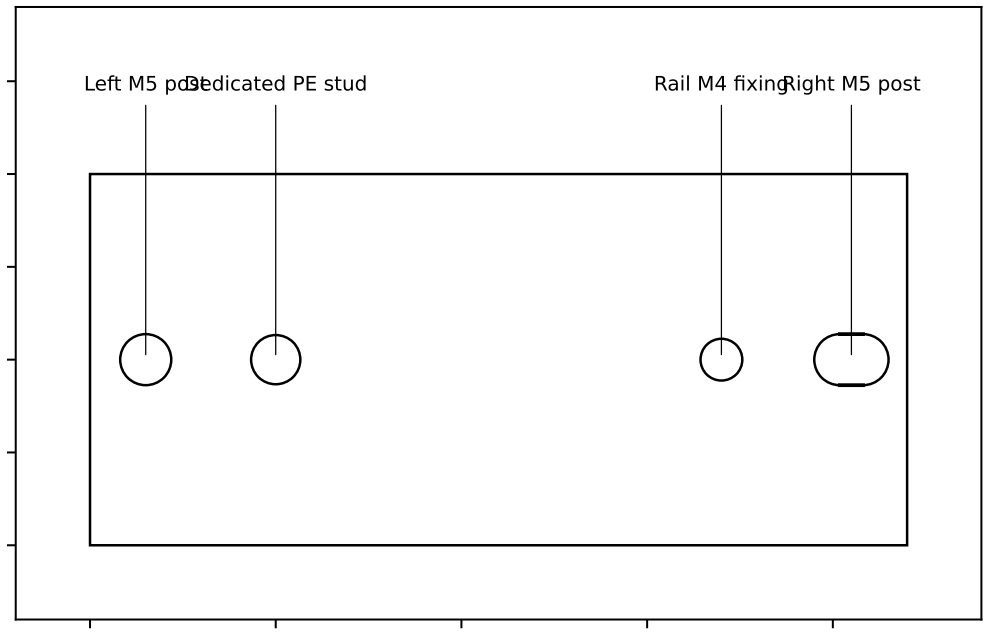
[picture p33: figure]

0 | 20 | 40 | 60 | 80

### X from left edge (mm)

0

10

20

30

40

50

### Y from bottom edge (mm)

Left M5 post Dedicated PE stud | Rail M4 fixingRight M5 post
Feature | X | Y | Cut
Left M5 post | 6.00 | 20.00 | Ø5.5
Dedicated PE stud | 20.00 | 20.00 | Ø5.3
Rail M4 fixing | 68.00 | 20.00 | Ø4.5
Right M5 post | 82.00 | 20.00 | 8 × 5.5 slot

# Q0 FLAT ALUMINUM BRIDGE / CUT AND DRILL

Blank 88 × 40 mm; nominal t=1.89738 mm. Two purchased 65 mm M5 posts. No bends or tapped holes.

Measure offered aluminum before cutting; update sheet thickness and screw engagement if needed. Deburr all edges. Right slot: drill two Ø5.5 bores 2.5 mm apart and join; final centers span 76 mm. Hole position ±0.12 mm.

Cut 60 mm from purchased 250 mm rail; transfer-drill at ±24 mm away from Q0 and end stops.
CUT layer contains only the outline and holes. Confirm operator travel, post retention and accepted PE contact stack.

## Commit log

2026-09-15 Publish interactive printer energy monitor wiring guide
2026-09-19 Add scaled interactive enclosure model and sourced materials list
2026-09-19 Align wiring plan with shared 3D component positions
2026-09-19 Add owned-equipment checklist and linked purchase BOM
2026-09-20 Add sourced material images and keep the website English-only
2026-09-20 Simplify the enclosure website and collapse supporting details
2026-09-20 Audit enclosure fit and add installation simulation with unresolved build gates
2026-09-20 Add adapter identification and detailed enclosure build review package
    [case-machined.step, case-machined.stl, front.dxf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]
2026-09-20 Identify photographed DENT accessories and specify round cable entries
2026-09-20 Link every material to its highlighted 3D installation locations
2026-09-20 Simplify materials and 3D controls with expandable details
2026-09-20 Simplify cable supports and route wires through modeled restraints
    [panel-machined.step, panel-machined.stl, panel.dxf]
2026-09-20 Simplify wiring annotations and add readable pan and zoom views
2026-09-20 Use kit USB offline and document protection verification
    [case-machined.step, case-machined.stl, right.dxf]
2026-09-20 Confirm original DENT multicolor voltage pigtails
2026-09-20 Simplify voltage tap and remove dedicated fuse hardware
    [panel-machined.step, panel-machined.stl, panel.dxf]
2026-09-21 Confirm Q0 purchase selection and remove material warning
2026-09-23 Revise enclosure design and procurement after professor review
    [case-machined.step, case-machined.stl, front.dxf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]
2026-09-23 Add closed-lid offline USB export and clarify printer connections
    [case-machined.step, case-machined.stl, right.dxf]
2026-09-23 Simplify offline export to one existing USB cable
    [case-machined.step, case-machined.stl, right.dxf]
2026-09-23 Remove redundant USB cable restraint notice
2026-09-24 Reduce three-seller material budget with stocked BUD enclosure
    [case-machined.step, case-machined.stl, front.dxf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]
2026-09-24 Link hardware purchases directly from the materials lists
2026-09-28 Clarify circuit tab highlighting and hide unrelated wiring
2026-09-29 Select Phoenix 2907571 and consolidate breaker procurement
    [case-machined.step, case-machined.stl, front.dxf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]
2026-09-29 Compare material totals separately from seller count
2026-09-30 Use clear-cover enclosure and no-bend Phoenix mounting
    [altech-ca802-reference.step, bud-nbf32226-reference.step, case-machined.step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]
2026-09-30 Add professor purchase request page and vendor workbook
    [purchase-request.xlsx]
2026-10-15 Use the official ELITEpro XC datasheet case for the owned logger
    Record serial XC1811023 and adopt the datasheet case (216 x 63 x 47 mm)
    by owner decision; the ELOG guides' 69 x 58 x 203 mm figure is noted.
    Logger straps and the meter dimension line now follow the meter size.
2026-11-11 Match the WAGO 221-505 carrier and its fixings to the data sheet
    The two M3 fixing openings sit inside the carrier body under the connector, 14.2 mm from the closed end and 20 mm apart. The end plate is a strain-relief plate, so wire ends now enter from that side. Carrier wording in the BOM, review and build package follows; generated documents and pages are rebuilt.
2026-11-11 Add delivery tick boxes to the materials list
    Each material row gets a Delivered checkbox. A tick changes the row's status to Delivered and is kept in the reader's browser only; procurement.json is not touched. tools/verify_delivery_checklist.cj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
